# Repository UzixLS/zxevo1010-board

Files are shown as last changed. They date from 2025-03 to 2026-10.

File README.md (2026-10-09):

## ZXEVO.1010
10x10cm 2-layer PCB variant of [ZX Evolution](http://nedopc.com/zxevo/zxevo.php) project

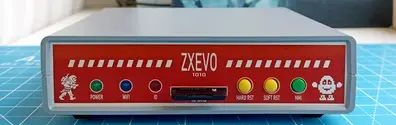
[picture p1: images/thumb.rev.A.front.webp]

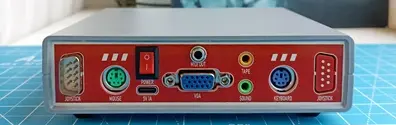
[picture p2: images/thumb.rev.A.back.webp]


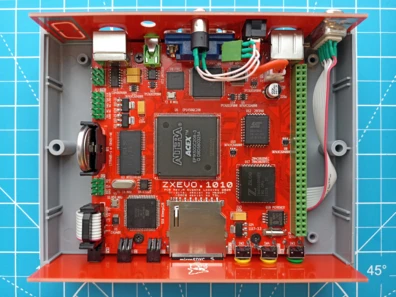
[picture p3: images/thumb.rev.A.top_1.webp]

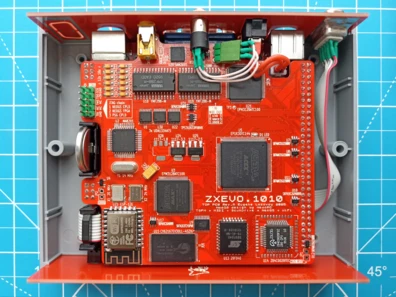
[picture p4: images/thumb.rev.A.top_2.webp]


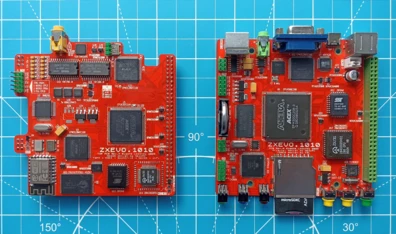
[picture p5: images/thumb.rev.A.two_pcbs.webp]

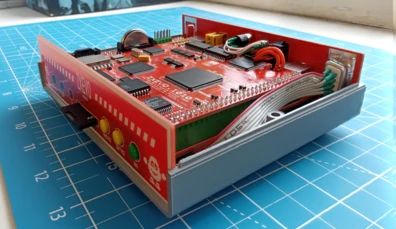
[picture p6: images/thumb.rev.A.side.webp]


Some random photos: [link](https://cloud.err200.net/index.php/s/73TR85tYZkMm8Ax?path=%2Fzxevo1010)

Tech specs:
- Fully compatible with ZX Evolution revC
- SD/microSD card slot
- PS/2 keyboard and mouse ports
- VGA video output
- VDAC2
- TSFM (mono output) powered by 2xYMF288
- [NeoGS](http://nedopc.com/gs/ngs.php)
- SounDrive (4-channel stereo covox)
- MIDI onboard synthesizer and output for external synthesizer
- WiFi ([ZiFi](http://zifi.vtrd.in/))
- RTC
- Tape input via 3.5 jack
- 1xDB-9 port for Sega-compatible joysticks
- USB Type C power supply
- Board optimized for G738 and G706 cases

### Changelog
#### Main PCB
* Rev.A - first release
* Rev.A1: - see [ERRATA](pcb_main/rev.A1/ERRATA.txt)!
    * enlarged ACEX's footprint
    * fixed IO led always on in baseconf - added C92 and D7
    * changed R66 from 390Ω to 2.2kΩ to reduce power led bightness
    * changed R52 and R58 from 27kΩ to 18kΩ for better VDAC2 mixing volume
    * slightly moved U18
    * some minor changes

#### Top PCB
* Rev.A - first release
* Rev.A1:
    * added 51Ω R1 and R3 on DAC and MP3 clock signals to fix signal integrity issues
    * changed U9 from SN74LXC8T245PWR (which is unsuitable) to 74LVC245APW
    * changed R7 from 120Ω to 1kΩ to decrease LED brightness
    * changed R26 and R29 from 8.2kΩ to 18kΩ for better NeoGS mixing volume
    * changed R23 and R31 from 22kΩ to 15kΩ for better MIDI mixing volume
    * changed R65, R66, R67 and R68 from 8.2kΩ to 3.3kΩ for better PSG mixing volume (but this makes FM a unbalancy loud unfortunatelly)
    * added R50, R51, R61, C102, C103, C104 for VS10xx MP3 decoder
    * fixed swapped left-right sound channels
    * increased cutoff for CR2032 holder

### Useful software
* NedoOS (BaseConf): http://nedoos.ru/
* Wild Commander (TSConf): https://forum.tslabs.info/viewtopic.php?f=26&t=143
* ZiFi WiFi client (TSConf): http://zifi.vtrd.in/
* TSConf software library: https://prods.tslabs.info/
* Joystick configuration utility (TSConf): https://github.com/tslabs/zx-evo/tree/master/pentevo/soft/avrconf

### References
* ZX Evolution official site: http://nedopc.com/zxevo/zxevo.php

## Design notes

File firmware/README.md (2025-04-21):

# Main PCB

## AVR firmware (for ISP programmer)
### Fuses
- low  - 0x3F
- high - 0x88
- ext  - 0xFF
- lock - 0xEF

### Bootloader
- zxevo_bl.hex - flash
- zxevo_bl.e2p - eeprom

Link: http://nedopc.com/zxevo/zxevo.php

## AVR firmware (for bootloader via USB/SD card)
### Test & Service
- zxevo_fw_tns_vdac2.bin

Link: https://github.com/tslabs/zx-evo/blob/master/pentevo/test_n_service/trunk/

### BaseConf + TSConf
- zxevo_fw_vdac2.bin

Link: https://github.com/tslabs/zx-evo/blob/master/pentevo/avr/current/default/

## ROM
### BaseConf
- zxevo_fe.rom

Link: http://nedopc.com/zxevo/zxevo.php

### TSConf
Install on top of BaseConf
- ts-bios.rom

Link: https://github.com/tslabs/zx-evo/tree/master/pentevo/rom/bin

## VDAC CPLD firmware
- ide-video.pof

Link: https://github.com/tslabs/zx-evo/blob/master/pentevo/vdac/vdac2/cpld/output_files/

# Top PCB
## NeoGS ROM
**Flash before soldering!**
- full_ngs.rom

Link: http://nedopc.com/gs/ngs.php

## NeoGS CPLD firmware
- GS_cpld_3064.pof - for EPM3064ATC100
- GS_cpld_3128.pof - for EPM3128ATC100

Link: http://nedopc.com/gs/ngs.php

## PSG CPLD firmware
- psg-sound.pof

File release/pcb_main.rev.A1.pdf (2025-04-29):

1 | 2 | 3 | 4 | 5 | 6 | 7 | 8 | 9 | 10 | 11 | 12

A

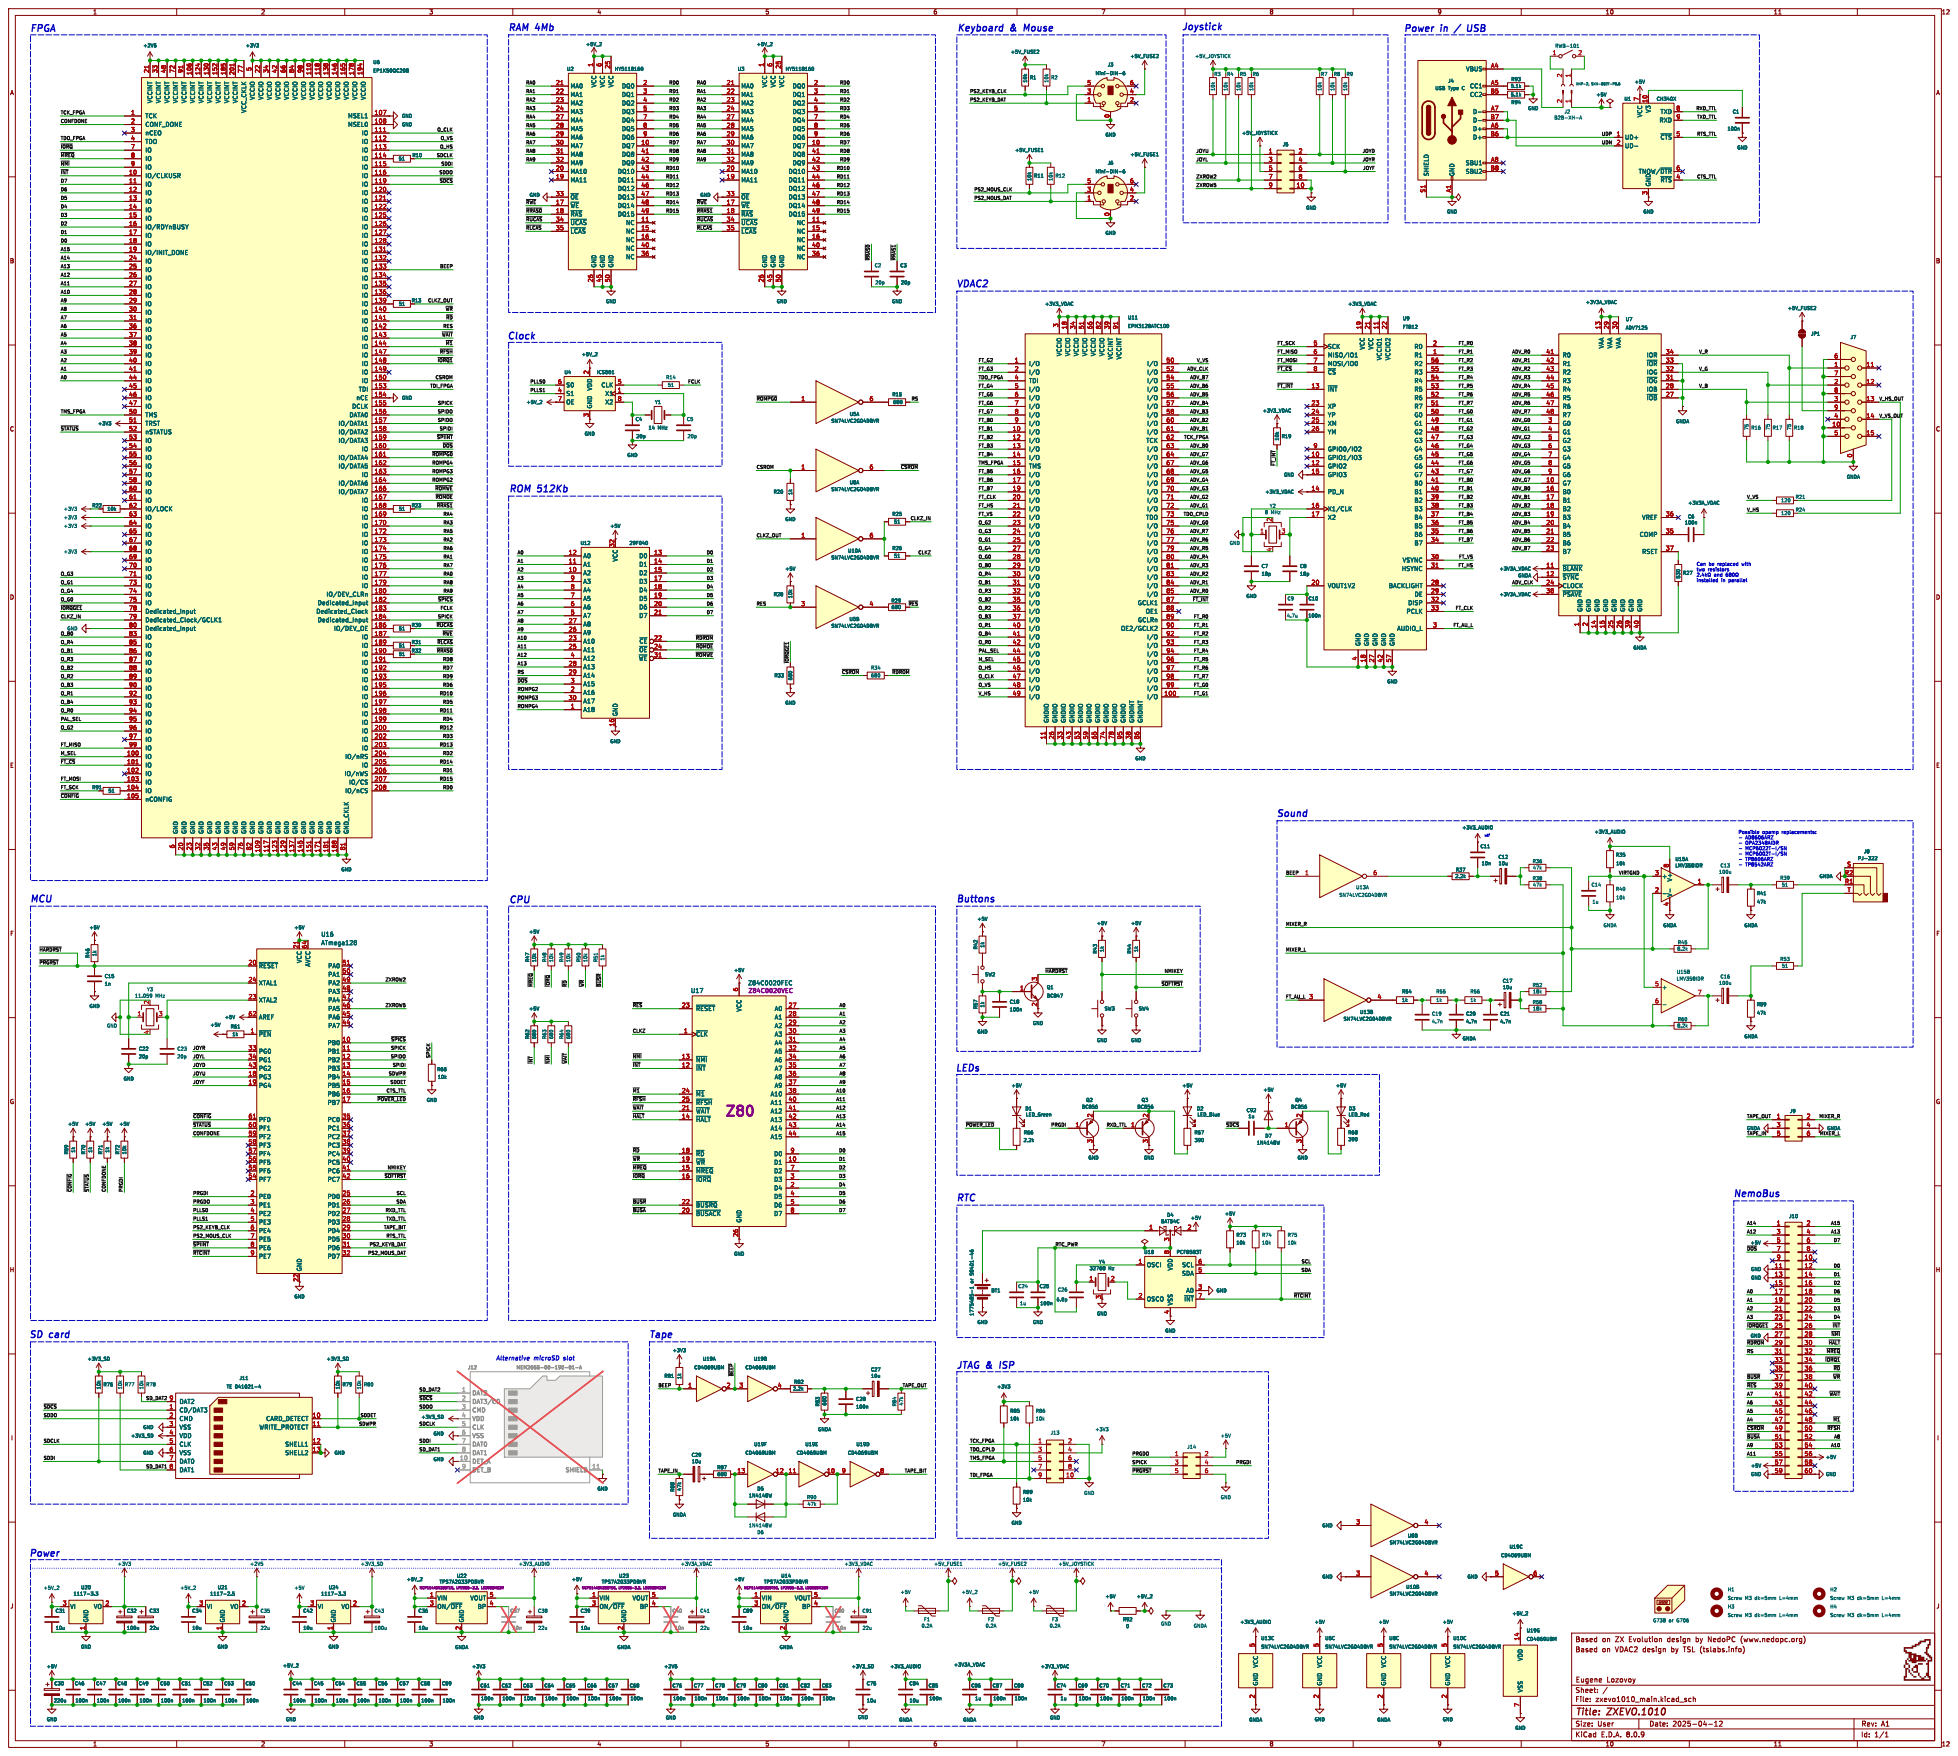
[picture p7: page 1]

1 DQ7 10 NC 11 NC 15 NC 16 ~{WE} 17 ~{RAS} 18 DQ0 2 MA0 21 MA1 22 MA2 23 MA3 24 VCC 25 GND 26 MA4 27 MA5 28 MA6 29 DQ1 3 MA7 30 MA8 31 MA9 32 ~{OE} 33 ~{UCAS} 34 ~{LCAS} 35 NC 36 DQ2 4 NC 40 DQ8 41 DQ9 42 DQ10 43 DQ11 44 GND 45 DQ12 46 DQ13 47 DQ14 48 DQ15 49 DQ3 5 GND 50 VCC

IO 200 VCCINT 201

IO 193 VCCIO ¹⁹⁴ IO 195

3 ~{RTS}4 ~{CTS}5 TNOW/~{DTR}6 VCC
RTS_TTL CTS_TTL

3 S1 4 CLK 5 S0 6 OE 7 X2 8 GND GND

two resistors þÿ2.4k©and þÿ680©

2 ON/~{OFF} 3 BP 4 VOUT 5 U22 TPS7A2033PDBVR

2 ON/~{OFF} 3 BP 4 VOUT 5 U23 TPS7A2033PDBVR

2 ON/~{OFF} 3 BP 4 VOUT 5 U14 TPS7A2033PDBVR

2 ON/~{OFF} 3 BP 4 VOUT 5 C39

2 ON/~{OFF} 3 BP 4 VOUT 5

1 | 2 | 3 | 4 | 5 | 6

A

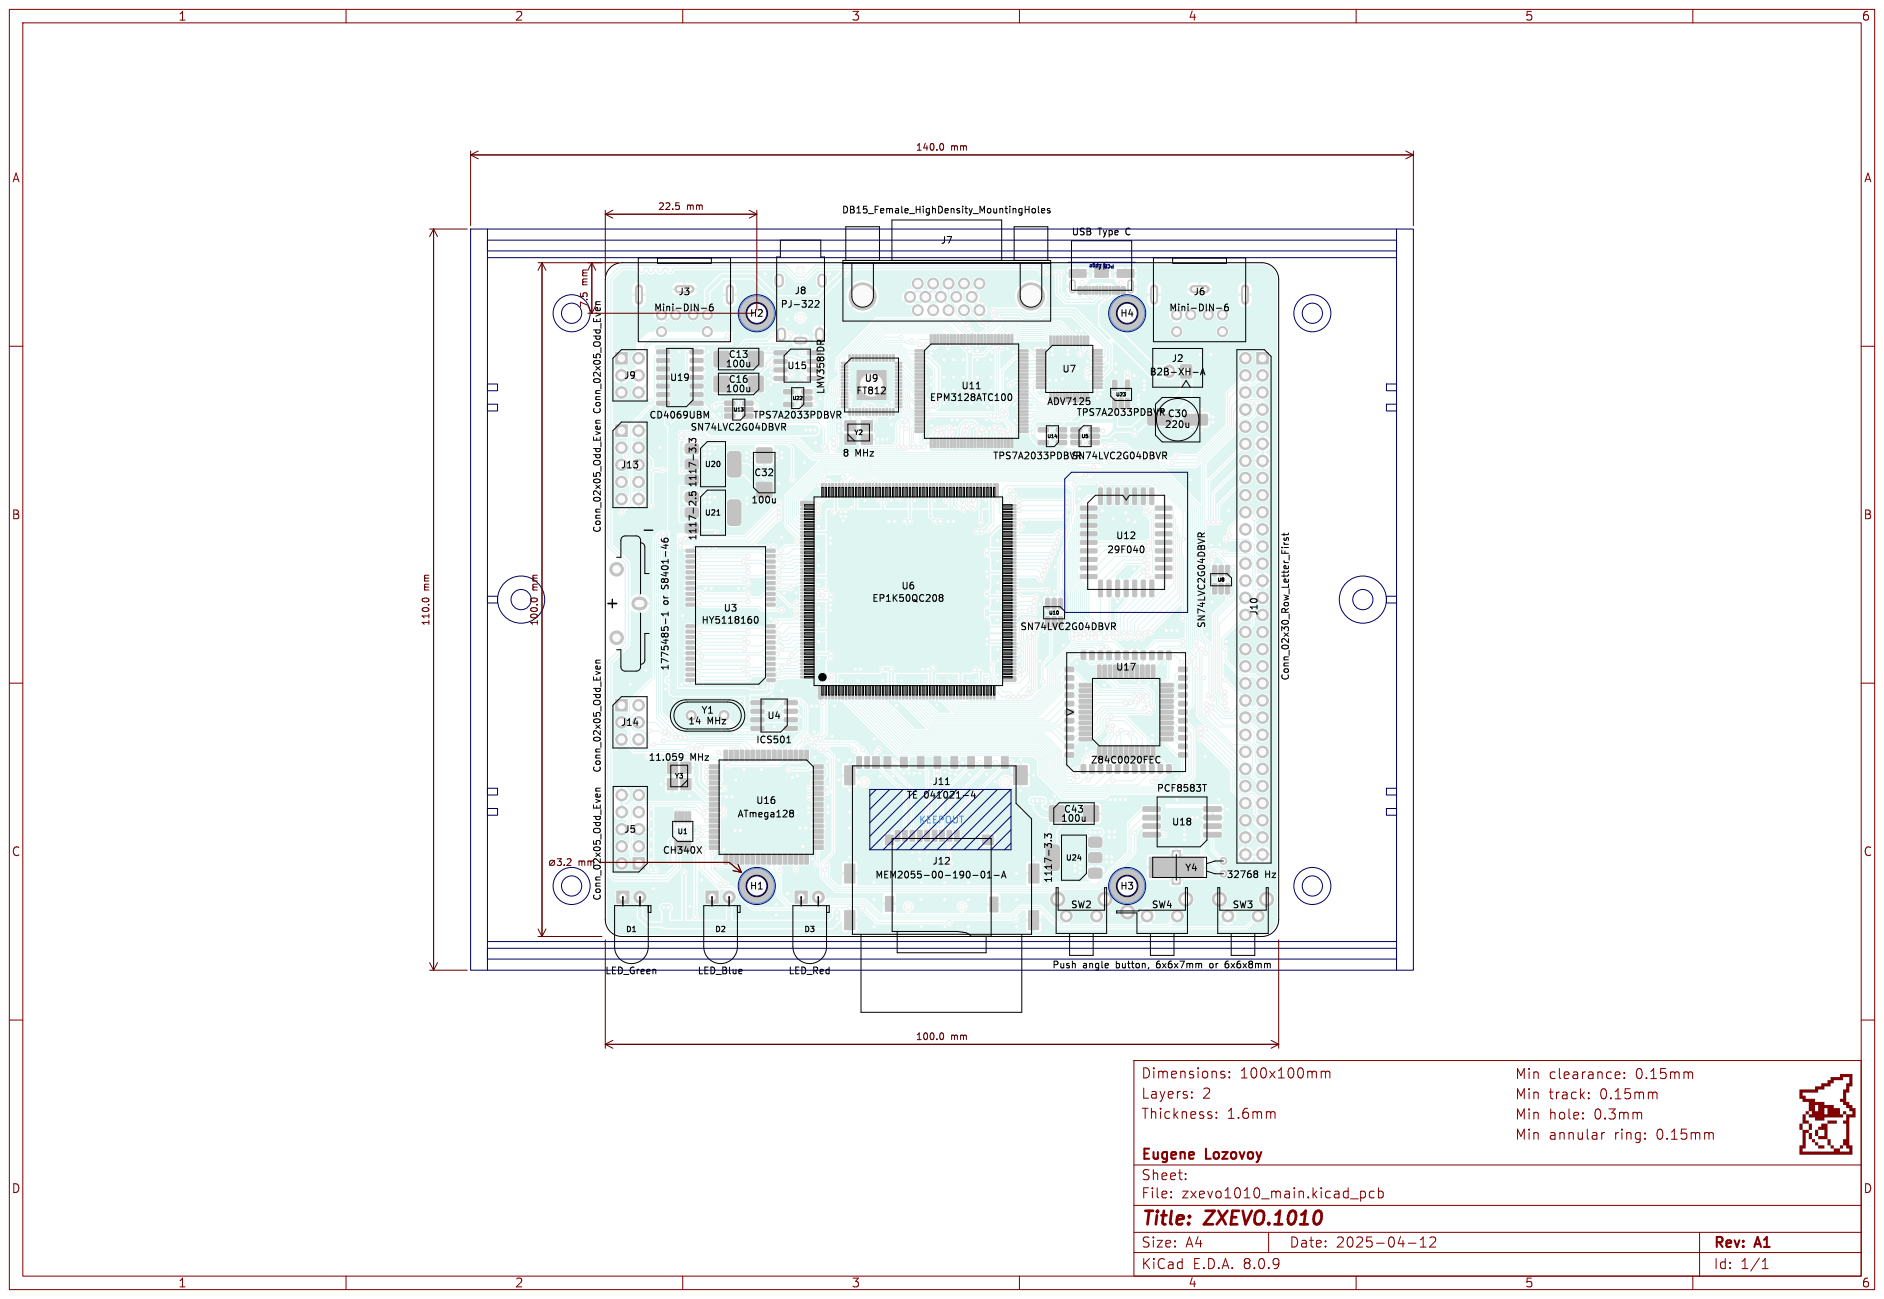
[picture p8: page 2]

J11 ¹⁷⁷⁵⁴⁸⁵⁻¹ or S⁸⁴⁰¹⁻⁴⁶

1 | 2 | 3 | 4 | 5 | 6

A

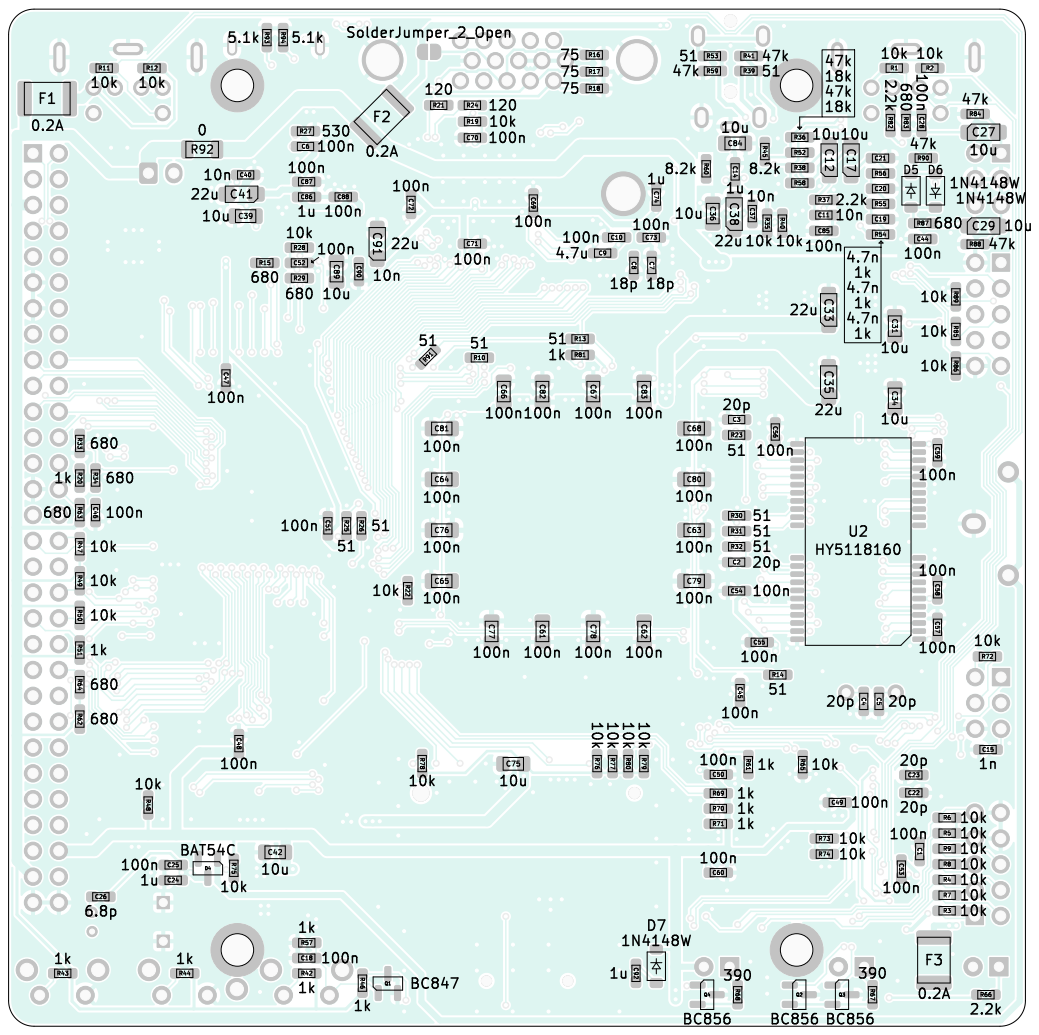
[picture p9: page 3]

# Bill Of Materials

References | | | Value | Footprint | Qty
BT1 | 1775485-1 or S8401-46 | my:CR2032V | 1
C1 C6 C10 C18 C25 C28 C44 C45 C46 C47 C48 C49 C50 C51 C52 C53 C54 C55 C56 C57 C58 C59 C60 C69 C70 C71 C72 C73 C85 C87 C88 | 100n | Capacitor_SMD:C_0603_1608Metric_Pad1.0 8x0.95mm_HandSolder | 31
C2 C3 C4 C5 C22 C23 | 20p | Capacitor_SMD:C_0603_1608Metric_Pad1.0 8x0.95mm_HandSolder | 6
C7 C8 | 18p | Capacitor_SMD:C_0603_1608Metric_Pad1.0 8x0.95mm_HandSolder | 2
C9 | 4.7u | Capacitor_SMD:C_0603_1608Metric_Pad1.0 8x0.95mm_HandSolder | 1
C11 C37 C40 C90 | 10n | Capacitor_SMD:C_0603_1608Metric_Pad1.0 8x0.95mm_HandSolder | 4
C12 C17 C27 C29 | 10u | Capacitor_Tantalum_SMD:CP_EIA-3216-18_ Kemet-A_Pad1.58x1.35mm_HandSolder | 4
C13 C16 C32 C43 | 100u | Capacitor_Tantalum_SMD:CP_EIA-6032-28_ Kemet-C_Pad2.25x2.35mm_HandSolder | 4
C14 C24 C74 C86 C92 | 1u | Capacitor_SMD:C_0603_1608Metric_Pad1.0 8x0.95mm_HandSolder | 5
C15 | 1n | Capacitor_SMD:C_0603_1608Metric_Pad1.0 8x0.95mm_HandSolder | 1
C19 C20 C21 | 4.7n | Capacitor_SMD:C_0603_1608Metric_Pad1.0 8x0.95mm_HandSolder | 3
C26 | 6.8p | Capacitor_SMD:C_0603_1608Metric_Pad1.0 8x0.95mm_HandSolder | 1
C30 | 220u | Capacitor_SMD:CP_Elec_6.3x7.7 | 1
C31 C34 C36 C39 C42 C75 C84 C89 | 10u | Capacitor_SMD:C_0805_2012Metric_Pad1.1 8x1.45mm_HandSolder | 8
C33 C35 C38 C41 C91 | 22u | Capacitor_Tantalum_SMD:CP_EIA-3216-18_ Kemet-A_Pad1.58x1.35mm_HandSolder | 5
C61 C62 C63 C64 C65 C66 C67 C68 C76 C77 C78 C79 C80 C81 C82 C83 | 100n | Capacitor_SMD:C_0805_2012Metric_Pad1.1 8x1.45mm_HandSolder | 16
D1 | LED_Green | LED_THT:LED_D5.0mm_Horizontal_O1.27m m_Z3.0mm | 1
D2 | LED_Blue | LED_THT:LED_D5.0mm_Horizontal_O1.27m m_Z3.0mm | 1
D3 | LED_Red | LED_THT:LED_D5.0mm_Horizontal_O1.27m m_Z3.0mm | 1
D4 | BAT54C | Package_TO_SOT_SMD:SOT-23 | 1
D5 D6 D7 | 1N4148W | Diode_SMD:D_SOD-123 | 3
F1 F2 F3 | 0.2A | Fuse:Fuse_1812_4532Metric_Pad1.30x3.40 mm_HandSolder | 3
H1 H2 H3 H4 | Screw M3 dk=5mm L=4mm | my:MountingHole_3.2mm_M3_dk5.2mm_Ma sk | 4
J1 | XHP-2, SXH-002T-P0.6 | | 1

# zxevo1010_main rev.A1 BOM page 1/3

J2 | B2B-XH-A | Connector_JST:JST_XH_B2B-XH-A_1x02_P 2.50mm_Vertical | 1
J3 J6 | Mini-DIN-6 | my:minidin-6 | 2
J4 | USB Type C | my:USB_C_Receptacle_HRO_TYPE-C-31-M -12_dangling | 1
J5 J13 | Conn_02x05_Odd_Even | Connector_PinHeader_2.54mm:PinHeader_2 x05_P2.54mm_Vertical | 2
J7 | DB15_Female_HighDensity_Mounti ngHoles | Connector_Dsub:DSUB-15-HD_Female_Hori zontal_P2.29x1.98mm_EdgePinOffset3.03m m_Housed_MountingHolesOffset4.94mm | 1
J8 | PJ-322 | my:PJ-322 | 1
J9 J14 | Conn_02x05_Odd_Even | Connector_PinHeader_2.54mm:PinHeader_2 x03_P2.54mm_Vertical | 2
J10 | Conn_02x30_Row_Letter_First | Connector_PinSocket_2.54mm:PinSocket_2x 30_P2.54mm_Vertical | 1
J11 | TE 041021-4 | my:SD_TE_2041021-mod | 1
N1 | G738 or G706 | my:g738-g706 | 1
Q1 | BC847 | Package_TO_SOT_SMD:SOT-23 | 1
Q2 Q3 Q4 | BC856 | Package_TO_SOT_SMD:SOT-23 | 3
R1 R2 R3 R4 R5 R6 R7 R8 R9 R11 R12 R19 R22 R28 R35 R40 R47 R48 R49 R50 R65 R72 R73 R74 R75 R76 R77 R78 R79 R80 R85 R86 R89 | 10k | Resistor_SMD:R_0603_1608Metric_Pad0.98 x0.95mm_HandSolder | 33
R10 R13 R14 R23 R25 R26 R30 R31 R32 R39 R53 R91 | 51 | Resistor_SMD:R_0603_1608Metric_Pad0.98 x0.95mm_HandSolder | 12
R15 R29 R33 R34 R62 R63 R64 R83 R87 | 680 | Resistor_SMD:R_0603_1608Metric_Pad0.98 x0.95mm_HandSolder | 9
R16 R17 R18 | 75 | Resistor_SMD:R_0603_1608Metric_Pad0.98 x0.95mm_HandSolder | 3
R20 R42 R43 R44 R46 R51 R54 R55 R56 R57 R61 R69 R70 R71 R81 | 1k | Resistor_SMD:R_0603_1608Metric_Pad0.98 x0.95mm_HandSolder | 15
R21 R24 | 120 | Resistor_SMD:R_0603_1608Metric_Pad0.98 x0.95mm_HandSolder | 2
R27 | 530 | Resistor_SMD:R_0603_1608Metric_Pad0.98 x0.95mm_HandSolder | 1
R36 R38 R41 R59 R84 R88 R90 | 47k | Resistor_SMD:R_0603_1608Metric_Pad0.98 x0.95mm_HandSolder | 7
R37 R66 R82 | 2.2k | Resistor_SMD:R_0603_1608Metric_Pad0.98 x0.95mm_HandSolder | 3
R45 R60 | 8.2k | Resistor_SMD:R_0603_1608Metric_Pad0.98 x0.95mm_HandSolder | 2
R52 R58 | 18k | Resistor_SMD:R_0603_1608Metric_Pad0.98 x0.95mm_HandSolder | 2
R67 R68 | 390 | Resistor_SMD:R_0603_1608Metric_Pad0.98 x0.95mm_HandSolder | 2
R92 | 0 | Resistor_SMD:R_1206_3216Metric | 1
R93 R94 | 5.1k | Resistor_SMD:R_0603_1608Metric_Pad0.98 x0.95mm_HandSolder | 2
SW1 | RWB-101 | | 1

# zxevo1010_main rev.A1 BOM page 2/3

SW2 SW3 SW4 | Push angle button, 6x6x7mm or 6x6x8mm | Button_Switch_THT:SW_Tactile_SPST_Angl ed_PTS645Vx58-2LFS | 3
U1 | CH340X | Package_SO:MSOP-10_3x3mm_P0.5mm | 1
U2 U3 | HY5118160 | my:TSOP-II-44-50_P0.8mm | 2
U4 | ICS501 | Package_SO:SOIC-8_3.9x4.9mm_P1.27mm | 1
U5 U8 U10 U13 | SN74LVC2G04DBVR | Package_TO_SOT_SMD:SOT-23-6_Handsol dering | 4
U6 | EP1K50QC208 | my:PQFP-208_28x28mm_P0.5mm_LongPad s | 1
U7 | ADV7125 | Package_QFP:TQFP-48_7x7mm_P0.5mm | 1
U9 | FT812 | my:QFN-56-1EP_8x8mm_P0.5mm_EP4.3x4. 3mm | 1
U11 | EPM3128ATC100 | Package_QFP:TQFP-100_14x14mm_P0.5m m | 1
U12 | 29F040 | my:PLCC-32_11.4x14.0mm_P1.27mm-longp ads | 1
U14 U22 U23 | TPS7A2033PDBVR (Alternatives: NCP114ASN330T1G, LP2985-3.3, LD3985M33R) | Package_TO_SOT_SMD:SOT-23-5_HandSo ldering | 3
U15 | LMV358IDR | Package_SO:SOIC-8_3.9x4.9mm_P1.27mm | 1
U16 | ATmega128 | Package_QFP:TQFP-64_14x14mm_P0.8mm | 1
U17 | Z84C0020FEC (Alternatives: Z84C0020VEC) | my:Z80_FEC_VEC | 1
U18 | PCF8583T | my:SOT176-1 | 1
U19 | CD4069UBM | Package_SO:SO-14_3.9x8.65mm_P1.27mm | 1
U20 U24 | 1117-3.3 | Package_TO_SOT_SMD:SOT-223-3_TabPin 2 | 2
U21 | 1117-2.5 | Package_TO_SOT_SMD:SOT-223-3_TabPin 2 | 1
Y1 | 14 MHz | Crystal:Crystal_HC49-4H_Vertical | 1
Y2 | 8 MHz | my:Crystal_SMD_3225-4Pin_3.2x2.5mm_Ha ndSoldering | 1
Y3 | 11.059 MHz | my:Crystal_SMD_3225-4Pin_3.2x2.5mm_Ha ndSoldering | 1
Y4 | 32768 Hz | Crystal:Crystal_C38-LF_D3.0mm_L8.0mm_H orizontal_1EP_style2 | 1

# zxevo1010_main rev.A1 BOM page 3/3

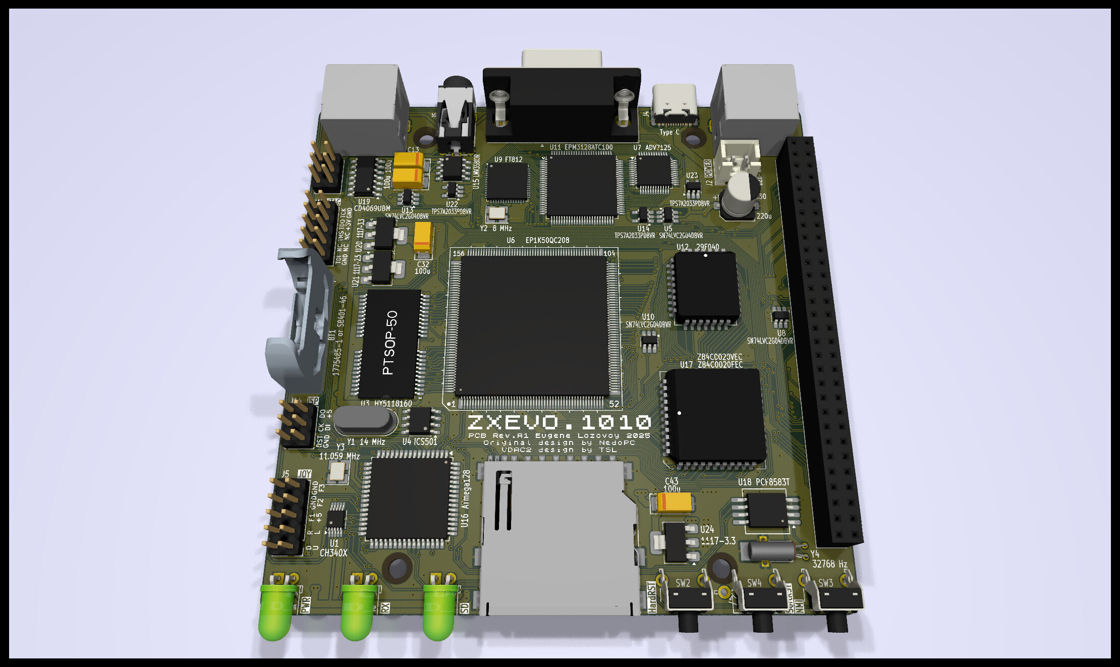
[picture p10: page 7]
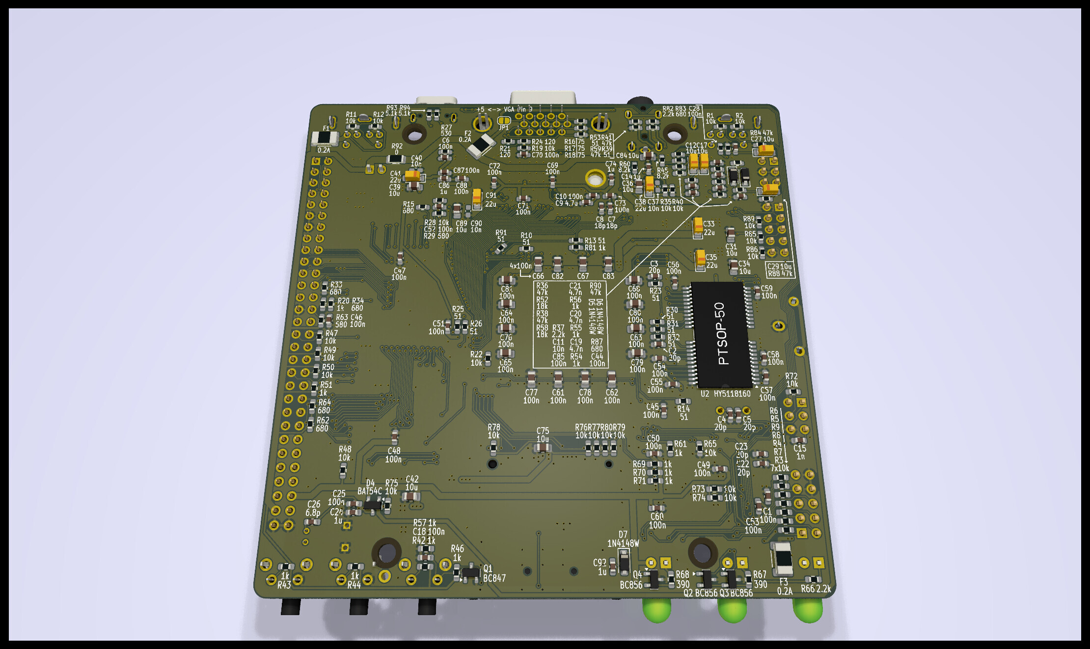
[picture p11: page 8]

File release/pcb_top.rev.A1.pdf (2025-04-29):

1 | 2 | 3 | 4 | 5 | 6 | 7 | 8 | 9 | 10

A

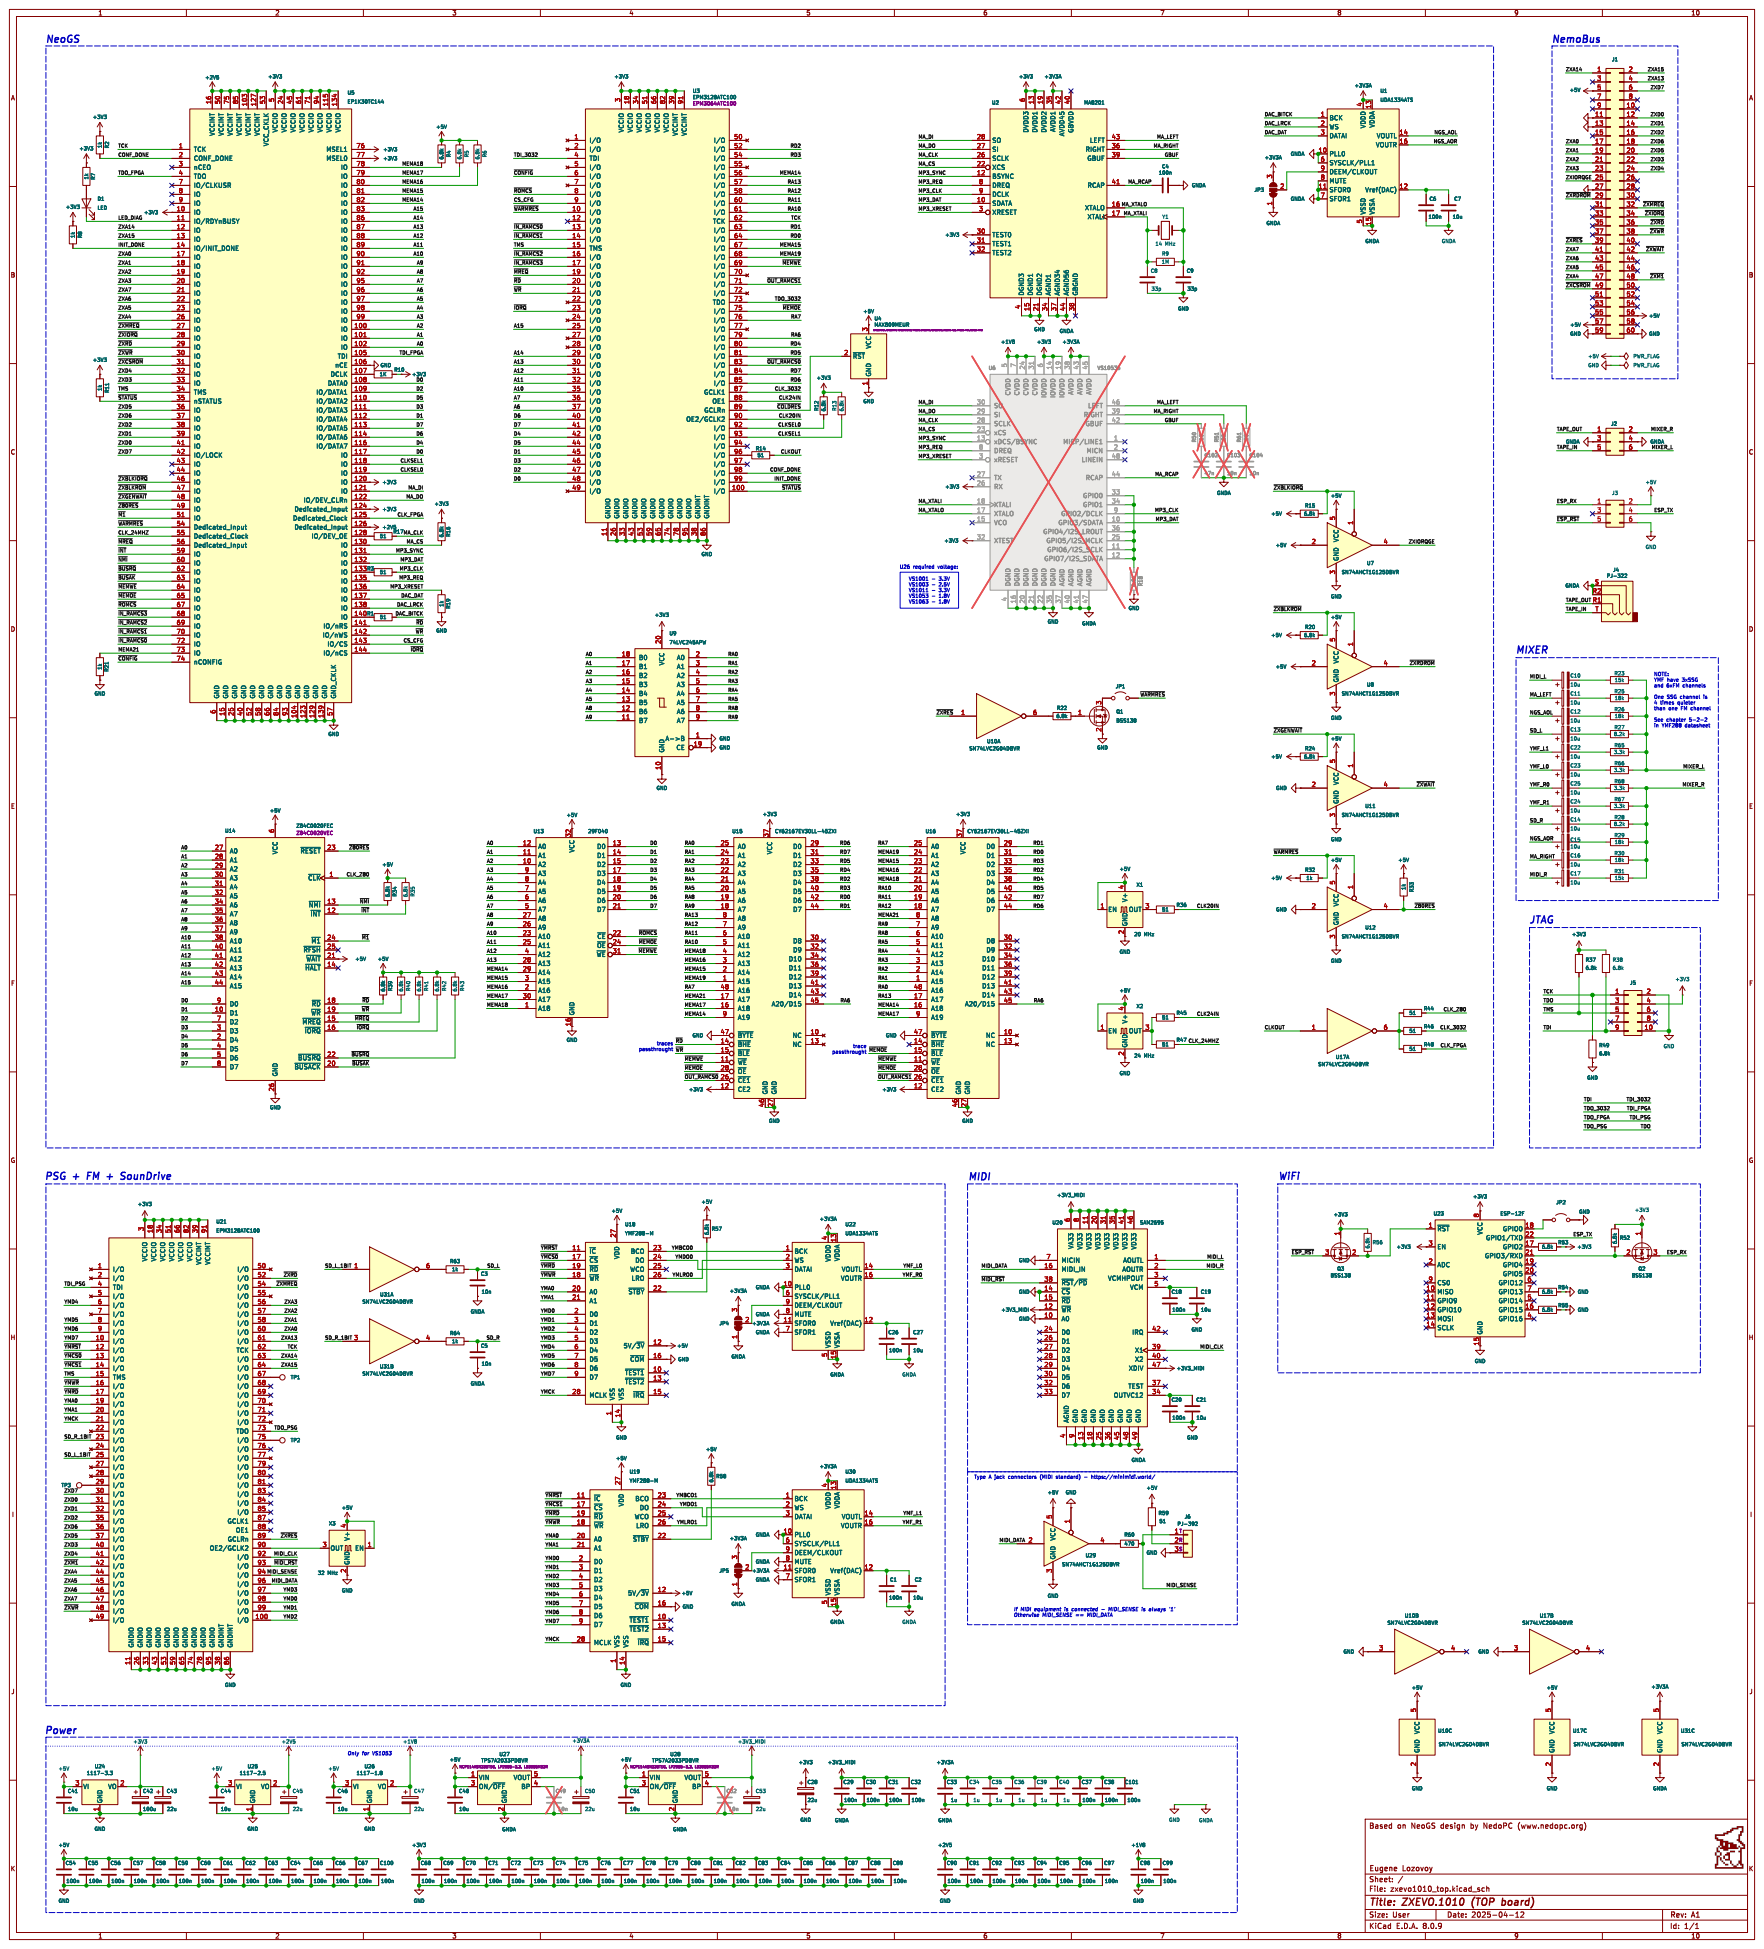
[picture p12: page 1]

RD5 CLKSEL0 ~{MEMWE} ~{INT} ~{BUSAK} ~{BUSRQ} ~{NMI}

7 DREQ 8 GPIO2/DCLK 9 U6 VS1053b GND GND

4 AGND 40 AGND 41 GBUF 42 AVDD 43 RCAP 44 AVDD 45 LEFT 46 AGND 47

6 D2 7 D7 8 D0 9 U15 CY62167EV30LL-45ZXI A15 1 NC 10 ~{WE} 11 CE2 12 NC 13 ~{BHE} 14 ~{BLE} 15 A18 16 A17 17 A7 18 A6 19 A14 2 A5 20 A4 21 A3 22 A2 23 A1 24 A0 25 ~{CE1} 26 GND 27
10n ⁶.8k R³⁵

TDO_FPGA CLK_FPGA
6.8k GND GND ~{RST} 1 MISO

5 SYSCLK/PLL1 6 SFOR1 7 MUTE 8 DEEM/CLKOUT 9 U22 UDA1334ATS C27

5 SYSCLK/PLL1 6 SFOR1 7 MUTE 8 DEEM/CLKOUT 9 C27

5 SYSCLK/PLL1 6 SFOR1 7 MUTE 8 DEEM/CLKOUT 9 U30 UDA1334ATS

5 SYSCLK/PLL1 6 SFOR1 7 MUTE 8 DEEM/CLKOUT 9

2 ON/~{OFF} 3 BP 4 VOUT 5 U27 TPS7A2033PDBVR

2 ON/~{OFF} 3 BP 4 VOUT 5 U28 TPS7A2033PDBVR

2 ON/~{OFF} 3 BP 4 VOUT 5 GNDA C48

2 ON/~{OFF} 3 BP 4 VOUT 5 GNDA C51

1 | 2 | 3 | 4 | 5 | 6

A

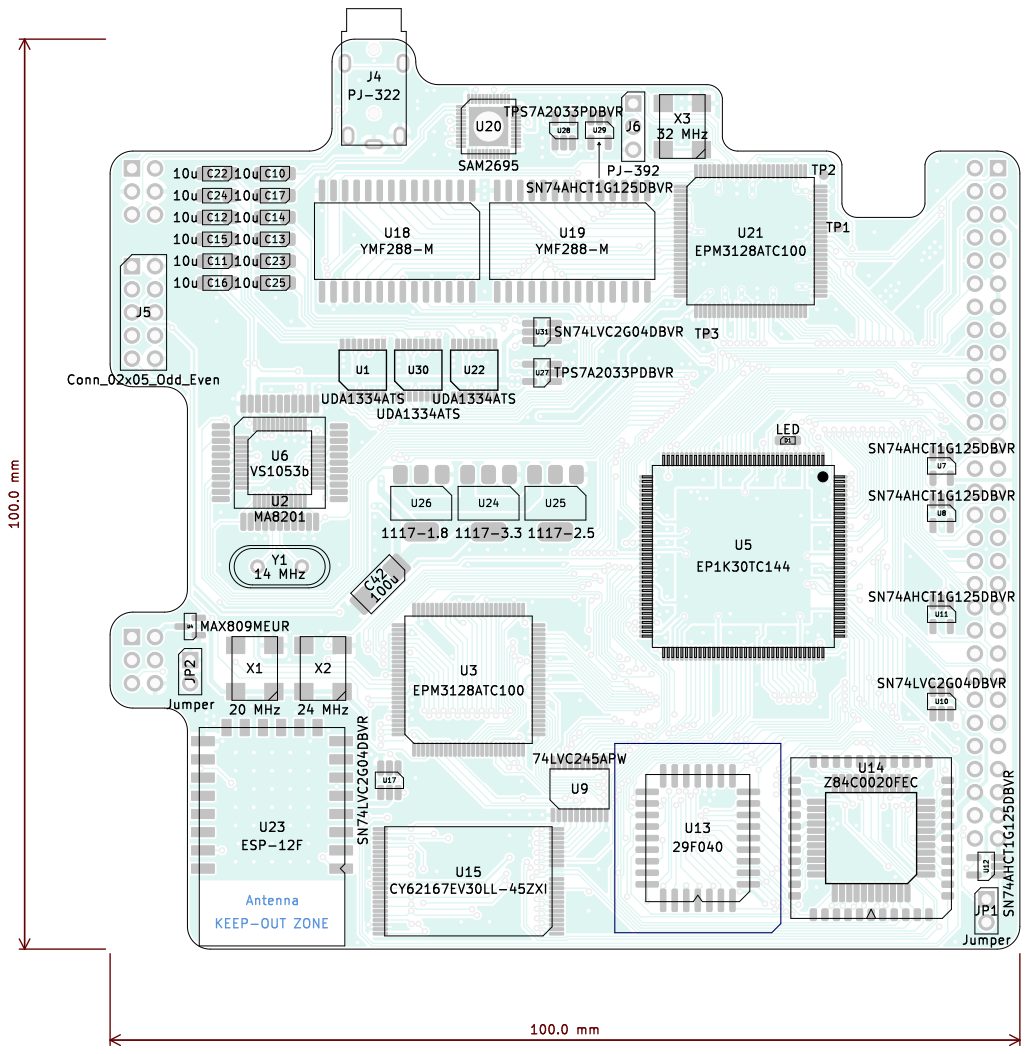
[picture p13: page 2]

24 MHz X2 KEEP-OUT ZONE

1 | 2 | 3 | 4 | 5 | 6

A

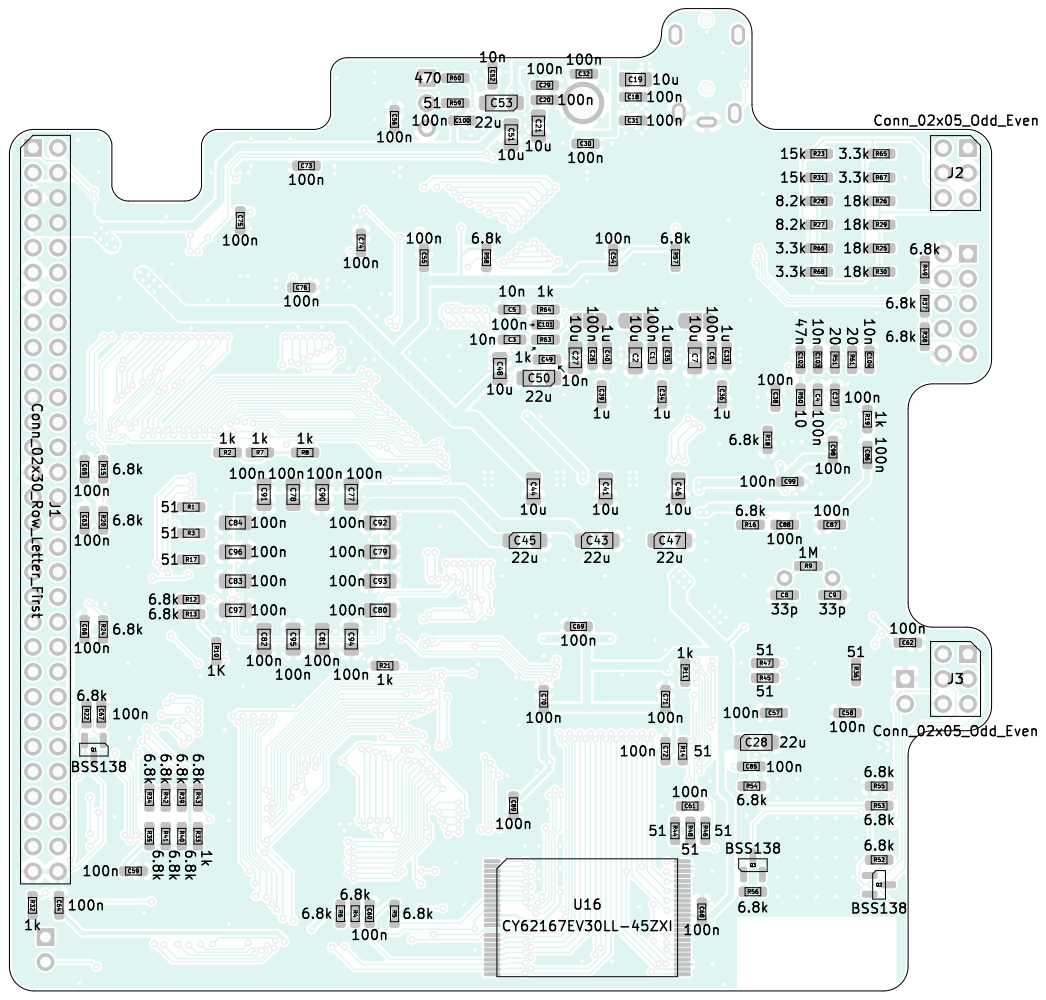
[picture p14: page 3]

# Bill Of Materials

References | | | Value | Footprint | Qty
C1 C4 C6 C18 C20 C26 C29 C30 C31 C32 C37 C38 C54 C55 C56 C57 C58 C59 C60 C61 C62 C63 C64 C65 C66 C67 C68 C69 C70 C71 C72 C73 C74 C75 C76 C85 C86 C87 C88 C89 C98 C99 C100 C101 | 100n | Capacitor_SMD:C_0603_1608Metric_Pad1.0 8x0.95mm_HandSolder | 44
C2 C7 C19 C21 C27 C41 C44 C46 C48 C51 | 10u | Capacitor_SMD:C_0805_2012Metric_Pad1.1 8x1.45mm_HandSolder | 10
C3 C5 C49 C52 C103 C104 | 10n | Capacitor_SMD:C_0603_1608Metric_Pad1.0 8x0.95mm_HandSolder | 6
C8 C9 | 33p | Capacitor_SMD:C_0603_1608Metric_Pad1.0 8x0.95mm_HandSolder | 2
C10 C11 C12 C13 C14 C15 C16 C17 C22 C23 C24 C25 | 10u | Capacitor_Tantalum_SMD:CP_EIA-3216-18_ Kemet-A_Pad1.58x1.35mm_HandSolder | 12
C28 C43 C45 C47 C50 C53 | 22u | Capacitor_Tantalum_SMD:CP_EIA-3216-18_ Kemet-A_Pad1.58x1.35mm_HandSolder | 6
C33 C34 C35 C36 C39 C40 | 1u | Capacitor_SMD:C_0603_1608Metric_Pad1.0 8x0.95mm_HandSolder | 6
C42 | 100u | Capacitor_Tantalum_SMD:CP_EIA-6032-28_ Kemet-C_Pad2.25x2.35mm_HandSolder | 1
C77 C78 C79 C80 C81 C82 C83 C84 C90 C91 C92 C93 C94 C95 C96 C97 | 100n | Capacitor_SMD:C_0805_2012Metric_Pad1.1 8x1.45mm_HandSolder | 16
C102 | 47n | Capacitor_SMD:C_0603_1608Metric_Pad1.0 8x0.95mm_HandSolder | 1
D1 | LED | LED_SMD:LED_0603_1608Metric_Pad1.05x 0.95mm_HandSolder | 1
J1 | Conn_02x30_Row_Letter_First | Connector_PinHeader_2.54mm:PinHeader_2 x30_P2.54mm_Vertical | 1
J2 J3 | Conn_02x05_Odd_Even | Connector_PinSocket_2.54mm:PinSocket_2x 03_P2.54mm_Vertical | 2
J4 | PJ-322 | my:PJ-322 | 1
J5 | Conn_02x05_Odd_Even | Connector_PinHeader_2.54mm:PinHeader_2 x05_P2.54mm_Vertical | 1
J6 | PJ-392 | Connector_PinHeader_2.54mm:PinHeader_1 x03_P2.54mm_Vertical | 1
Q1 Q2 Q3 | BSS138 | Package_TO_SOT_SMD:SOT-23 | 3
R1 R3 R14 R17 R36 R44 R45 R46 R47 R48 R59 | 51 | Resistor_SMD:R_0603_1608Metric_Pad0.98 x0.95mm_HandSolder | 11
R2 R7 R8 R11 R19 R21 R32 R33 R63 R64 | 1k | Resistor_SMD:R_0603_1608Metric_Pad0.98 x0.95mm_HandSolder | 10
R4 R5 R6 R12 R13 R15 R16 R18 R20 R22 R24 R34 R35 R37 R38 R39 R40 R41 R42 R43 R49 R52 R53 R54 R55 R56 R57 R58 | 6.8k | Resistor_SMD:R_0603_1608Metric_Pad0.98 x0.95mm_HandSolder | 28
R9 | 1M | Resistor_SMD:R_0603_1608Metric_Pad0.98 x0.95mm_HandSolder | 1
R10 | 1K | Resistor_SMD:R_0603_1608Metric_Pad0.98 x0.95mm_HandSolder

# zxevo1010_top rev.A1 BOM page 1/3

R23 R31 | 15k | Resistor_SMD:R_0603_1608Metric_Pad0.98 x0.95mm_HandSolder
R25 R26 R29 R30 | 18k | Resistor_SMD:R_0603_1608Metric_Pad0.98 x0.95mm_HandSolder
R27 R28 | 8.2k | Resistor_SMD:R_0603_1608Metric_Pad0.98 x0.95mm_HandSolder | 2
R50 | 10 | Resistor_SMD:R_0603_1608Metric_Pad0.98 x0.95mm_HandSolder | 1
R51 R61 | 20 | Resistor_SMD:R_0603_1608Metric_Pad0.98 x0.95mm_HandSolder | 2
R60 | 470 | Resistor_SMD:R_0603_1608Metric_Pad0.98 x0.95mm_HandSolder | 1
R65 R66 R67 R68 | 3.3k | Resistor_SMD:R_0603_1608Metric_Pad0.98 x0.95mm_HandSolder | 4
U1 U22 U30 | UDA1334ATS | Package_SO:SSOP-16_4.4x5.2mm_P0.65m m | 3
U2 | MA8201 | Package_QFP:MQFP-44_10x10mm_P0.8m m | 1
U3 U21 | EPM3128ATC100 (Alternatives: EPM3064ATC100) | Package_QFP:TQFP-100_14x14mm_P0.5m m | 2
U4 | MAX809MEUR (Alternatives: STM809MWX6F, ADM809MART, TCM809MENB713, TPV809M, CAT809MTBI, CBM809MST3, LM809M3-4.38, APX809S-44SA, SGM809-MXN3) | Package_TO_SOT_SMD:SOT-23 | 1
U5 | EP1K30TC144 | PCM_Package_QFP_AKL:TQFP-144_20x20 mm_P0.5mm | 1
U6 | VS1053b (Alternatives: VS1001, VS1003, VS1011, VS1063) | Package_QFP:LQFP-48_7x7mm_P0.5mm | 1
U7 U8 U11 U12 U29 | SN74AHCT1G125DBVR | Package_TO_SOT_SMD:SOT-23-5_HandSo ldering | 5
U9 | 74LVC245APW | Package_SO:TSSOP-20_4.4x6.5mm_P0.65 mm | 1
U10 U17 U31 | SN74LVC2G04DBVR | Package_TO_SOT_SMD:SOT-23-6_Handsol dering | 3
U13 | 29F040 | my:PLCC-32_11.4x14.0mm_P1.27mm-longp ads | 1
U14 | Z84C0020FEC (Alternatives: Z84C0020VEC) | my:Z80_FEC_VEC | 1
U15 U16 | CY62167EV30LL-45ZXI | Package_SO:TSOP-I-48_18.4x12mm_P0.5m m | 2
U18 U19 | YMF288-M | Package_SO:SOP-28_8.4x18.16mm_P1.27 mm | 2
U20 | SAM2695 | my:QFN-48-1EP_6x6mm_P0.4mm_EP4.2x4. 2mm | 1
U23 | ESP-12F | RF_Module:ESP-12E | 1
U24 | 1117-3.3 | Package_TO_SOT_SMD:SOT-223-3_TabPin 2 | 1
U25 | 1117-2.5 | Package_TO_SOT_SMD:SOT-223-3_TabPin 2 | 1
U26 | 1117-1.8 | Package_TO_SOT_SMD:SOT-223-3_TabPin

# zxevo1010_top rev.A1 BOM page 2/3

U27 U28 | TPS7A2033PDBVR (Alternatives: NCP114ASN330T1G, LP2985-3.3, LD3985M33R) | Package_TO_SOT_SMD:SOT-23-5_HandSo ldering
X1 | 20 MHz | my:Oscillator_SMD_7050_7.0x5.0mm | 1
X2 | 24 MHz | my:Oscillator_SMD_7050_7.0x5.0mm | 1
X3 | 32 MHz | my:Oscillator_SMD_7050_7.0x5.0mm | 1
Y1 | 14 MHz | Crystal:Crystal_HC49-4H_Vertical | 1

# zxevo1010_top rev.A1 BOM page 3/3

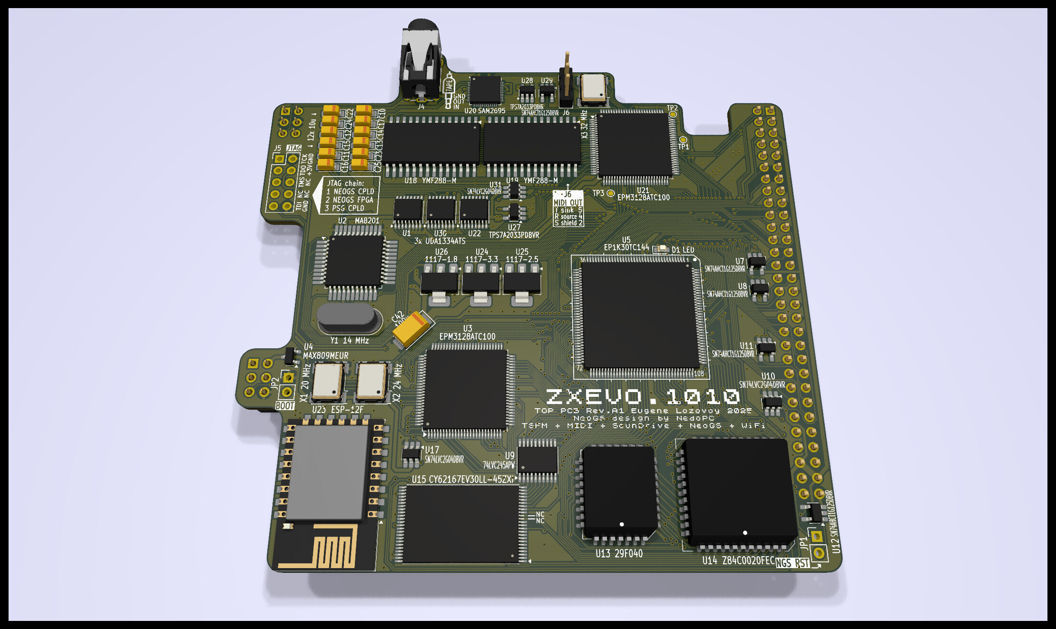
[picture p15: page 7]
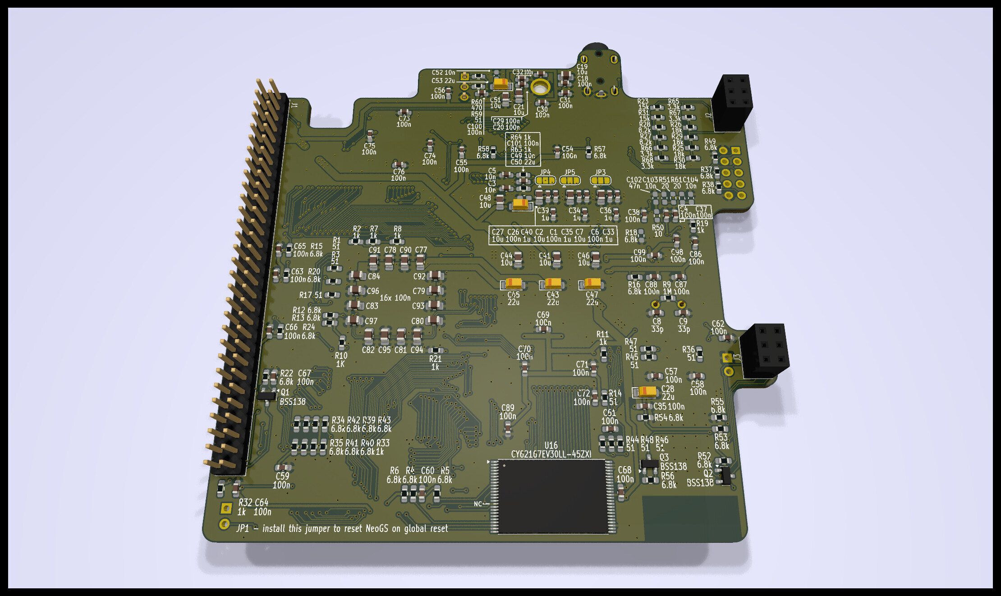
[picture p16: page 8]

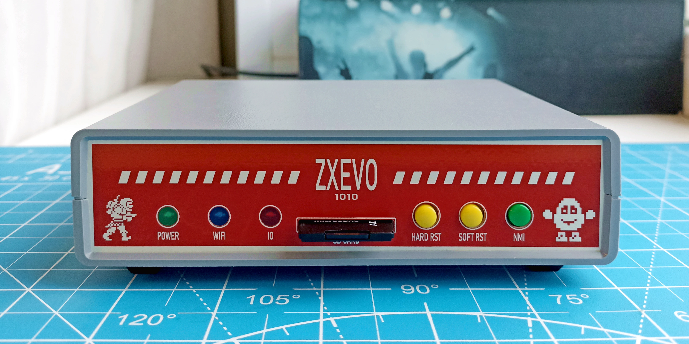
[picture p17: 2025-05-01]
images/rev.A.front.webp

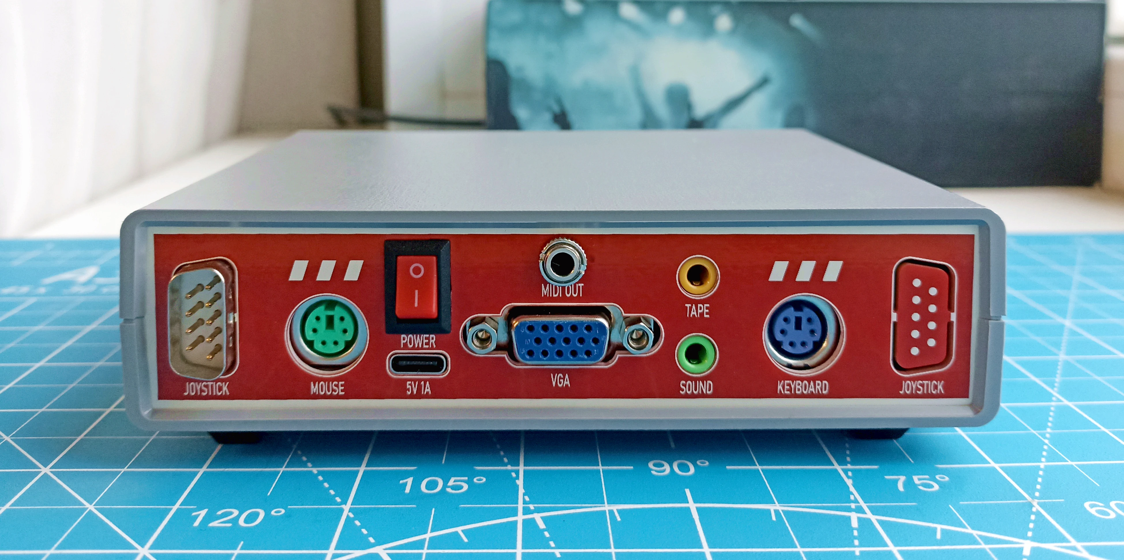
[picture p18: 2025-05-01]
images/rev.A.back.webp

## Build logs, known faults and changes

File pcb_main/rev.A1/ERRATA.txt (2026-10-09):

- Add 4.7 kΩ resistor between pins 2 and 3 of U13 (74LVC2G04) to fix audio noise.

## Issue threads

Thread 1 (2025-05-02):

YMF288

NS-Clone, 2025-05-02:
тааак
вангую что мы получили еще один вариант TSFM-а...

яж надеюсь ты тупо не выкинул 6 каналов от 2608 итд?
хотя можно было перехватить запись и проимитировать 2х 2203 и на одном ymf288...

чего там получаетсо с выбором второй половины чипа?

чего с этим пином для выбора 2608\288
и чего оно делаит хоть?

я так понимаю adpcm drums на 288 набортные без внешнего рома?

и еще один феил это балансировка sgg и fm частей
которая не будет соответствовать tsfm-ной
и теперь в плееры надо будет завозить дополнительный вариант 288-й балансировки громкостей

нам даже картинку нарисовали в датащитте
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

...
или может есть возможность отлавливать ssg каналы идующие на dac?
ты подключил dac-и на прямую?
или пропустил их через фпга?

UzixLS, 2025-05-02:
Все ответы есть в схеме и исходниках.
Баланс ssg/fm в этих чипах действительно кривой, любой вариант решения будет компромиссом. Компромисс который выбрал я - выравнивать громкость по ssg и забить на fm.

NS-Clone, 2025-05-02:
> Все ответы есть в схеме и исходниках.

а потом железятники жалуютсо что им софты никто не пишот

UzixLS, 2025-05-02:
Рулить как обычным TSFM.
YMF288 с т.з. пользователя отличается от 2203 только кривым балансом, моно выходом SSG и дополнительными никому не нужными фичами.

NS-Clone, 2025-05-02:
> отличается от 2203

ага
и вторым набором регистров по тем же адресам

NS-Clone, 2025-05-02:
а утя есть этот пылесос на ходу
могу перекинуть запись в теперь существующие регистры в s98 плеере
и убрать подгон громкости под тсфм
можно будет послушать есть ли там adpcm drums
и глянуть будет ли похожа балансировка на pc98

NS-Clone, 2025-05-02:
> любой вариант решения будет компромиссом

хммм
там же наверно все эти каналы выплевываютсо поочередно
а сам ум-ка стерео
потенциально можно поймать в каких "каналах" одна и та же громкость
и кинуть их в другой цап
или же умножить громкость свдигом
но это конечно там будет городуха

NS-Clone, 2025-05-02:
не менее интересный момент
что тут ssg с цифровым выходом
и у него там явно свой невиданный нам набор ssg ступенек громкостей :)

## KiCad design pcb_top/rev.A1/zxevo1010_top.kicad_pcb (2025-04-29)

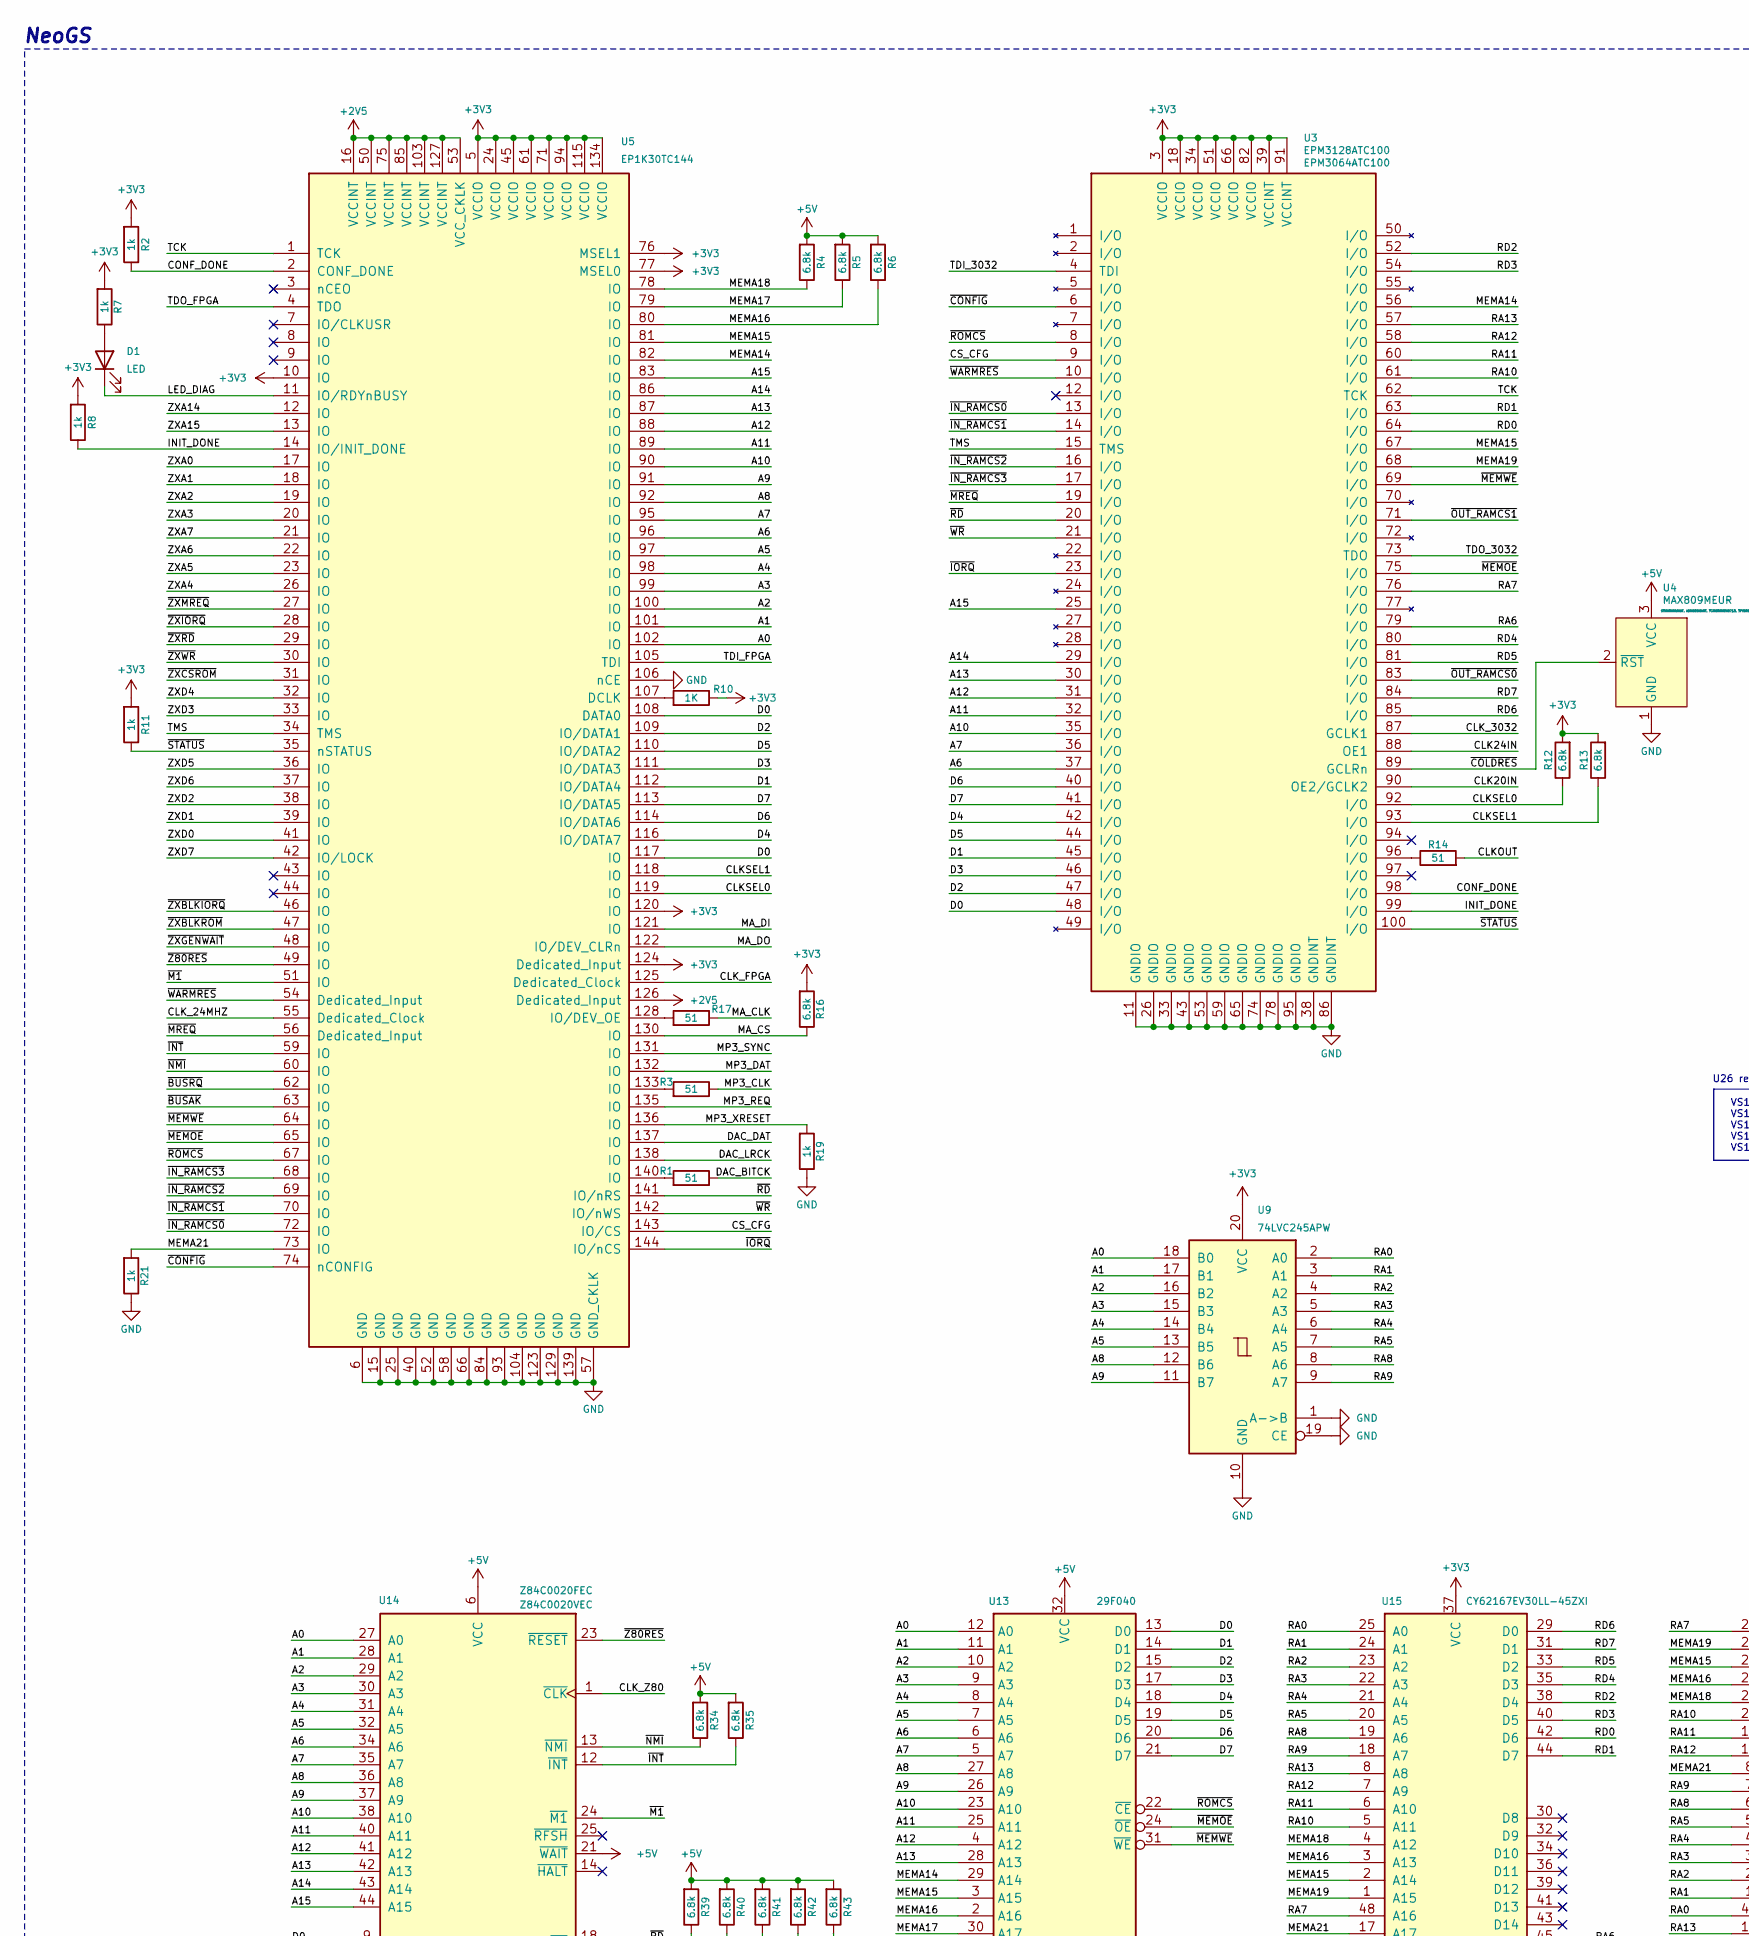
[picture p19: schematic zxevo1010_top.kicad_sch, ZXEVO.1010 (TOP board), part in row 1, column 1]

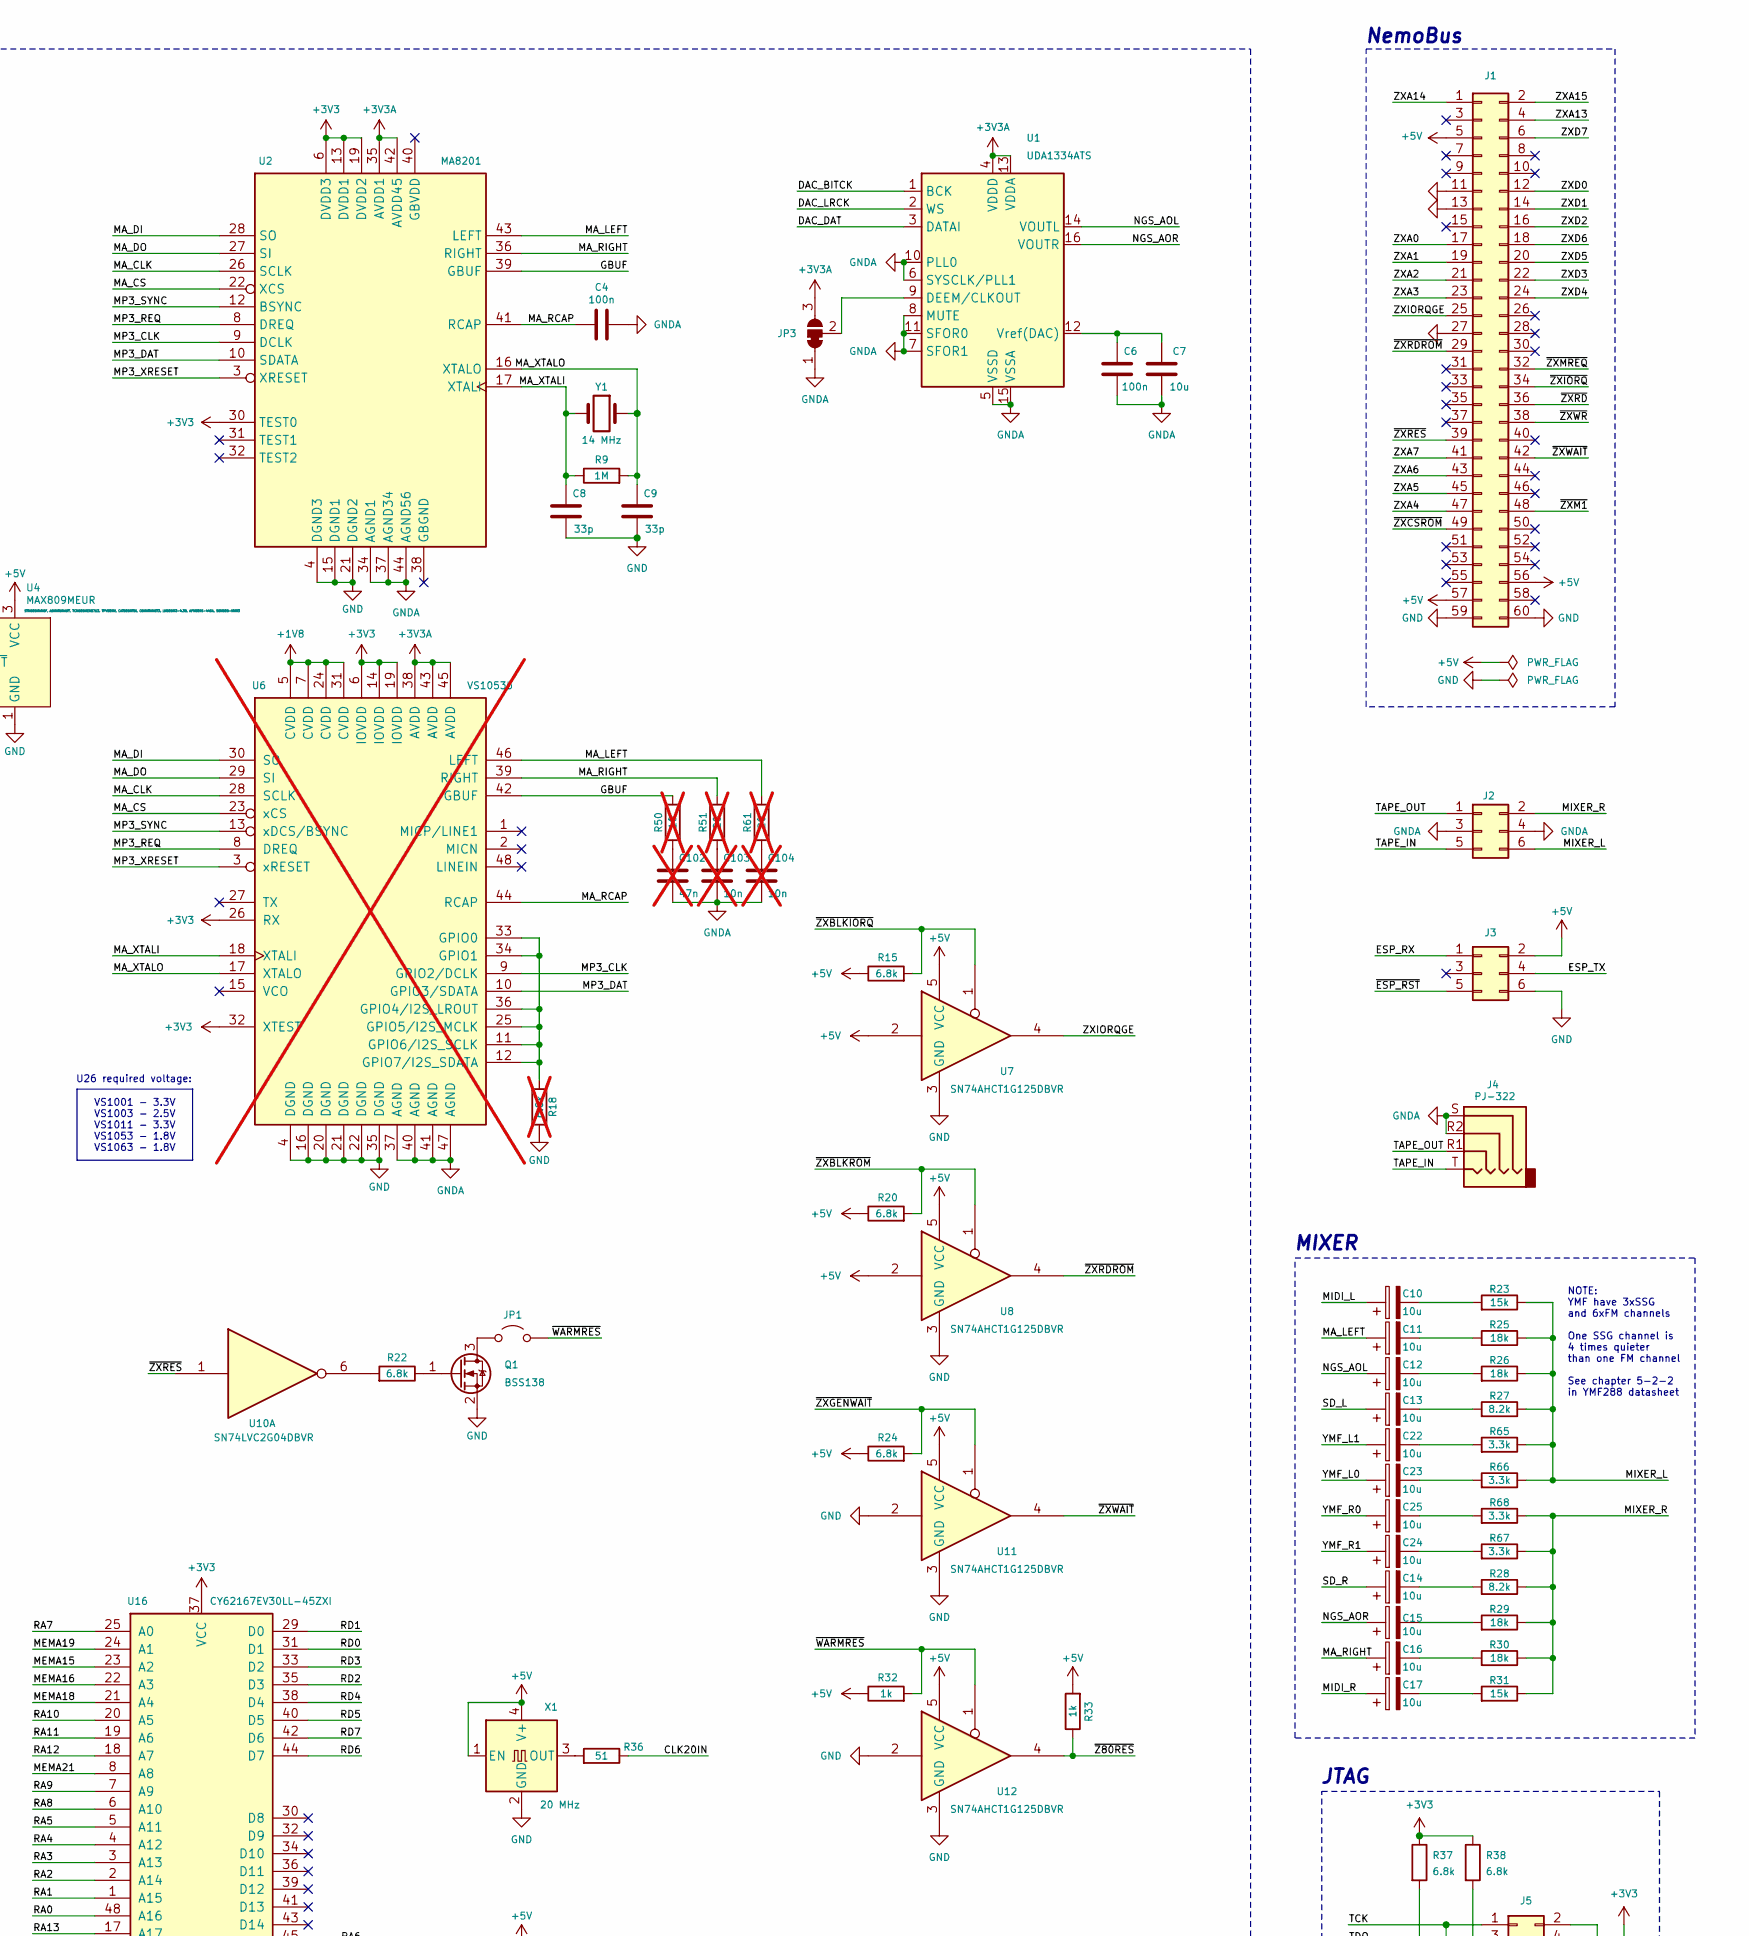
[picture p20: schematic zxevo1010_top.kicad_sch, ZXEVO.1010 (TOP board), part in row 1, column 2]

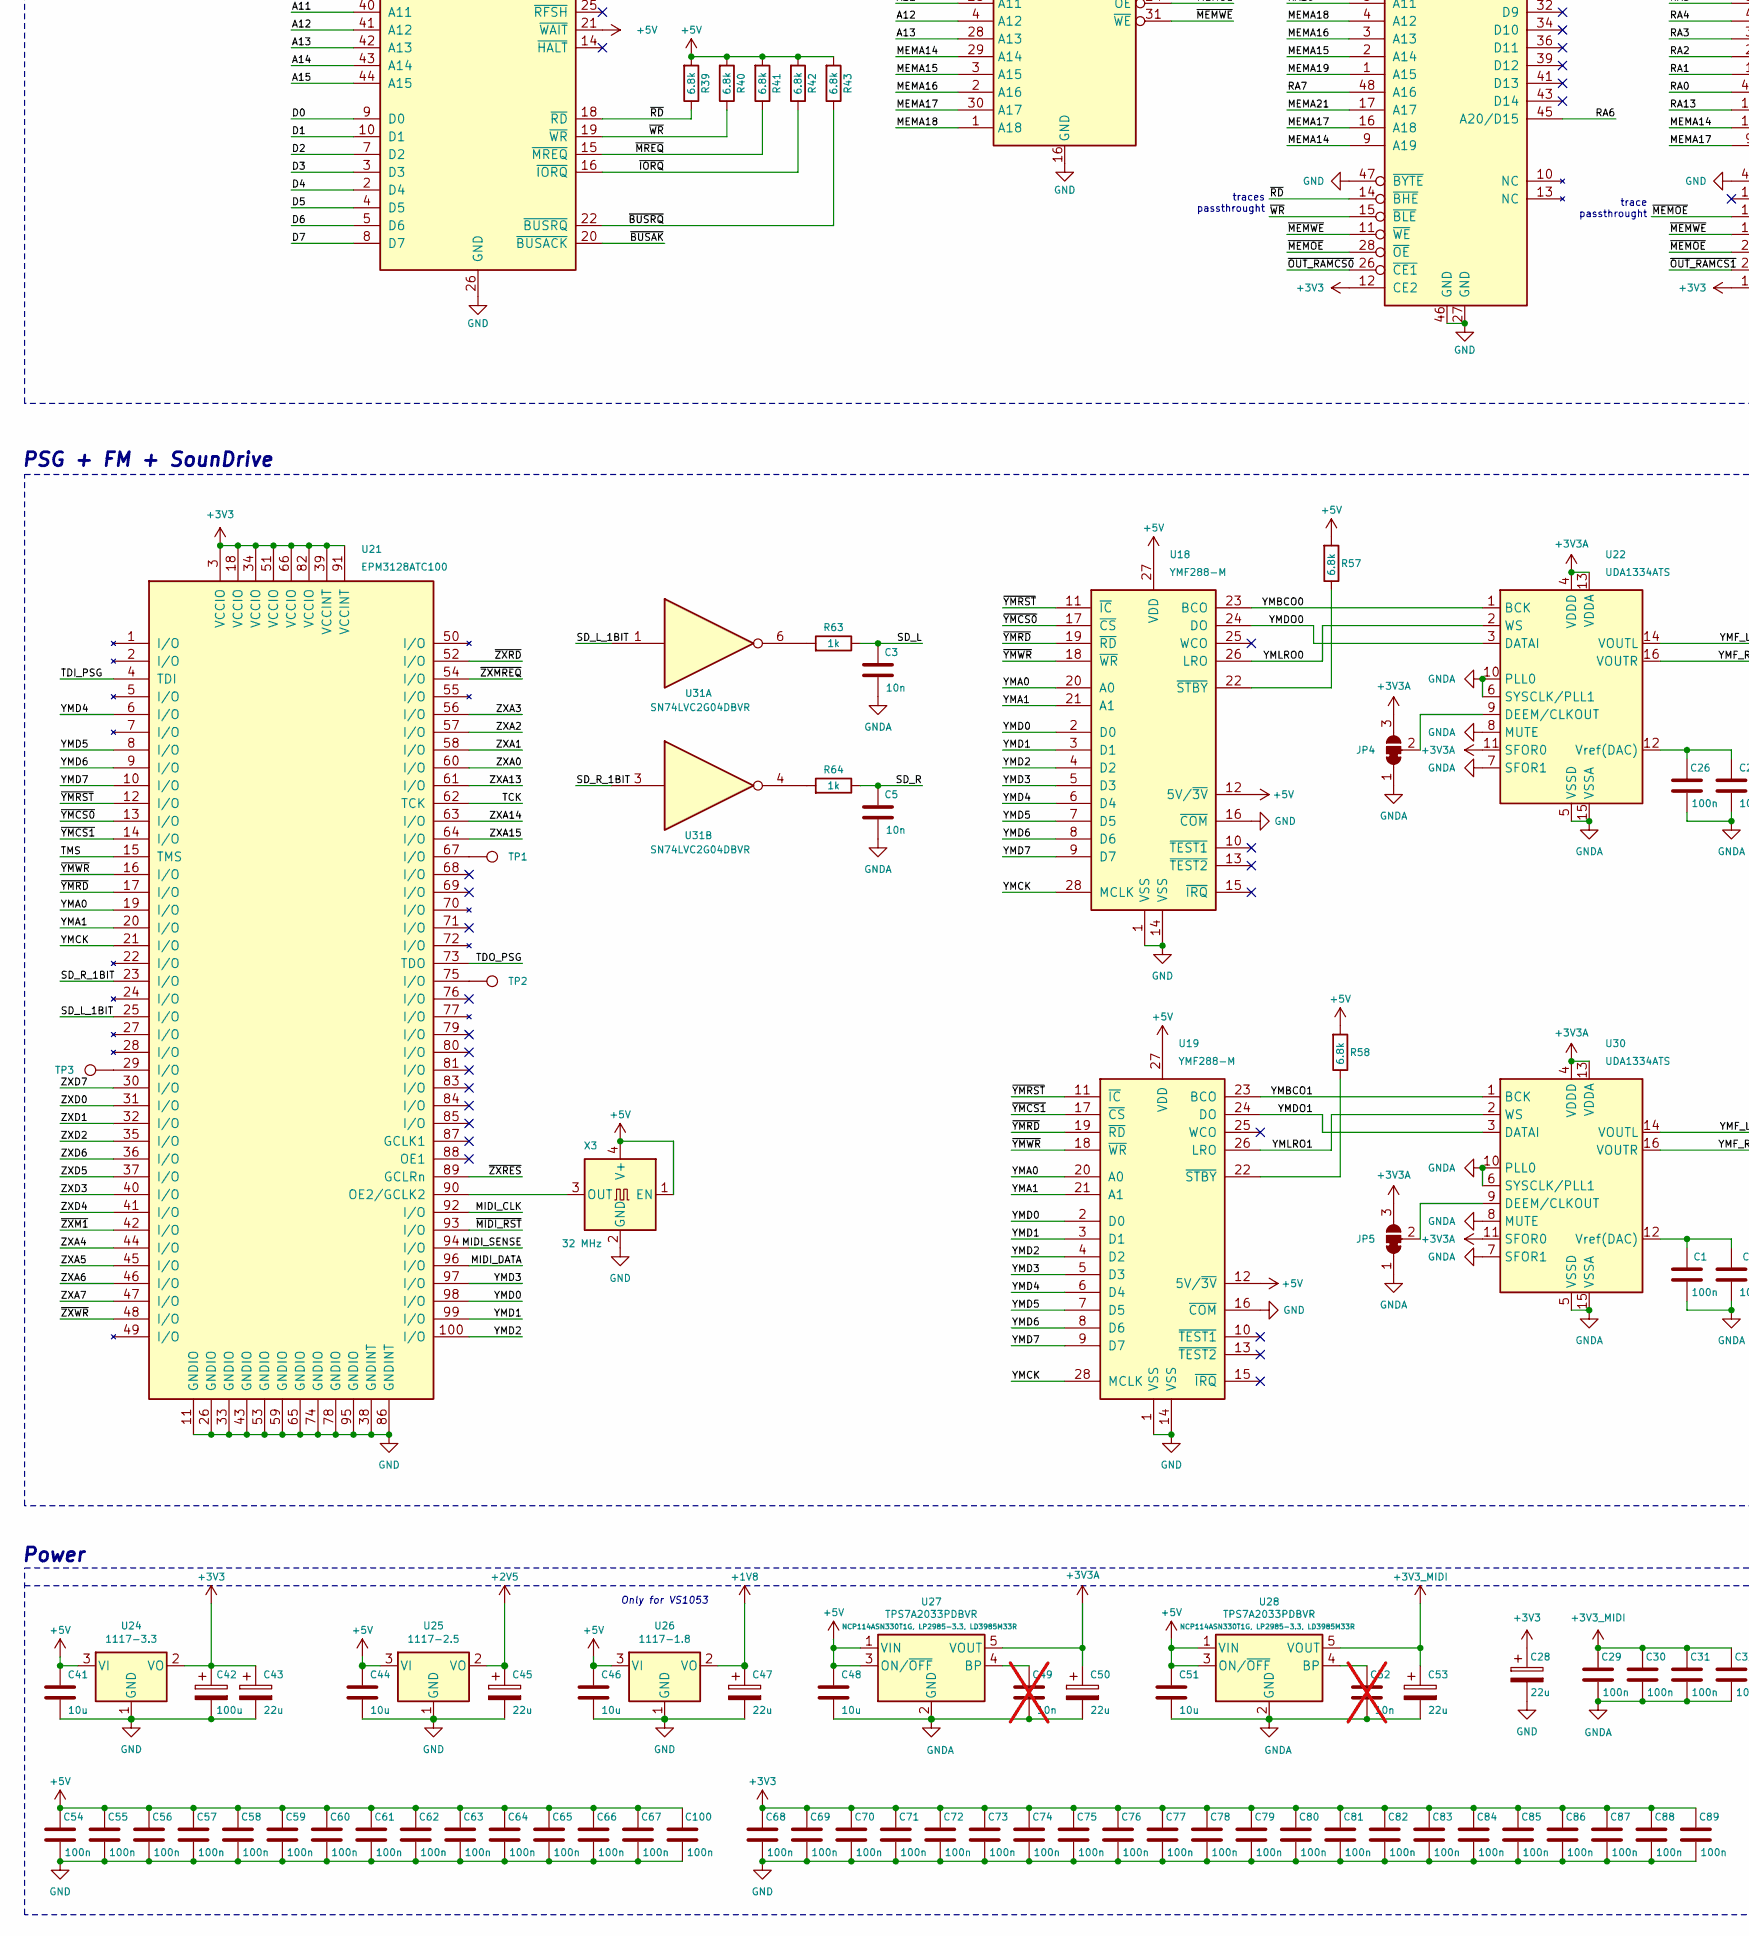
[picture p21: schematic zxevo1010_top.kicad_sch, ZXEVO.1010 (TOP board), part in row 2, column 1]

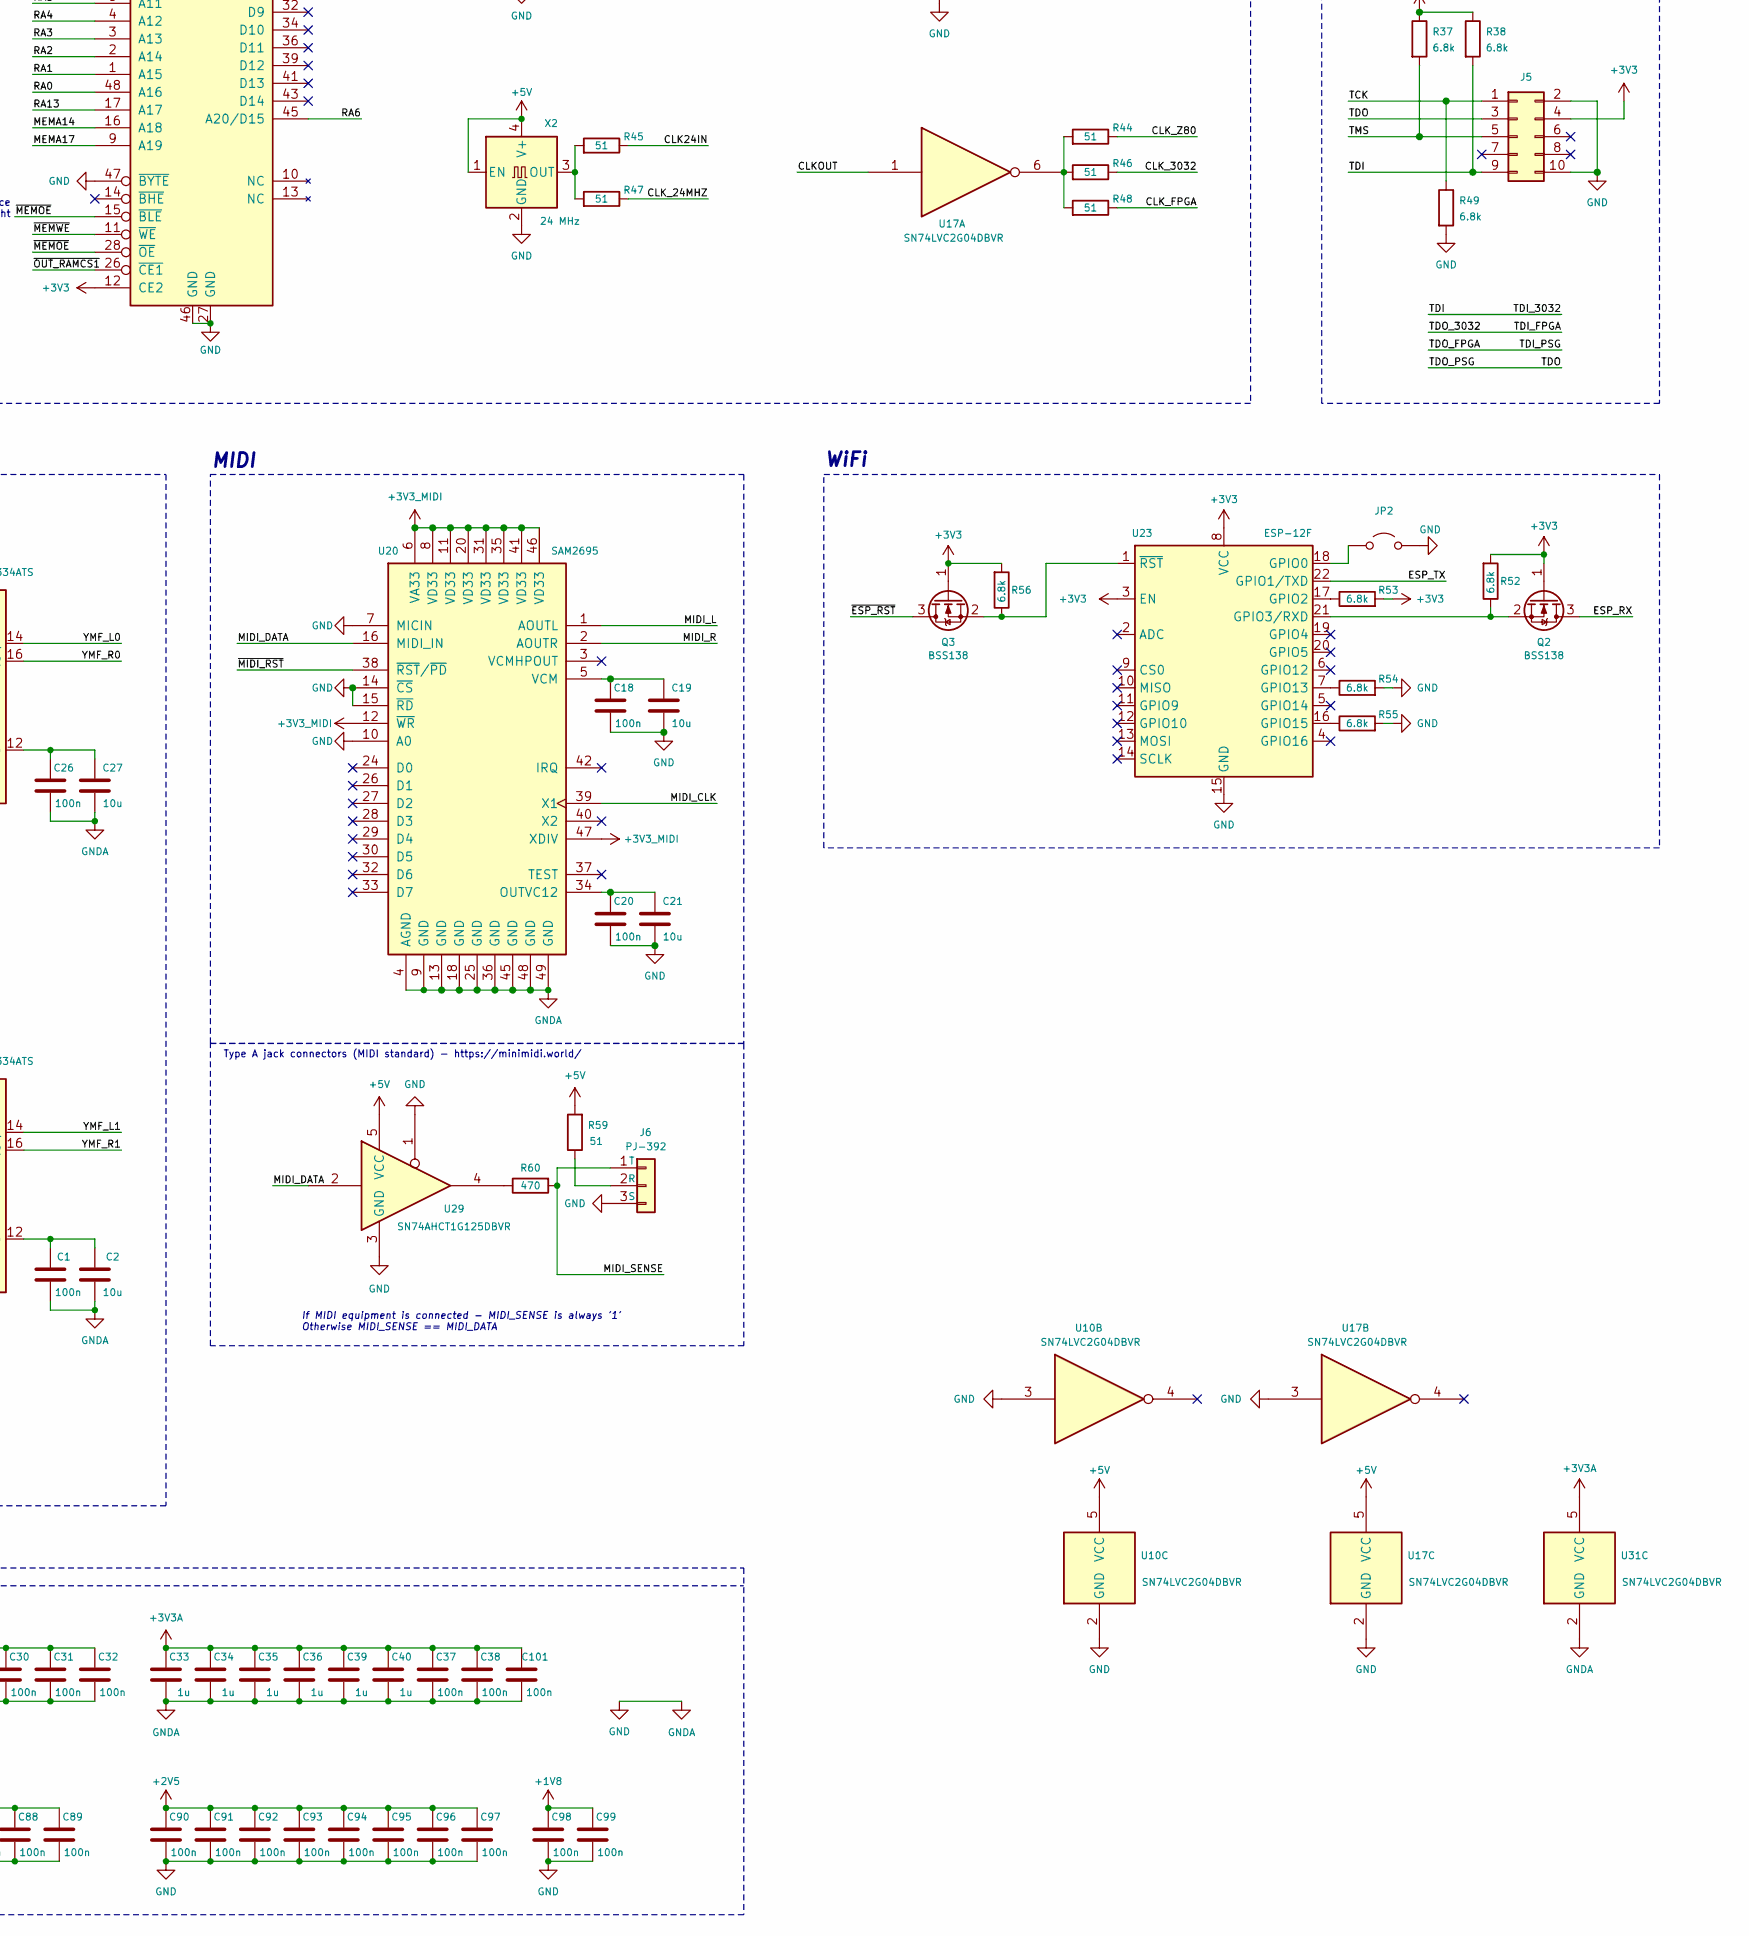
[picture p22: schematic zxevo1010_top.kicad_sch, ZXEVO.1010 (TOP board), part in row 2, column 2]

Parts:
C1, C4, C6, C18, C20, C26, C29, C30, C31, C32, C37, C38, C54, C55, C56, C57, C58, C59, C60, C61, C62, C63, C64, C65, C66, C67, C68, C69, C70, C71, C72, C73, C74, C75, C76, C85, C86, C87, C88, C89, C98, C99, C100, C101: 100n; C_0603_1608Metric_Pad1.08x0.95mm_HandSolder
C2, C7, C19, C21, C27, C41, C44, C46, C48, C51: 10u; C_0805_2012Metric_Pad1.18x1.45mm_HandSolder
C3, C5: 10n; C_0603_1608Metric_Pad1.08x0.95mm_HandSolder
C8, C9: 33p; C_0603_1608Metric_Pad1.08x0.95mm_HandSolder
C10, C11, C12, C13, C14, C15, C16, C17, C22, C23, C24, C25: 10u; CP_EIA-3216-18_Kemet-A_Pad1.58x1.35mm_HandSolder
C28, C43, C45, C47, C50, C53: 22u; CP_EIA-3216-18_Kemet-A_Pad1.58x1.35mm_HandSolder
C33, C34, C35, C36, C39, C40: 1u; C_0603_1608Metric_Pad1.08x0.95mm_HandSolder
C42: 100u; CP_EIA-6032-28_Kemet-C_Pad2.25x2.35mm_HandSolder
C49, C52, C103, C104: 10n; C_0603_1608Metric_Pad1.08x0.95mm_HandSolder; not fitted
C77, C78, C79, C80, C81, C82, C83, C84, C90, C91, C92, C93, C94, C95, C96, C97: 100n; C_0805_2012Metric_Pad1.18x1.45mm_HandSolder
C102: 47n; C_0603_1608Metric_Pad1.08x0.95mm_HandSolder; not fitted
D1: LED; LED_0603_1608Metric_Pad1.05x0.95mm_HandSolder
J1: Conn_02x30_Row_Letter_First; PinHeader_2x30_P2.54mm_Vertical
J2, J3: Conn_02x05_Odd_Even; PinSocket_2x03_P2.54mm_Vertical
J4: PJ-322
J5: Conn_02x05_Odd_Even; PinHeader_2x05_P2.54mm_Vertical
J6: PJ-392; PinHeader_1x03_P2.54mm_Vertical
JP1, JP2: Jumper; PinHeader_1x02_P2.54mm_Vertical
JP3, JP4, JP5: SolderJumper_3_Bridged12; SolderJumper-3_P1.3mm_Bridged12_RoundedPad1.0x1.5mm
Q1, Q2, Q3: BSS138; SOT-23
R1, R3, R14, R17, R36, R44, R45, R46, R47, R48, R59: 51; R_0603_1608Metric_Pad0.98x0.95mm_HandSolder
R2, R7, R8, R11, R19, R21, R32, R33, R63, R64: 1k; R_0603_1608Metric_Pad0.98x0.95mm_HandSolder
R4, R5, R6, R12, R13, R15, R16, R20, R22, R24, R34, R35, R37, R38, R39, R40, R41, R42, R43, R49, R52, R53, R54, R55, R56, R57, R58: 6.8k; R_0603_1608Metric_Pad0.98x0.95mm_HandSolder
R9: 1M; R_0603_1608Metric_Pad0.98x0.95mm_HandSolder
R10: 1K; R_0603_1608Metric_Pad0.98x0.95mm_HandSolder
R18: 6.8k; R_0603_1608Metric_Pad0.98x0.95mm_HandSolder; not fitted
R23, R31: 15k; R_0603_1608Metric_Pad0.98x0.95mm_HandSolder
R25, R26, R29, R30: 18k; R_0603_1608Metric_Pad0.98x0.95mm_HandSolder
R27, R28: 8.2k; R_0603_1608Metric_Pad0.98x0.95mm_HandSolder
R50: 10; R_0603_1608Metric_Pad0.98x0.95mm_HandSolder; not fitted
R51, R61: 20; R_0603_1608Metric_Pad0.98x0.95mm_HandSolder; not fitted
R60: 470; R_0603_1608Metric_Pad0.98x0.95mm_HandSolder
R65, R66, R67, R68: 3.3k; R_0603_1608Metric_Pad0.98x0.95mm_HandSolder
TP1, TP2, TP3: TestPoint; TestPoint_Pad_D1.0mm
U1, U22, U30: UDA1334ATS; SSOP-16_4.4x5.2mm_P0.65mm
U2: MA8201; MQFP-44_10x10mm_P0.8mm
U3, U21: EPM3128ATC100; TQFP-100_14x14mm_P0.5mm
U4: MAX809MEUR; SOT-23
U5: EP1K30TC144; TQFP-144_20x20mm_P0.5mm
U6: VS1053b; LQFP-48_7x7mm_P0.5mm; not fitted
U7, U8, U11, U12, U29: SN74AHCT1G125DBVR; SOT-23-5_HandSoldering
U9: 74LVC245APW; TSSOP-20_4.4x6.5mm_P0.65mm
U10, U17, U31: SN74LVC2G04DBVR; SOT-23-6_Handsoldering
U13: 29F040; PLCC-32_11.4x14.0mm_P1.27mm-longpads
U14: Z84C0020FEC; Z80_FEC_VEC
U15, U16: CY62167EV30LL-45ZXI; TSOP-I-48_18.4x12mm_P0.5mm
U18, U19: YMF288-M; SOP-28_8.4x18.16mm_P1.27mm
U20: SAM2695; QFN-48-1EP_6x6mm_P0.4mm_EP4.2x4.2mm
U23: ESP-12F; ESP-12E
U24: 1117-3.3; SOT-223-3_TabPin2
U25: 1117-2.5; SOT-223-3_TabPin2
U26: 1117-1.8; SOT-223-3_TabPin2
U27, U28: TPS7A2033PDBVR; SOT-23-5_HandSoldering
X1: 20 MHz; Oscillator_SMD_7050_7.0x5.0mm
X2: 24 MHz; Oscillator_SMD_7050_7.0x5.0mm
X3: 32 MHz; Oscillator_SMD_7050_7.0x5.0mm
Y1: 14 MHz; Crystal_HC49-4H_Vertical

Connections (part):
+1V8: C47.1, C98.2, C99.2, U6.5 (CVDD), U6.7 (CVDD), U6.24 (CVDD), U6.31 (CVDD), U26.2 (VO)
+2V5: C45.1, C90.2, C91.2, C92.2, C93.2, C94.2, C95.2, C96.2, C97.2, U5.16 (VCCINT), U5.50 (VCCINT), U5.53 (VCC_CKLK), U5.75 (VCCINT), U5.85 (VCCINT), U5.103 (VCCINT), U5.126 (Dedicated_Input), U5.127 (VCCINT), U25.2 (VO)
+3V3: C28.1, C42.1, C43.1, C68.2, C69.2, C70.2, C71.2, C72.2, C73.2, C74.2, C75.2, C76.2, C77.2, C78.2, C79.2, C80.2, C81.2, C82.2, C83.2, C84.2, C85.2, C86.2, C87.2, C88.2, C89.2, J5.4, Q2.1 (G), Q3.1 (G), R2.2, R7.2, R8.2, R10.1, R11.2, R12.2, R13.2, R16.2, R37.1, R38.1, R52.2, R53.2, R56.2, U2.6 (DVDD3), U2.13 (DVDD1), U2.19 (DVDD2), U2.30 (TEST0), U3.3 (VCCIO), U3.18 (VCCIO), U3.34 (VCCIO), U3.39 (VCCINT), U3.51 (VCCIO), U3.66 (VCCIO), U3.82 (VCCIO), U3.91 (VCCINT), U5.5 (VCCIO), U5.10 (IO), U5.24 (VCCIO), U5.45 (VCCIO), U5.61 (VCCIO), U5.71 (VCCIO), U5.76 (MSEL1), U5.77 (MSEL0), U5.94 (VCCIO), U5.115 (VCCIO), U5.120 (IO), U5.124 (Dedicated_Input), U5.134 (VCCIO), U6.6 (IOVDD), U6.14 (IOVDD), U6.19 (IOVDD), U6.26 (RX), U6.32 (XTEST), U9.20 (VCC), U15.12 (CE2), U15.37 (VCC), U16.12 (CE2), U16.37 (VCC), U21.3 (VCCIO), U21.18 (VCCIO), U21.34 (VCCIO), U21.39 (VCCINT)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
+3V3A: C33.2, C34.2, C35.2, C36.2, C37.2, C38.2, C39.2, C40.2, C50.1, C101.2, JP3.3 (B), JP4.3 (B), JP5.3 (B), U1.4 (VDDD), U1.13 (VDDA), U2.35 (AVDD1), U2.42 (AVDD45), U6.38 (AVDD), U6.43 (AVDD), U6.45 (AVDD), U22.4 (VDDD), U22.11 (SFOR0), U22.13 (VDDA), U27.5 (VOUT), U30.4 (VDDD), U30.11 (SFOR0), U30.13 (VDDA), U31.5 (VCC)
+3V3_MIDI: C29.2, C30.2, C31.2, C32.2, C53.1, U20.6 (VA33), U20.8 (VD33), U20.11 (VD33), U20.12 (~WR), U20.20 (VD33), U20.31 (VD33), U20.35 (VD33), U20.41 (VD33), U20.46 (VD33), U20.47 (XDIV), U28.5 (VOUT)
+5V: C41.2, C44.2, C46.2, C48.2, C51.2, C54.2, C55.2, C56.2, C57.2, C58.2, C59.2, C60.2, C61.2, C62.2, C63.2, C64.2, C65.2, C66.2, C67.2, C100.2, J1.5, J1.56, J1.57, J3.2, R4.2, R5.2, R6.2, R15.1, R20.1, R24.1, R32.1, R33.2, R34.2, R35.2, R39.2, R40.2, R41.2, R42.2, R43.2, R57.2, R58.2, R59.2, U4.3 (VCC), U7.2, U7.5 (VCC), U8.2, U8.5 (VCC), U10.5 (VCC), U11.5 (VCC), U12.5 (VCC), U13.32 (VCC), U14.6 (VCC), U14.21 (~WAIT), U17.5 (VCC), U18.12 (5V/~3V), U18.27 (VDD), U19.12 (5V/~3V), U19.27 (VDD), U24.3 (VI), U25.3 (VI), U26.3 (VI), U27.1 (VIN), U27.3 (ON/~OFF), U28.1 (VIN), U28.3 (ON/~OFF), U29.5 (VCC), X1.1 (EN), X1.4 (V+), X2.1 (EN), X2.4 (V+), X3.1 (EN), X3.4 (V+)
/A0: U5.102 (IO), U9.18 (B0), U13.12 (A0), U14.27 (A0)
/A1: U5.101 (IO), U9.17 (B1), U13.11 (A1), U14.28 (A1)
/A2: U5.100 (IO), U9.16 (B2), U13.10 (A2), U14.29 (A2)
/A3: U5.99 (IO), U9.15 (B3), U13.9 (A3), U14.30 (A3)
/A4: U5.98 (IO), U9.14 (B4), U13.8 (A4), U14.31 (A4)
/A5: U5.97 (IO), U9.13 (B5), U13.7 (A5), U14.32 (A5)
/A6: U3.37 (I/O), U5.96 (IO), U13.6 (A6), U14.34 (A6)
/A7: U3.36 (I/O), U5.95 (IO), U13.5 (A7), U14.35 (A7)
/A8: U5.92 (IO), U9.12 (B6), U13.27 (A8), U14.36 (A8)
/A9: U5.91 (IO), U9.11 (B7), U13.26 (A9), U14.37 (A9)
/A10: U3.35 (I/O), U5.90 (IO), U13.23 (A10), U14.38 (A10)
/A11: U3.32 (I/O), U5.89 (IO), U13.25 (A11), U14.40 (A11)
/A12: U3.31 (I/O), U5.88 (IO), U13.4 (A12), U14.41 (A12)
/A13: U3.30 (I/O), U5.87 (IO), U13.28 (A13), U14.42 (A13)
/A14: U3.29 (I/O), U5.86 (IO), U14.43 (A14)
/A15: U3.25 (I/O), U5.83 (IO), U14.44 (A15)
/CLK20IN: R36.1, U3.90 (OE2/GCLK2)
/CLK24IN: R45.1, U3.88 (OE1)
/CLKOUT: R14.2, U17.1
/CLKSEL0: R12.1, U3.92 (I/O), U5.119 (IO)
/CLKSEL1: R13.1, U3.93 (I/O), U5.118 (IO)
/CLK_24MHZ: R47.1, U5.55 (Dedicated_Clock)
/CLK_3032: R46.1, U3.87 (GCLK1)
/CLK_FPGA: R48.1, U5.125 (Dedicated_Clock)
/CLK_Z80: R44.1, U14.1 (~CLK)
/CONF_DONE: R2.1, U3.98 (I/O), U5.2 (CONF_DONE)
/CS_CFG: U3.9 (I/O), U5.143 (IO/CS)
/D0: U3.48 (I/O), U5.108 (DATA0), U5.117 (IO), U13.13 (D0), U14.9 (D0)
/D1: U3.45 (I/O), U5.112 (IO/DATA4), U13.14 (D1), U14.10 (D1)
/D2: U3.47 (I/O), U5.109 (IO/DATA1), U13.15 (D2), U14.7 (D2)
/D3: U3.46 (I/O), U5.111 (IO/DATA3), U13.17 (D3), U14.3 (D3)
/D4: U3.42 (I/O), U5.116 (IO/DATA7), U13.18 (D4), U14.2 (D4)
/D5: U3.44 (I/O), U5.110 (IO/DATA2), U13.19 (D5), U14.4 (D5)
/D6: U3.40 (I/O), U5.114 (IO/DATA6), U13.20 (D6), U14.5 (D6)
/D7: U3.41 (I/O), U5.113 (IO/DATA5), U13.21 (D7), U14.8 (D7)
/DAC_BITCK: R1.1, U1.1 (BCK)
/DAC_DAT: U1.3 (DATAI), U5.137 (IO)
/DAC_LRCK: U1.2 (WS), U5.138 (IO)
/ESP_RX: J3.1, Q2.3 (D)
/ESP_TX: J3.4, U23.22 (GPIO1/TXD)
/GBUF: R50.2, U2.39 (GBUF), U6.42 (GBUF)
/INIT_DONE: R8.1, U3.99 (I/O), U5.14 (IO/INIT_DONE)
/LED_DIAG: D1.1 (K), U5.11 (IO/RDYnBUSY)
/MA_CLK: R17.1, U2.26 (SCLK), U6.28 (SCLK)
/MA_CS: R16.1, U2.22 (XCS), U5.130 (IO), U6.23 (xCS)
/MA_DI: U2.28 (SO), U5.121 (IO), U6.30 (SO)
/MA_DO: U2.27 (SI), U5.122 (IO/DEV_CLRn), U6.29 (SI)
/MA_LEFT: C11.1, R61.2, U2.43 (LEFT), U6.46 (LEFT)
/MA_RCAP: C4.1, U2.41 (RCAP), U6.44 (RCAP)
/MA_RIGHT: C16.1, R51.2, U2.36 (RIGHT), U6.39 (RIGHT)
/MA_XTALI: C8.2, R9.1, U2.17 (XTALI), U6.18 (XTALI), Y1.2
/MA_XTALO: C9.2, R9.2, U2.16 (XTALO), U6.17 (XTALO), Y1.1
/MEMA14: U3.56 (I/O), U5.82 (IO), U13.29 (A14), U15.9 (A19), U16.16 (A18)
/MEMA15: U3.67 (I/O), U5.81 (IO), U13.3 (A15), U15.2 (A14), U16.23 (A2)
/MEMA16: R6.1, U5.80 (IO), U13.2 (A16), U15.3 (A13), U16.22 (A3)
/MEMA17: R5.1, U5.79 (IO), U13.30 (A17), U15.16 (A18), U16.9 (A19)
/MEMA18: R4.1, U5.78 (IO), U13.1 (A18), U15.4 (A12), U16.21 (A4)
/MEMA19: U3.68 (I/O), U15.1 (A15), U16.24 (A1)
/MEMA21: R21.2, U5.73 (IO), U15.17 (A17), U16.8 (A8)
/MIDI_CLK: U20.39 (X1), U21.92 (I/O)
/MIDI_DATA: U20.16 (MIDI_IN), U21.96 (I/O), U29.2
/MIDI_L: C10.1, U20.1 (AOUTL)
/MIDI_R: C17.1, U20.2 (AOUTR)
/MIDI_SENSE: J6.1, R60.2, U21.94 (I/O)
/MIXER_L: J2.6, R23.1, R25.1, R26.1, R27.1, R65.1, R66.1
/MIXER_R: J2.2, R28.1, R29.1, R30.1, R31.1, R67.1, R68.1
/MP3_CLK: R3.1, U2.9 (DCLK), U6.9 (GPIO2/DCLK)
/MP3_DAT: U2.10 (SDATA), U5.132 (IO), U6.10 (GPIO3/SDATA)
/MP3_REQ: U2.8 (DREQ), U5.135 (IO), U6.8 (DREQ)
/MP3_SYNC: U2.12 (BSYNC), U5.131 (IO), U6.13 (xDCS/BSYNC)
/MP3_XRESET: R19.2, U2.3 (XRESET), U5.136 (IO), U6.3 (xRESET)
/NGS_AOL: C12.1, U1.14 (VOUTL)
/NGS_AOR: C15.1, U1.16 (VOUTR)
/RA0: U9.2 (A0), U15.25 (A0), U16.48 (A16)
/RA1: U9.3 (A1), U15.24 (A1), U16.1 (A15)
/RA2: U9.4 (A2), U15.23 (A2), U16.2 (A14)
/RA3: U9.5 (A3), U15.22 (A3), U16.3 (A13)
/RA4: U9.6 (A4), U15.21 (A4), U16.4 (A12)
/RA5: U9.7 (A5), U15.20 (A5), U16.5 (A11)
/RA6: U3.79 (I/O), U15.45 (A20/D15), U16.45 (A20/D15)
/RA7: U3.76 (I/O), U15.48 (A16), U16.25 (A0)
/RA8: U9.8 (A6), U15.19 (A6), U16.6 (A10)
/RA9: U9.9 (A7), U15.18 (A7), U16.7 (A9)
/RA10: U3.61 (I/O), U15.5 (A11), U16.20 (A5)
/RA11: U3.60 (I/O), U15.6 (A10), U16.19 (A6)
/RA12: U3.58 (I/O), U15.7 (A9), U16.18 (A7)
/RA13: U3.57 (I/O), U15.8 (A8), U16.17 (A17)
/RD0: U3.64 (I/O), U15.42 (D6), U16.31 (D1)
/RD1: U3.63 (I/O), U15.44 (D7), U16.29 (D0)
/RD2: U3.52 (I/O), U15.38 (D4), U16.35 (D3)
/RD3: U3.54 (I/O), U15.40 (D5), U16.33 (D2)
/RD4: U3.80 (I/O), U15.35 (D3), U16.38 (D4)
/RD5: U3.81 (I/O), U15.33 (D2), U16.40 (D5)
/RD6: U3.85 (I/O), U15.29 (D0), U16.44 (D7)
/RD7: U3.84 (I/O), U15.31 (D1), U16.42 (D6)
/SD_L: C3.2, C13.1, R63.1
/SD_L_1BIT: U21.25 (I/O), U31.1
/SD_R: C5.2, C14.1, R64.1
/SD_R_1BIT: U21.23 (I/O), U31.3
/TAPE_IN: J2.5, J4.T
/TAPE_OUT: J2.1, J4.R1
/TCK: J5.1, R49.1, U3.62 (TCK), U5.1 (TCK), U21.62 (TCK)
/TDI: J5.9, R38.2, U3.4 (TDI)
/TDI_FPGA: U3.73 (TDO), U5.105 (TDI)
/TDI_PSG: U5.4 (TDO), U21.4 (TDI)
/TDO: J5.3, U21.73 (TDO)
/TMS: J5.5, R37.2, U3.15 (TMS), U5.34 (TMS), U21.15 (TMS)
/YMA0: U18.20 (A0), U19.20 (A0), U21.19 (I/O)
/YMA1: U18.21 (A1), U19.21 (A1), U21.20 (I/O)
/YMBCO0: U18.23 (BCO), U22.1 (BCK)
/YMBCO1: U19.23 (BCO), U30.1 (BCK)
/YMCK: U18.28 (MCLK), U19.28 (MCLK), U21.21 (I/O)
/YMD0: U18.2 (D0), U19.2 (D0), U21.98 (I/O)
/YMD1: U18.3 (D1), U19.3 (D1), U21.99 (I/O)
/YMD2: U18.4 (D2), U19.4 (D2), U21.100 (I/O)
/YMD3: U18.5 (D3), U19.5 (D3), U21.97 (I/O)
/YMD4: U18.6 (D4), U19.6 (D4), U21.6 (I/O)
/YMD5: U18.7 (D5), U19.7 (D5), U21.8 (I/O)
/YMD6: U18.8 (D6), U19.8 (D6), U21.9 (I/O)
/YMD7: U18.9 (D7), U19.9 (D7), U21.10 (I/O)
/YMDO0: U18.24 (DO), U22.3 (DATAI)
/YMDO1: U19.24 (DO), U30.3 (DATAI)
/YMF_L0: C23.1, U22.14 (VOUTL)
/YMF_L1: C22.1, U30.14 (VOUTL)
/YMF_R0: C25.1, U22.16 (VOUTR)
/YMF_R1: C24.1, U30.16 (VOUTR)
/YMLRO0: U18.26 (LRO), U22.2 (WS)
/YMLRO1: U19.26 (LRO), U30.2 (WS)
/ZXA0: J1.17, U5.17 (IO), U21.60 (I/O)
/ZXA1: J1.19, U5.18 (IO), U21.58 (I/O)
/ZXA2: J1.21, U5.19 (IO), U21.57 (I/O)
/ZXA3: J1.23, U5.20 (IO), U21.56 (I/O)
/ZXA4: J1.47, U5.26 (IO), U21.44 (I/O)
/ZXA5: J1.45, U5.23 (IO), U21.45 (I/O)
/ZXA6: J1.43, U5.22 (IO), U21.46 (I/O)
/ZXA7: J1.41, U5.21 (IO), U21.47 (I/O)
/ZXA13: J1.4, U21.61 (I/O)
/ZXA14: J1.1, U5.12 (IO), U21.63 (I/O)
/ZXA15: J1.2, U5.13 (IO), U21.64 (I/O)
/ZXD0: J1.12, U5.41 (IO), U21.31 (I/O)
/ZXD1: J1.14, U5.39 (IO), U21.32 (I/O)
/ZXD2: J1.16, U5.38 (IO), U21.35 (I/O)
/ZXD3: J1.22, U5.33 (IO), U21.40 (I/O)
/ZXD4: J1.24, U5.32 (IO), U21.41 (I/O)
/ZXD5: J1.20, U5.36 (IO), U21.37 (I/O)
/ZXD6: J1.18, U5.37 (IO), U21.36 (I/O)
/ZXD7: J1.6, U5.42 (IO/LOCK), U21.30 (I/O)
/ZXIORQGE: J1.25, U7.4
/~BUSAK: U5.63 (IO), U14.20 (~BUSACK)
/~BUSRQ: R43.1, U5.62 (IO), U14.22 (~BUSRQ)
/~COLDRES: U3.89 (GCLRn), U4.2 (~RST)
/~CONFIG: U3.6 (I/O), U5.74 (nCONFIG)
/~ESP_RST: J3.5, Q3.3 (D)
/~INT: R35.1, U5.59 (IO), U14.12 (~INT)
/~IN_RAMCS0: U3.13 (I/O), U5.72 (IO)
/~IN_RAMCS1: U3.14 (I/O), U5.70 (IO)
/~IN_RAMCS2: U3.16 (I/O), U5.69 (IO)
/~IN_RAMCS3: U3.17 (I/O), U5.68 (IO)
/~IORQ: R42.1, U3.23 (I/O), U5.144 (IO/nCS), U14.16 (~IORQ)
/~M1: U5.51 (IO), U14.24 (~M1)
/~MEMOE: U3.75 (I/O), U5.65 (IO), U13.24 (~OE), U15.28 (~OE), U16.15 (~BLE), U16.28 (~OE)
/~MEMWE: U3.69 (I/O), U5.64 (IO), U13.31 (~WE), U15.11 (~WE), U16.11 (~WE)
/~MIDI_RST: U20.38 (~RST/~PD), U21.93 (I/O)
/~MREQ: R41.1, U3.19 (I/O), U5.56 (Dedicated_Input), U14.15 (~MREQ)
/~NMI: R34.1, U5.60 (IO), U14.13 (~NMI)
/~OUT_RAMCS0: U3.83 (I/O), U15.26 (~CE1)
/~OUT_RAMCS1: U3.71 (I/O), U16.26 (~CE1)
/~RD: R39.1, U3.20 (I/O), U5.141 (IO/nRS), U14.18 (~RD), U15.14 (~BHE)
/~ROMCS: U3.8 (I/O), U5.67 (IO), U13.22 (~CE)
/~STATUS: R11.1, U3.100 (I/O), U5.35 (nSTATUS)
/~WARMRES: JP1.2 (B), R32.2, U3.10 (I/O), U5.54 (Dedicated_Input), U12.1
/~WR: R40.1, U3.21 (I/O), U5.142 (IO/nWS), U14.19 (~WR), U15.15 (~BLE)
/~YMCS0: U18.17 (~CS), U21.13 (I/O)
/~YMCS1: U19.17 (~CS), U21.14 (I/O)
/~YMRD: U18.19 (~RD), U19.19 (~RD), U21.17 (I/O)
/~YMRST: U18.11 (~IC), U19.11 (~IC), U21.12 (I/O)
/~YMWR: U18.18 (~WR), U19.18 (~WR), U21.16 (I/O)
/~Z80RES: R33.1, U5.49 (IO), U12.4, U14.23 (~RESET)
/~ZXBLKIORQ: R15.2, U5.46 (IO), U7.1
/~ZXBLKROM: R20.2, U5.47 (IO), U8.1
/~ZXCSROM: J1.49, U5.31 (IO)
/~ZXGENWAIT: R24.2, U5.48 (IO), U11.1
/~ZXIORQ: J1.34, U5.28 (IO)
/~ZXM1: J1.48, U21.42 (I/O)
/~ZXMREQ: J1.32, U5.27 (IO), U21.54 (I/O)
/~ZXRDROM: J1.29, U8.4
/~ZXRD: J1.36, U5.29 (IO), U21.52 (I/O)
/~ZXRES: J1.39, U10.1, U21.89 (GCLRn)
/~ZXWAIT: J1.42, U11.4
/~ZXWR: J1.38, U5.30 (IO), U21.48 (I/O)
GND: C1.1, C2.1, C3.1, C4.2, C5.1, C6.1, C7.1, C8.1, C9.1, C18.1, C19.1, C20.1, C21.1, C26.1, C27.1, C28.2, C29.1, C30.1, C31.1, C32.1, C33.1, C34.1, C35.1, C36.1, C37.1, C38.1, C39.1, C40.1, C41.1, C42.2, C43.2, C44.1, C45.2, C46.1, C47.2, C48.1, C49.1, C50.2, C51.1, C52.1, C53.2, C54.1, C55.1, C56.1, C57.1, C58.1, C59.1, C60.1, C61.1, C62.1, C63.1, C64.1, C65.1, C66.1, C67.1, C68.1, C69.1, C70.1, C71.1, C72.1, C73.1, C74.1, C75.1, C76.1, C77.1, C78.1, C79.1, C80.1, C81.1, C82.1, C83.1, C84.1, C85.1, C86.1, C87.1, C88.1, C89.1, C90.1, C91.1, C92.1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
unnamed: C10.2, R23.2
unnamed: C11.2, R25.2
unnamed: C12.2, R26.2
unnamed: C13.2, R27.2
unnamed: C14.2, R28.2
unnamed: C15.2, R29.2
unnamed: C16.2, R30.2
unnamed: C17.2, R31.2
unnamed: C22.2, R65.2
unnamed: C23.2, R66.2
unnamed: C24.2, R67.2
unnamed: C25.2, R68.2
unnamed: C102.2, R50.1
unnamed: C103.2, R51.1
unnamed: C104.2, R61.1
unnamed: D1.2 (A), R7.1
unnamed: J6.2, R59.1
unnamed: JP1.1 (A), Q1.3 (D)
unnamed: JP2.2 (B), U23.18 (GPIO0)
unnamed: JP3.2 (C), U1.9 (DEEM/CLKOUT)
unnamed: JP4.2 (C), U22.9 (DEEM/CLKOUT)
unnamed: JP5.2 (C), U30.9 (DEEM/CLKOUT)
unnamed: Q1.1 (G), R22.1
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

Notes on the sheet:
VS1001 - 3.3V VS1003 - 2.5V VS1011 - 3.3V VS1053 - 1.8V VS1063 - 1.8V
WiFi
Type A jack connectors (MIDI standard) - https://minimidi.world/
MIDI
traces passthrought
NOTE: YMF have 3xSSG and 6xFM channels One SSG channel is 4 times quieter than one FM channel See chapter 5-2-2 in YMF288 datasheet
NeoGS
U26 required voltage:
JTAG
PSG + FM + SounDrive
If MIDI equipment is connected - MIDI_SENSE is always '1' Otherwise MIDI_SENSE == MIDI_DATA
Power
Only for VS1053
trace passthrought
NemoBus
MIXER

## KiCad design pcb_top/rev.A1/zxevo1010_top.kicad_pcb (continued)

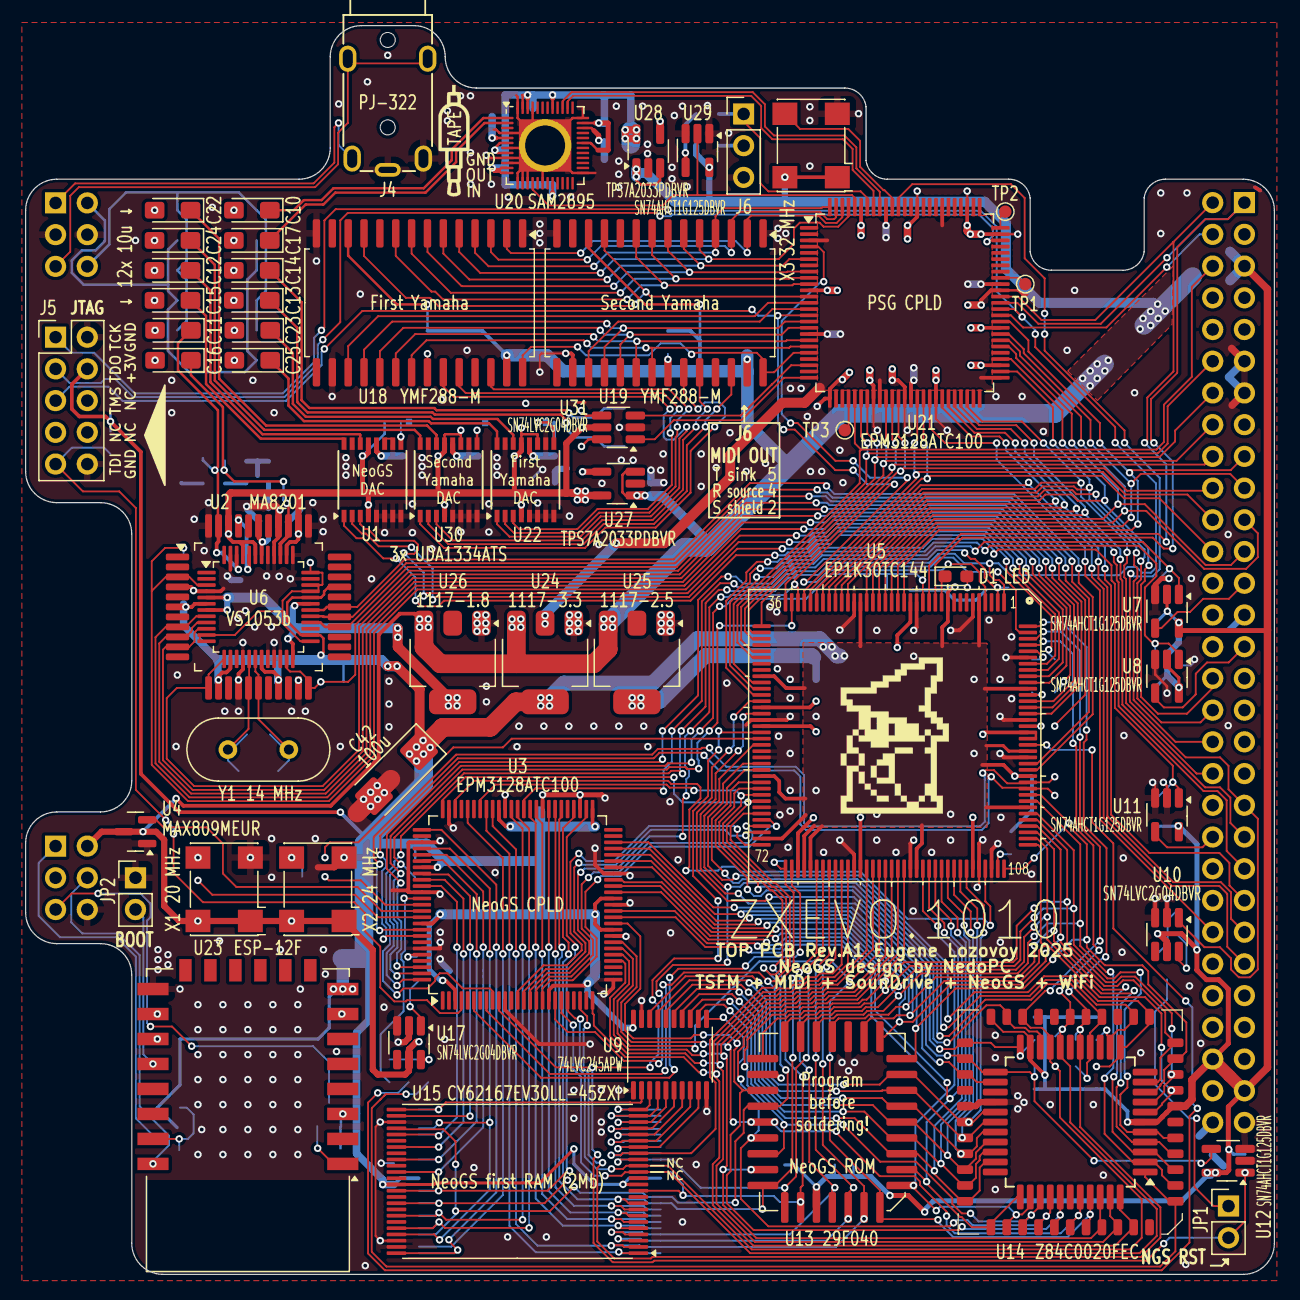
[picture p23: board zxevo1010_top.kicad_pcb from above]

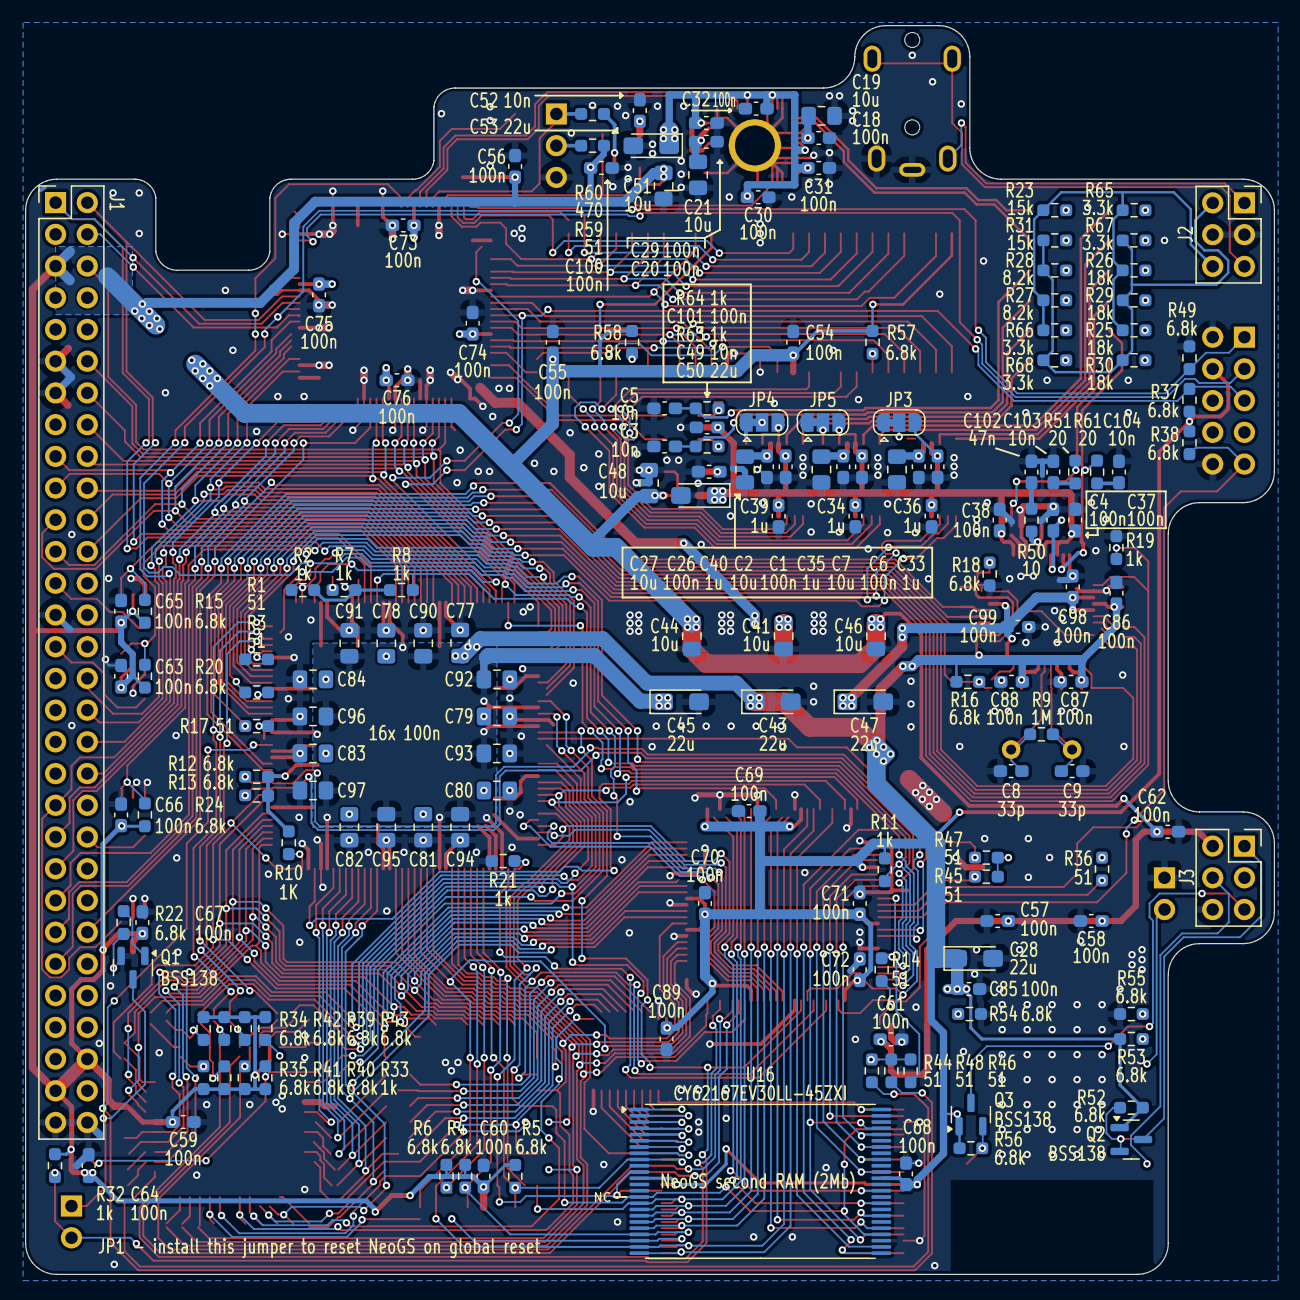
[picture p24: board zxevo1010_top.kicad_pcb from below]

Board: 2 copper layers, 100.0 x 100.0 mm, 224 parts (168 on the bottom side), 251 nets.

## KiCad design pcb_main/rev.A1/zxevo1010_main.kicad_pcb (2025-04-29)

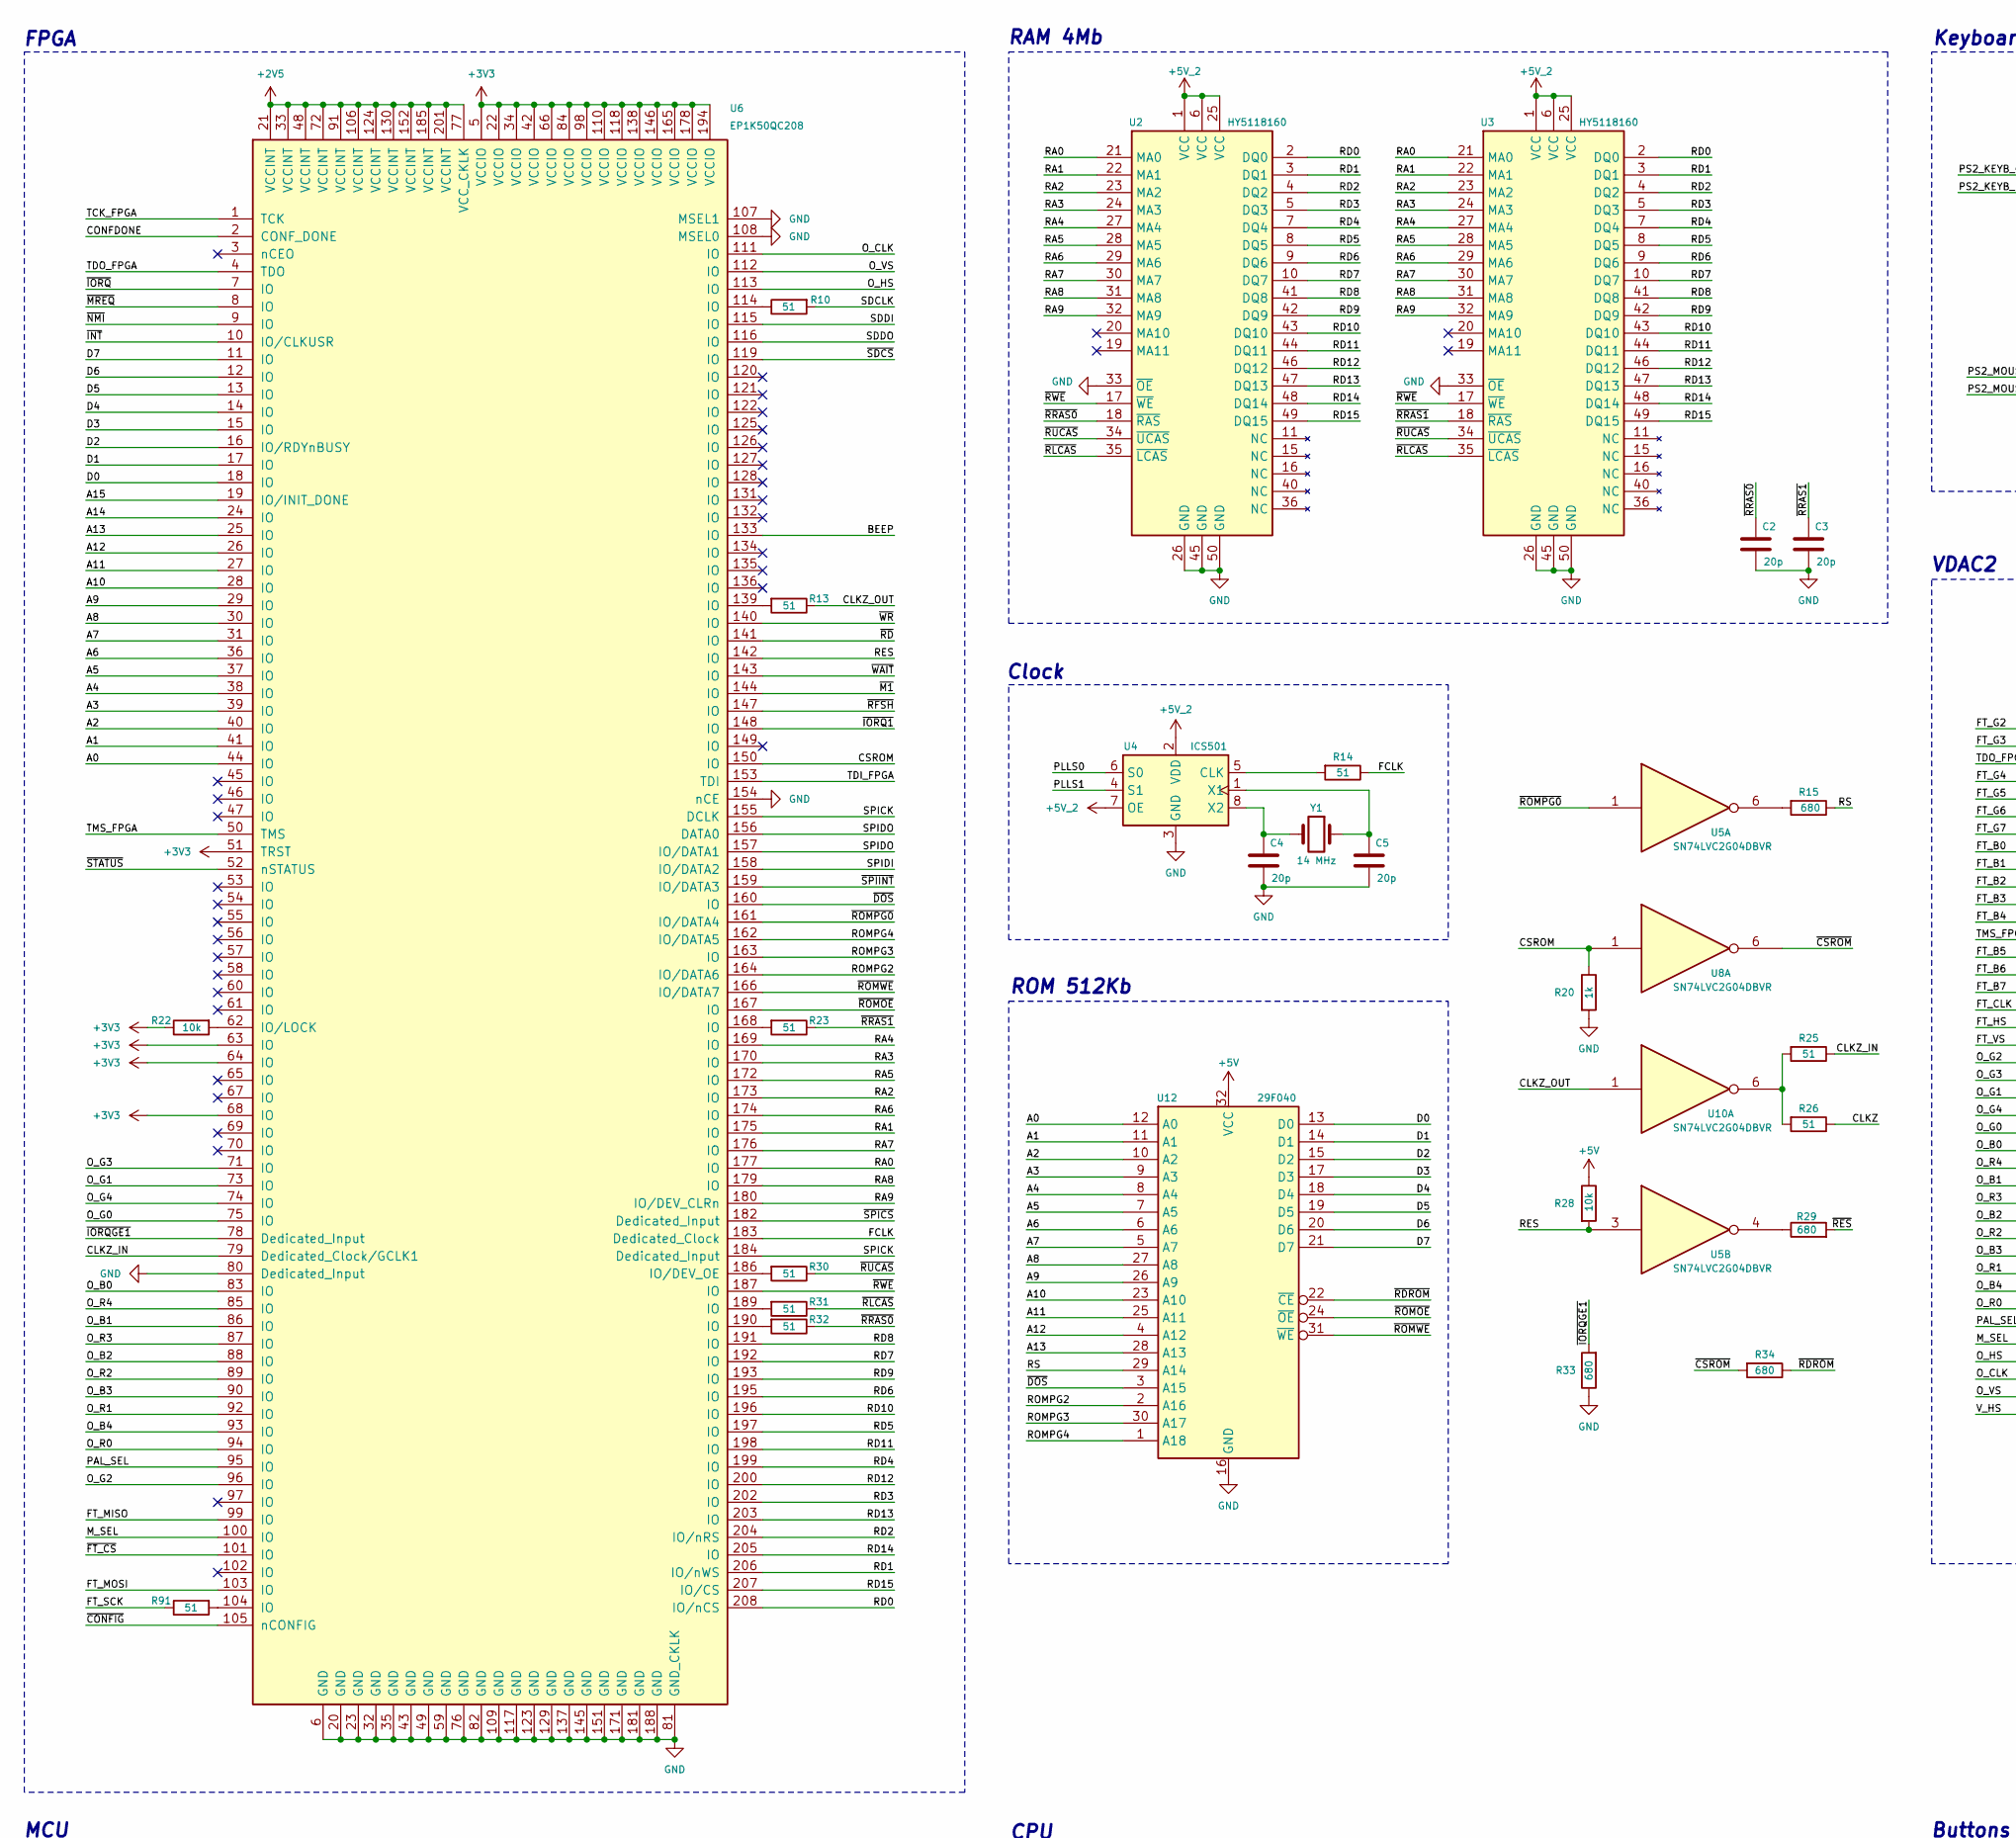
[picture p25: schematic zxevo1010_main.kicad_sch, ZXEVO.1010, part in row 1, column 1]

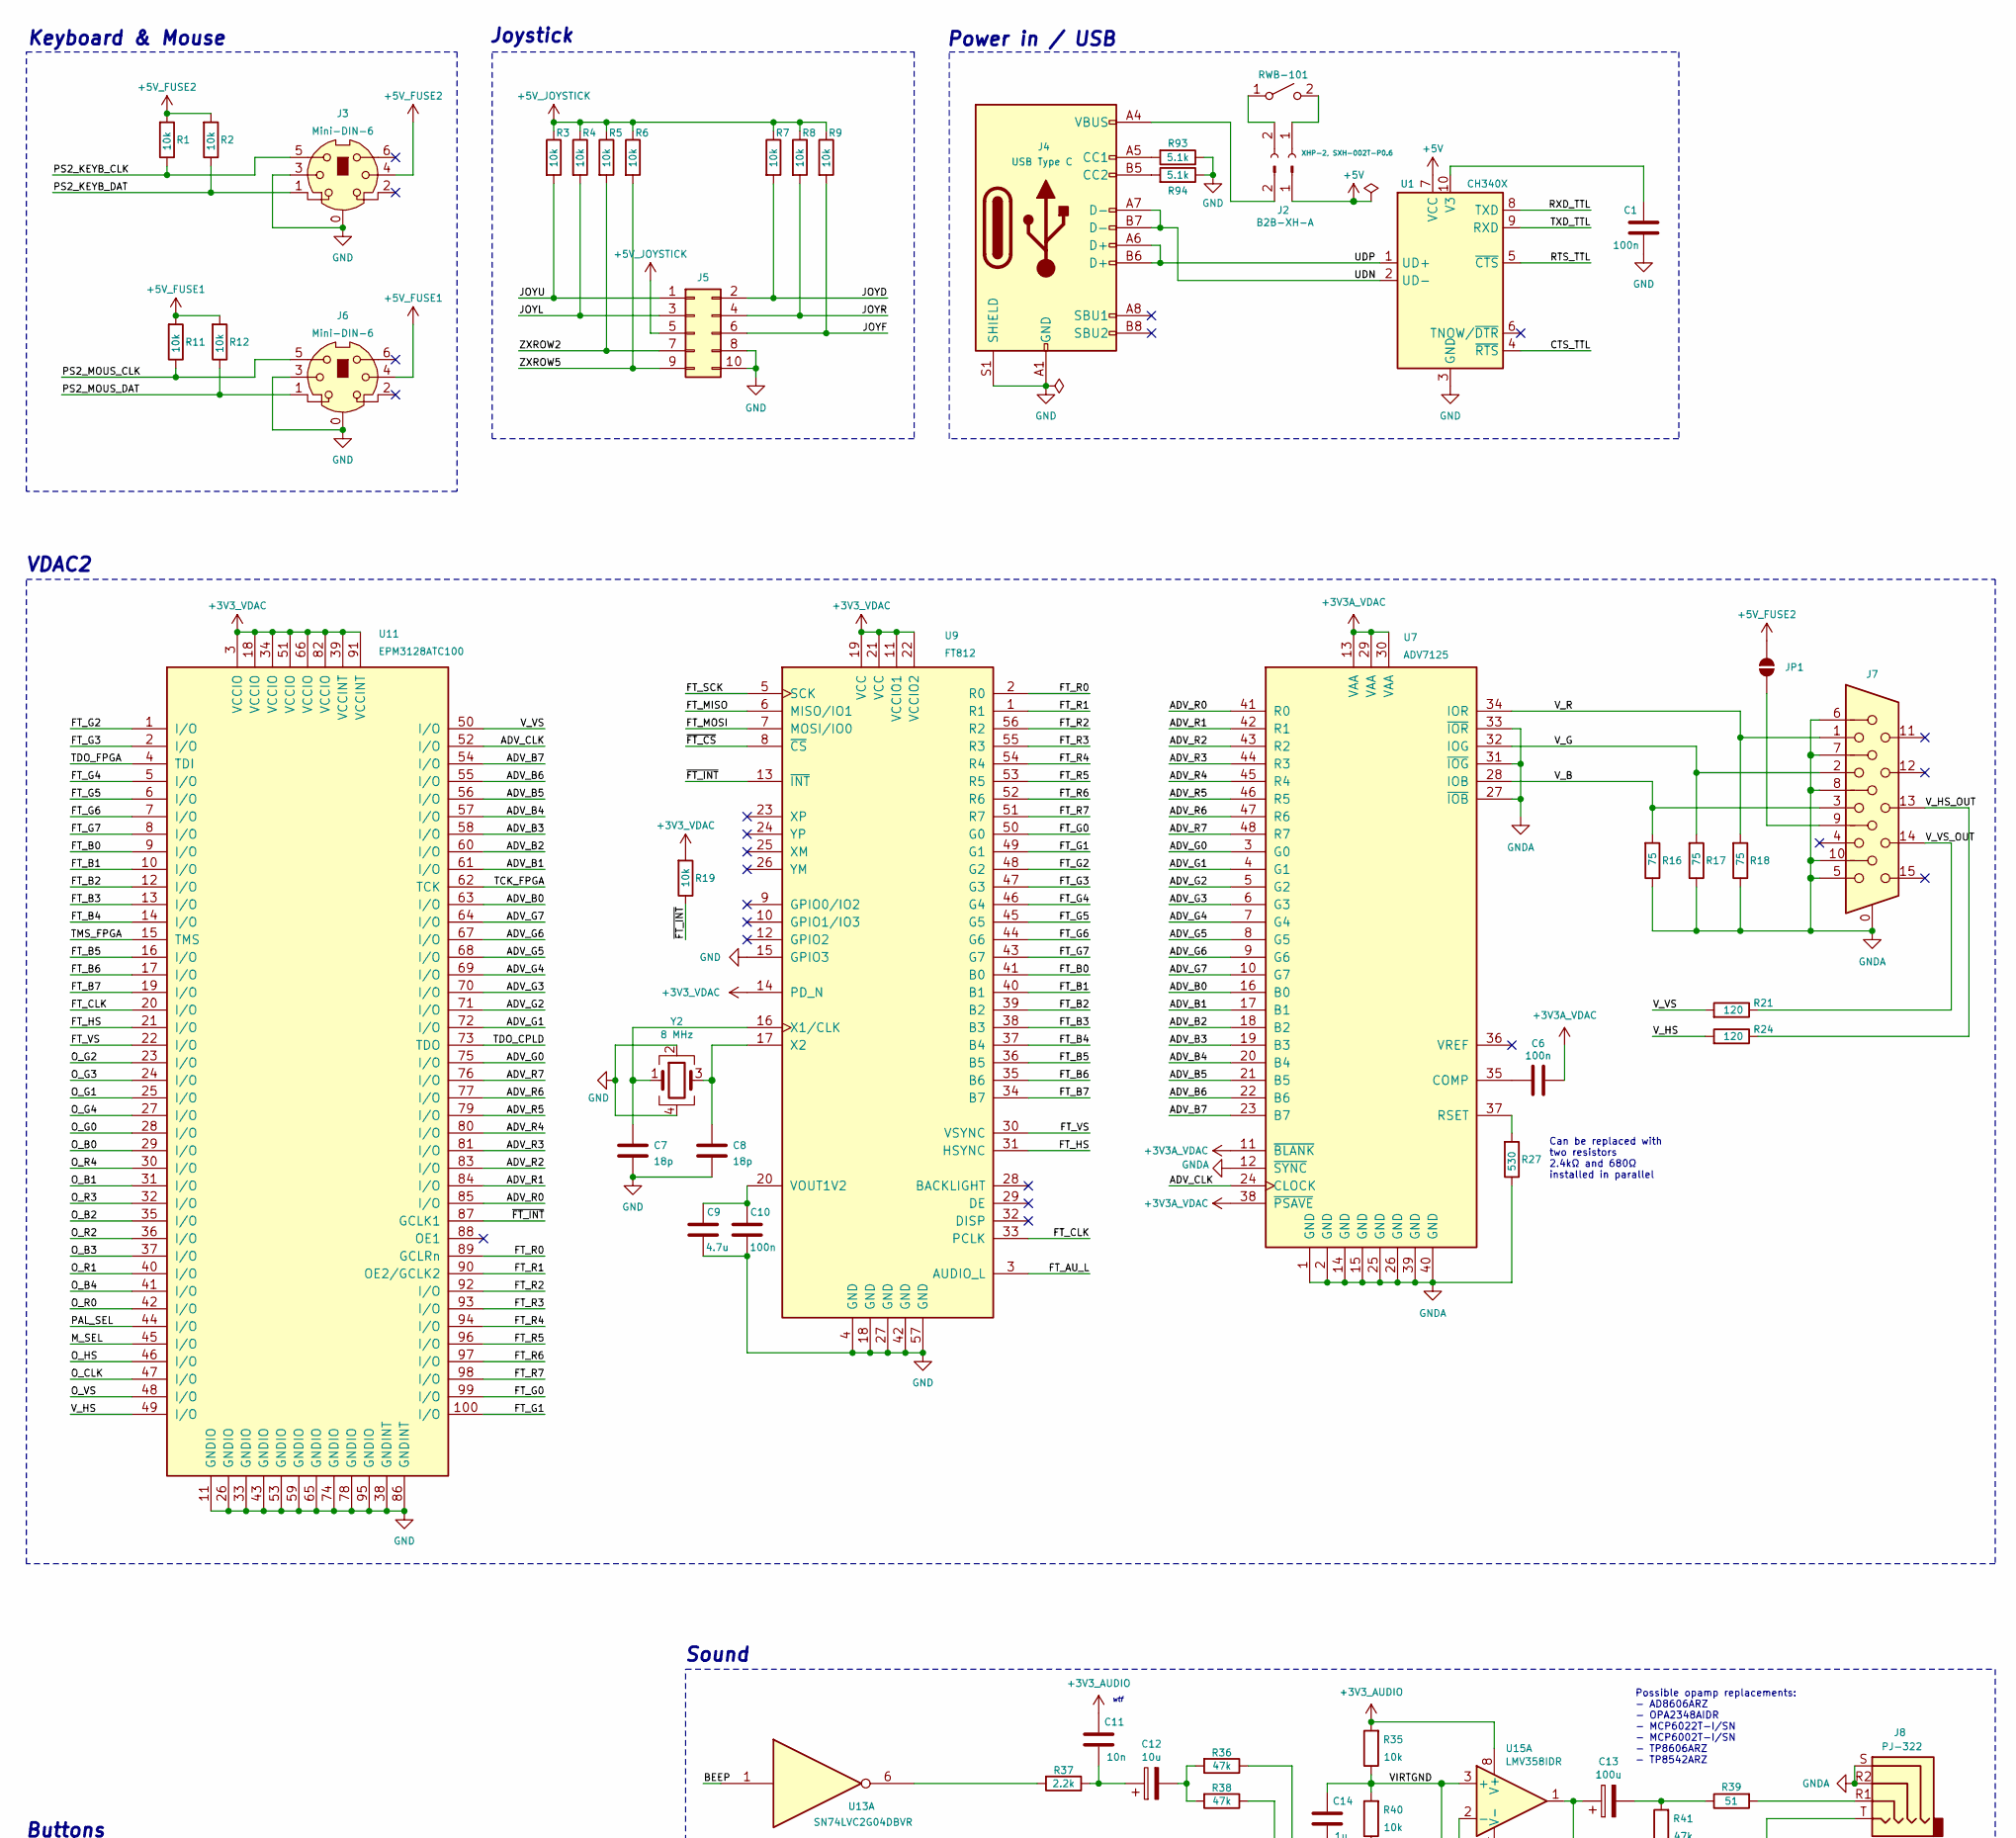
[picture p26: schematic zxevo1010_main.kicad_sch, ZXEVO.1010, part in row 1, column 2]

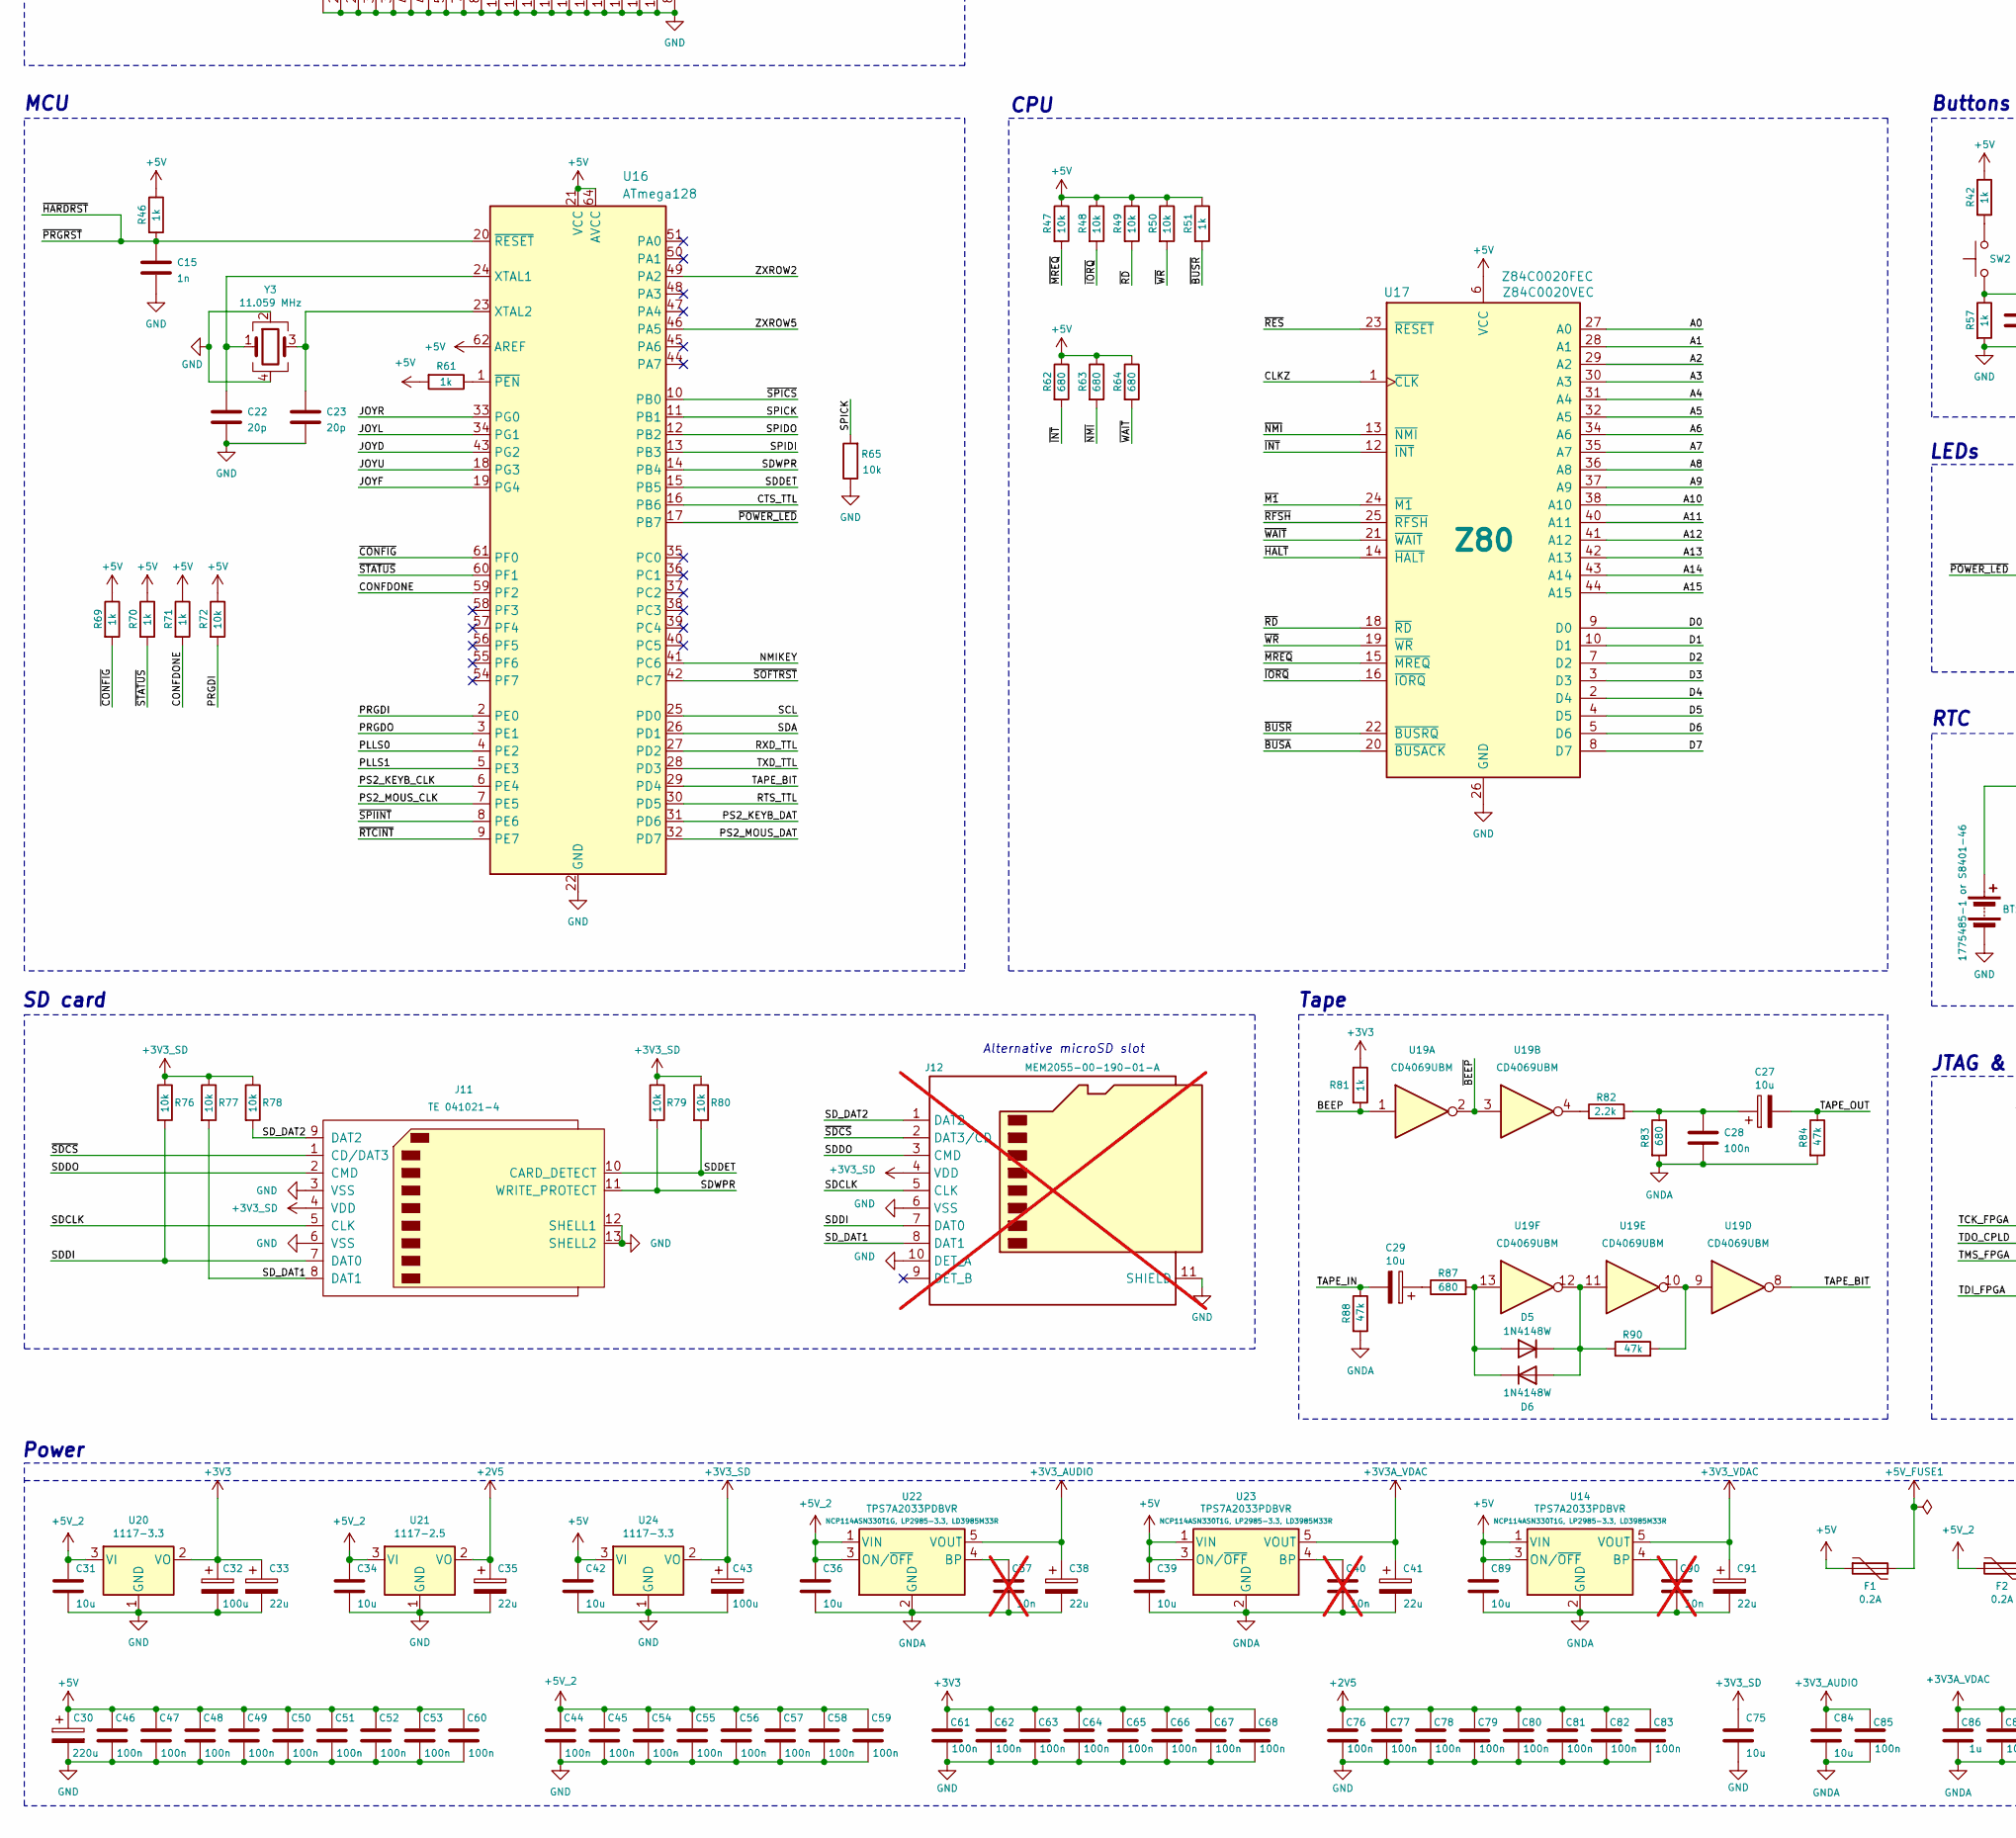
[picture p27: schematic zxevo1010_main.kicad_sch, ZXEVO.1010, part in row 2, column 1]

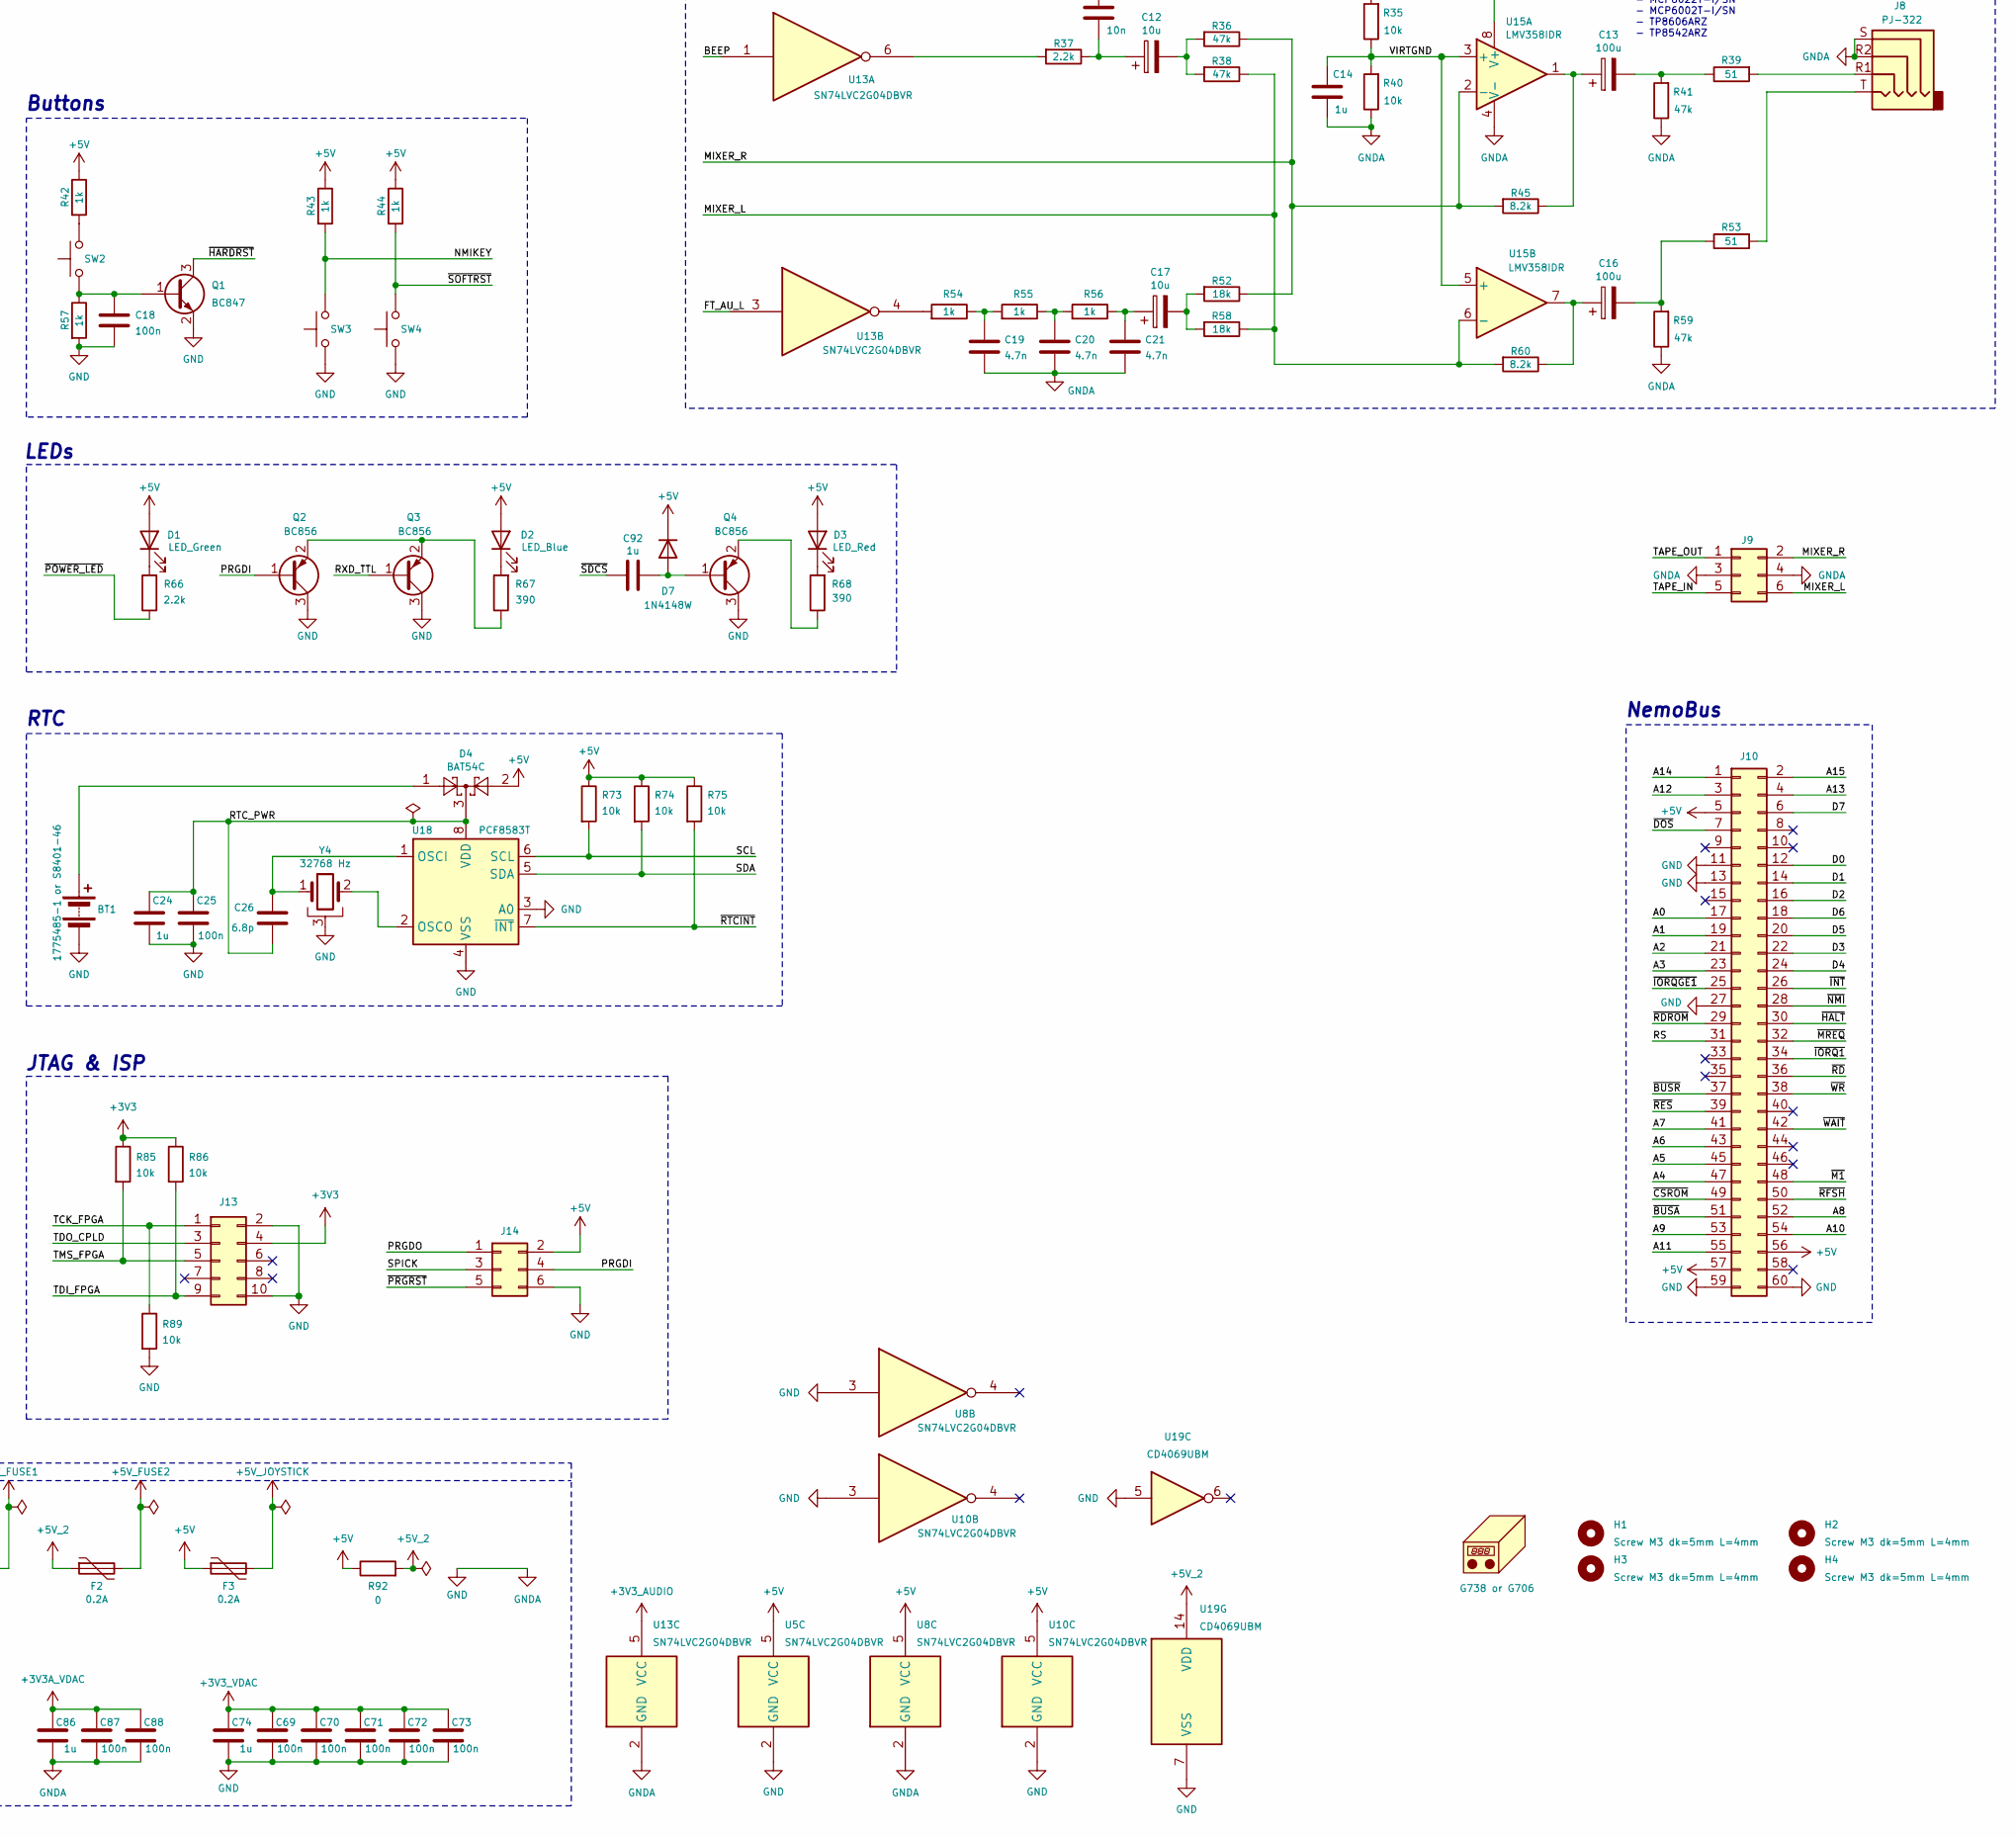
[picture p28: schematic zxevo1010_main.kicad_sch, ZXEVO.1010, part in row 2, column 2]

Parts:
BT1: 1775485-1 or S8401-46; CR2032V
C1, C6, C10, C18, C25, C28, C44, C45, C46, C47, C48, C49, C50, C51, C52, C53, C54, C55, C56, C57, C58, C59, C60, C69, C70, C71, C72, C73, C85, C87, C88: 100n; C_0603_1608Metric_Pad1.08x0.95mm_HandSolder
C2, C3, C4, C5, C22, C23: 20p; C_0603_1608Metric_Pad1.08x0.95mm_HandSolder
C7, C8: 18p; C_0603_1608Metric_Pad1.08x0.95mm_HandSolder
C9: 4.7u; C_0603_1608Metric_Pad1.08x0.95mm_HandSolder
C11: 10n; C_0603_1608Metric_Pad1.08x0.95mm_HandSolder
C12, C17, C27, C29: 10u; CP_EIA-3216-18_Kemet-A_Pad1.58x1.35mm_HandSolder
C13, C16, C32, C43: 100u; CP_EIA-6032-28_Kemet-C_Pad2.25x2.35mm_HandSolder
C14, C24, C74, C86, C92: 1u; C_0603_1608Metric_Pad1.08x0.95mm_HandSolder
C15: 1n; C_0603_1608Metric_Pad1.08x0.95mm_HandSolder
C19, C20, C21: 4.7n; C_0603_1608Metric_Pad1.08x0.95mm_HandSolder
C26: 6.8p; C_0603_1608Metric_Pad1.08x0.95mm_HandSolder
C30: 220u; CP_Elec_6.3x7.7
C31, C34, C36, C39, C42, C75, C84, C89: 10u; C_0805_2012Metric_Pad1.18x1.45mm_HandSolder
C33, C35, C38, C41, C91: 22u; CP_EIA-3216-18_Kemet-A_Pad1.58x1.35mm_HandSolder
C37, C40, C90: 10n; C_0603_1608Metric_Pad1.08x0.95mm_HandSolder; not fitted
C61, C62, C63, C64, C65, C66, C67, C68, C76, C77, C78, C79, C80, C81, C82, C83: 100n; C_0805_2012Metric_Pad1.18x1.45mm_HandSolder
D1: LED_Green; LED_D5.0mm_Horizontal_O1.27mm_Z3.0mm
D2: LED_Blue; LED_D5.0mm_Horizontal_O1.27mm_Z3.0mm
D3: LED_Red; LED_D5.0mm_Horizontal_O1.27mm_Z3.0mm
D4: BAT54C; SOT-23
D5, D6, D7: 1N4148W; D_SOD-123
F1, F2, F3: 0.2A; Fuse_1812_4532Metric_Pad1.30x3.40mm_HandSolder
H1, H2, H3, H4: Screw M3 dk=5mm L=4mm; MountingHole_3.2mm_M3_dk5.2mm_Mask
J1: XHP-2, SXH-002T-P0.6
J2: B2B-XH-A; JST_XH_B2B-XH-A_1x02_P2.50mm_Vertical
J3, J6: Mini-DIN-6; minidin-6
J4: USB Type C; USB_C_Receptacle_HRO_TYPE-C-31-M-12_dangling
J5, J13: Conn_02x05_Odd_Even; PinHeader_2x05_P2.54mm_Vertical
J7: DB15_Female_HighDensity_MountingHoles; DSUB-15-HD_Female_Horizontal_P2.29x1.98mm_EdgePinOffset3.03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
J8: PJ-322
J9, J14: Conn_02x05_Odd_Even; PinHeader_2x03_P2.54mm_Vertical
J10: Conn_02x30_Row_Letter_First; PinSocket_2x30_P2.54mm_Vertical
J11: TE 041021-4; SD_TE_2041021-mod
J12: MEM2055-00-190-01-A; GCT-MEM2055-00-190-01-A; not fitted
JP1: SolderJumper_2_Open; SolderJumper-2_P1.3mm_Open_RoundedPad1.0x1.5mm
N1: G738 or G706; g738-g706
Q1: BC847; SOT-23
Q2, Q3, Q4: BC856; SOT-23
R1, R2, R3, R4, R5, R6, R7, R8, R9, R11, R12, R19, R22, R28, R35, R40, R47, R48, R49, R50, R65, R72, R73, R74, R75, R76, R77, R78, R79, R80, R85, R86, R89: 10k; R_0603_1608Metric_Pad0.98x0.95mm_HandSolder
R10, R13, R14, R23, R25, R26, R30, R31, R32, R39, R53, R91: 51; R_0603_1608Metric_Pad0.98x0.95mm_HandSolder
R15, R29, R33, R34, R62, R63, R64, R83, R87: 680; R_0603_1608Metric_Pad0.98x0.95mm_HandSolder
R16, R17, R18: 75; R_0603_1608Metric_Pad0.98x0.95mm_HandSolder
R20, R42, R43, R44, R46, R51, R54, R55, R56, R57, R61, R69, R70, R71, R81: 1k; R_0603_1608Metric_Pad0.98x0.95mm_HandSolder
R21, R24: 120; R_0603_1608Metric_Pad0.98x0.95mm_HandSolder
R27: 530; R_0603_1608Metric_Pad0.98x0.95mm_HandSolder
R36, R38, R41, R59, R84, R88, R90: 47k; R_0603_1608Metric_Pad0.98x0.95mm_HandSolder
R37, R66, R82: 2.2k; R_0603_1608Metric_Pad0.98x0.95mm_HandSolder
R45, R60: 8.2k; R_0603_1608Metric_Pad0.98x0.95mm_HandSolder
R52, R58: 18k; R_0603_1608Metric_Pad0.98x0.95mm_HandSolder
R67, R68: 390; R_0603_1608Metric_Pad0.98x0.95mm_HandSolder
R92: 0; R_1206_3216Metric
R93, R94: 5.1k; R_0603_1608Metric_Pad0.98x0.95mm_HandSolder
SW1: RWB-101
SW2, SW3, SW4: Push angle button, 6x6x7mm or 6x6x8mm; SW_Tactile_SPST_Angled_PTS645Vx58-2LFS
U1: CH340X; MSOP-10_3x3mm_P0.5mm
U2, U3: HY5118160; TSOP-II-44-50_P0.8mm
U4: ICS501; SOIC-8_3.9x4.9mm_P1.27mm
U5, U8, U10, U13: SN74LVC2G04DBVR; SOT-23-6_Handsoldering
U6: EP1K50QC208; PQFP-208_28x28mm_P0.5mm_LongPads
U7: ADV7125; TQFP-48_7x7mm_P0.5mm
U9: FT812; QFN-56-1EP_8x8mm_P0.5mm_EP4.3x4.3mm
U11: EPM3128ATC100; TQFP-100_14x14mm_P0.5mm
U12: 29F040; PLCC-32_11.4x14.0mm_P1.27mm-longpads
U14, U22, U23: TPS7A2033PDBVR; SOT-23-5_HandSoldering
U15: LMV358IDR; SOIC-8_3.9x4.9mm_P1.27mm
U16: ATmega128; TQFP-64_14x14mm_P0.8mm
U17: Z84C0020FEC; Z80_FEC_VEC
U18: PCF8583T; SOT176-1
U19: CD4069UBM; SO-14_3.9x8.65mm_P1.27mm
U20, U24: 1117-3.3; SOT-223-3_TabPin2
U21: 1117-2.5; SOT-223-3_TabPin2
Y1: 14 MHz; Crystal_HC49-4H_Vertical
Y2: 8 MHz; Crystal_SMD_3225-4Pin_3.2x2.5mm_HandSoldering
Y3: 11.059 MHz; Crystal_SMD_3225-4Pin_3.2x2.5mm_HandSoldering
Y4: 32768 Hz; Crystal_C38-LF_D3.0mm_L8.0mm_Horizontal_1EP_style2

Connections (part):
+2V5: C35.1, C76.1, C77.1, C78.1, C79.1, C80.1, C81.1, C82.1, C83.1, U6.21 (VCCINT), U6.33 (VCCINT), U6.48 (VCCINT), U6.72 (VCCINT), U6.77 (VCC_CKLK), U6.91 (VCCINT), U6.106 (VCCINT), U6.124 (VCCINT), U6.130 (VCCINT), U6.152 (VCCINT), U6.185 (VCCINT), U6.201 (VCCINT), U21.2 (VO)
+3V3: C32.1, C33.1, C61.1, C62.1, C63.1, C64.1, C65.1, C66.1, C67.1, C68.1, J13.4, R22.1, R81.1, R85.1, R86.1, U6.5 (VCCIO), U6.22 (VCCIO), U6.34 (VCCIO), U6.42 (VCCIO), U6.51 (TRST), U6.63 (IO), U6.64 (IO), U6.66 (VCCIO), U6.68 (IO), U6.84 (VCCIO), U6.98 (VCCIO), U6.110 (VCCIO), U6.118 (VCCIO), U6.138 (VCCIO), U6.146 (VCCIO), U6.165 (VCCIO), U6.178 (VCCIO), U6.194 (VCCIO), U20.2 (VO)
+3V3A_VDAC: C6.1, C41.1, C86.1, C87.1, C88.1, U7.11 (~BLANK), U7.13 (VAA), U7.29 (VAA), U7.30 (VAA), U7.38 (~PSAVE), U23.5 (VOUT)
+3V3_AUDIO: C11.2, C38.1, C84.2, C85.1, R35.2, U13.5 (VCC), U15.8 (V+), U22.5 (VOUT)
+3V3_SD: C43.1, C75.2, J11.4 (VDD), J12.4 (VDD), R76.1, R77.1, R78.1, R79.1, R80.1, U24.2 (VO)
+3V3_VDAC: C69.1, C70.1, C71.1, C72.1, C73.1, C74.1, C91.1, R19.2, U9.11 (VCCIO1), U9.14 (PD_N), U9.19 (VCC), U9.21 (VCC), U9.22 (VCCIO2), U11.3 (VCCIO), U11.18 (VCCIO), U11.34 (VCCIO), U11.39 (VCCINT), U11.51 (VCCIO), U11.66 (VCCIO), U11.82 (VCCIO), U11.91 (VCCINT), U14.5 (VOUT)
+5V: C30.1, C39.2, C42.2, C46.2, C47.2, C48.2, C49.2, C50.2, C51.2, C52.2, C53.2, C60.2, C89.2, D1.2 (A), D2.2 (A), D3.2 (A), D4.2, D7.1 (K), F1.1, F3.1, J2.1, J10.5, J10.56, J10.57, J14.2, R28.1, R42.1, R43.1, R44.1, R46.1, R47.1, R48.1, R49.1, R50.1, R51.1, R61.2, R62.1, R63.1, R64.1, R69.1, R70.1, R71.1, R72.1, R73.1, R74.1, R75.1, R92.1, U1.7 (VCC), U5.5 (VCC), U8.5 (VCC), U10.5 (VCC), U12.32 (VCC), U14.1 (VIN), U14.3 (ON/~OFF), U16.21 (VCC), U16.52 (VCC), U16.62 (AREF), U16.64 (AVCC), U17.6 (VCC), U23.1 (VIN), U23.3 (ON/~OFF), U24.3 (VI)
+5V_2: C31.2, C34.2, C36.2, C44.2, C45.2, C54.2, C55.2, C56.2, C57.2, C58.2, C59.2, F2.1, R92.2, U2.1 (VCC), U2.6 (VCC), U2.25 (VCC), U3.1 (VCC), U3.6 (VCC), U3.25 (VCC), U4.2 (VDD), U4.7 (OE), U19.14 (VDD), U20.3 (VI), U21.3 (VI), U22.1 (VIN), U22.3 (ON/~OFF)
+5V_FUSE1: F1.2, J6.4, R11.2, R12.2
+5V_FUSE2: F2.2, J3.4, JP1.2 (B), R1.2, R2.2
+5V_JOYSTICK: F3.2, J5.5, R3.1, R4.1, R5.1, R6.1, R7.1, R8.1, R9.1
/A0: J10.17, U6.44 (IO), U12.12 (A0), U17.27 (A0)
/A1: J10.19, U6.41 (IO), U12.11 (A1), U17.28 (A1)
/A2: J10.21, U6.40 (IO), U12.10 (A2), U17.29 (A2)
/A3: J10.23, U6.39 (IO), U12.9 (A3), U17.30 (A3)
/A4: J10.47, U6.38 (IO), U12.8 (A4), U17.31 (A4)
/A5: J10.45, U6.37 (IO), U12.7 (A5), U17.32 (A5)
/A6: J10.43, U6.36 (IO), U12.6 (A6), U17.34 (A6)
/A7: J10.41, U6.31 (IO), U12.5 (A7), U17.35 (A7)
/A8: J10.52, U6.30 (IO), U12.27 (A8), U17.36 (A8)
/A9: J10.53, U6.29 (IO), U12.26 (A9), U17.37 (A9)
/A10: J10.54, U6.28 (IO), U12.23 (A10), U17.38 (A10)
/A11: J10.55, U6.27 (IO), U12.25 (A11), U17.40 (A11)
/A12: J10.3, U6.26 (IO), U12.4 (A12), U17.41 (A12)
/A13: J10.4, U6.25 (IO), U12.28 (A13), U17.42 (A13)
/A14: J10.1, U6.24 (IO), U17.43 (A14)
/A15: J10.2, U6.19 (IO/INIT_DONE), U17.44 (A15)
/ADV_B0: U7.16 (B0), U11.63 (I/O)
/ADV_B1: U7.17 (B1), U11.61 (I/O)
/ADV_B2: U7.18 (B2), U11.60 (I/O)
/ADV_B3: U7.19 (B3), U11.58 (I/O)
/ADV_B4: U7.20 (B4), U11.57 (I/O)
/ADV_B5: U7.21 (B5), U11.56 (I/O)
/ADV_B6: U7.22 (B6), U11.55 (I/O)
/ADV_B7: U7.23 (B7), U11.54 (I/O)
/ADV_CLK: U7.24 (CLOCK), U11.52 (I/O)
/ADV_G0: U7.3 (G0), U11.75 (I/O)
/ADV_G1: U7.4 (G1), U11.72 (I/O)
/ADV_G2: U7.5 (G2), U11.71 (I/O)
/ADV_G3: U7.6 (G3), U11.70 (I/O)
/ADV_G4: U7.7 (G4), U11.69 (I/O)
/ADV_G5: U7.8 (G5), U11.68 (I/O)
/ADV_G6: U7.9 (G6), U11.67 (I/O)
/ADV_G7: U7.10 (G7), U11.64 (I/O)
/ADV_R0: U7.41 (R0), U11.85 (I/O)
/ADV_R1: U7.42 (R1), U11.84 (I/O)
/ADV_R2: U7.43 (R2), U11.83 (I/O)
/ADV_R3: U7.44 (R3), U11.81 (I/O)
/ADV_R4: U7.45 (R4), U11.80 (I/O)
/ADV_R5: U7.46 (R5), U11.79 (I/O)
/ADV_R6: U7.47 (R6), U11.77 (I/O)
/ADV_R7: U7.48 (R7), U11.76 (I/O)
/BEEP: R81.2, U6.133 (IO), U13.1, U19.1
/CLKZ: R26.1, U17.1 (~CLK)
/CLKZ_IN: R25.1, U6.79 (Dedicated_Clock/GCLK1)
/CLKZ_OUT: R13.1, U10.1
/CONFDONE: R71.2, U6.2 (CONF_DONE), U16.59 (PF2)
/CSROM: R20.1, U6.150 (IO), U8.1
/CTS_TTL: U1.4 (~RTS), U16.16 (PB6)
/D0: J10.12, U6.18 (IO), U12.13 (D0), U17.9 (D0)
/D1: J10.14, U6.17 (IO), U12.14 (D1), U17.10 (D1)
/D2: J10.16, U6.16 (IO/RDYnBUSY), U12.15 (D2), U17.7 (D2)
/D3: J10.22, U6.15 (IO), U12.17 (D3), U17.3 (D3)
/D4: J10.24, U6.14 (IO), U12.18 (D4), U17.2 (D4)
/D5: J10.20, U6.13 (IO), U12.19 (D5), U17.4 (D5)
/D6: J10.18, U6.12 (IO), U12.20 (D6), U17.5 (D6)
/D7: J10.6, U6.11 (IO), U12.21 (D7), U17.8 (D7)
/FCLK: R14.1, U6.183 (Dedicated_Clock)
/FT_AU_L: U9.3 (AUDIO_L), U13.3
/FT_B0: U9.41 (B0), U11.9 (I/O)
/FT_B1: U9.40 (B1), U11.10 (I/O)
/FT_B2: U9.39 (B2), U11.12 (I/O)
/FT_B3: U9.38 (B3), U11.13 (I/O)
/FT_B4: U9.37 (B4), U11.14 (I/O)
/FT_B5: U9.36 (B5), U11.16 (I/O)
/FT_B6: U9.35 (B6), U11.17 (I/O)
/FT_B7: U9.34 (B7), U11.19 (I/O)
/FT_CLK: U9.33 (PCLK), U11.20 (I/O)
/FT_G0: U9.50 (G0), U11.99 (I/O)
/FT_G1: U9.49 (G1), U11.100 (I/O)
/FT_G2: U9.48 (G2), U11.1 (I/O)
/FT_G3: U9.47 (G3), U11.2 (I/O)
/FT_G4: U9.46 (G4), U11.5 (I/O)
/FT_G5: U9.45 (G5), U11.6 (I/O)
/FT_G6: U9.44 (G6), U11.7 (I/O)
/FT_G7: U9.43 (G7), U11.8 (I/O)
/FT_HS: U9.31 (HSYNC), U11.21 (I/O)
/FT_MISO: U6.99 (IO), U9.6 (MISO/IO1)
/FT_MOSI: U6.103 (IO), U9.7 (MOSI/IO0)
/FT_R0: U9.2 (R0), U11.89 (GCLRn)
/FT_R1: U9.1 (R1), U11.90 (OE2/GCLK2)
/FT_R2: U9.56 (R2), U11.92 (I/O)
/FT_R3: U9.55 (R3), U11.93 (I/O)
/FT_R4: U9.54 (R4), U11.94 (I/O)
/FT_R5: U9.53 (R5), U11.96 (I/O)
/FT_R6: U9.52 (R6), U11.97 (I/O)
/FT_R7: U9.51 (R7), U11.98 (I/O)
/FT_SCK: R91.1, U9.5 (SCK)
/FT_VS: U9.30 (VSYNC), U11.22 (I/O)
/JOYD: J5.2, R7.2, U16.43 (PG2)
/JOYF: J5.6, R9.2, U16.19 (PG4)
/JOYL: J5.3, R4.2, U16.34 (PG1)
/JOYR: J5.4, R8.2, U16.33 (PG0)
/JOYU: J5.1, R3.2, U16.18 (PG3)
/MIXER_L: J9.6, R38.1, R58.1, R60.2, U15.6 (-)
/MIXER_R: J9.2, R36.1, R45.2, R52.1, U15.2 (-)
/M_SEL: U6.100 (IO), U11.45 (I/O)
/NMIKEY: R43.2, SW3.1, U16.41 (PC6)
/O_B0: U6.83 (IO), U11.29 (I/O)
/O_B1: U6.86 (IO), U11.31 (I/O)
/O_B2: U6.88 (IO), U11.35 (I/O)
/O_B3: U6.90 (IO), U11.37 (I/O)
/O_B4: U6.93 (IO), U11.41 (I/O)
/O_CLK: U6.111 (IO), U11.47 (I/O)
/O_G0: U6.75 (IO), U11.28 (I/O)
/O_G1: U6.73 (IO), U11.25 (I/O)
/O_G2: U6.96 (IO), U11.23 (I/O)
/O_G3: U6.71 (IO), U11.24 (I/O)
/O_G4: U6.74 (IO), U11.27 (I/O)
/O_HS: U6.113 (IO), U11.46 (I/O)
/O_R0: U6.94 (IO), U11.42 (I/O)
/O_R1: U6.92 (IO), U11.40 (I/O)
/O_R2: U6.89 (IO), U11.36 (I/O)
/O_R3: U6.87 (IO), U11.32 (I/O)
/O_R4: U6.85 (IO), U11.30 (I/O)
/O_VS: U6.112 (IO), U11.48 (I/O)
/PAL_SEL: U6.95 (IO), U11.44 (I/O)
/PLLS0: U4.6 (S0), U16.4 (PE2)
/PLLS1: U4.4 (S1), U16.5 (PE3)
/PRGDI: J14.4, Q2.1 (B), R72.2, U16.2 (PE0)
/PRGDO: J14.1, U16.3 (PE1)
/PS2_KEYB_CLK: J3.5, R1.1, U16.6 (PE4)
/PS2_KEYB_DAT: J3.1, R2.1, U16.31 (PD6)
/PS2_MOUS_CLK: J6.5, R11.1, U16.7 (PE5)
/PS2_MOUS_DAT: J6.1, R12.1, U16.32 (PD7)
/RA0: U2.21 (MA0), U3.21 (MA0), U6.177 (IO)
/RA1: U2.22 (MA1), U3.22 (MA1), U6.175 (IO)
/RA2: U2.23 (MA2), U3.23 (MA2), U6.173 (IO)
/RA3: U2.24 (MA3), U3.24 (MA3), U6.170 (IO)
/RA4: U2.27 (MA4), U3.27 (MA4), U6.169 (IO)
/RA5: U2.28 (MA5), U3.28 (MA5), U6.172 (IO)
/RA6: U2.29 (MA6), U3.29 (MA6), U6.174 (IO)
/RA7: U2.30 (MA7), U3.30 (MA7), U6.176 (IO)
/RA8: U2.31 (MA8), U3.31 (MA8), U6.179 (IO)
/RA9: U2.32 (MA9), U3.32 (MA9), U6.180 (IO/DEV_CLRn)
/RD0: U2.2 (DQ0), U3.2 (DQ0), U6.208 (IO/nCS)
/RD1: U2.3 (DQ1), U3.3 (DQ1), U6.206 (IO/nWS)
/RD2: U2.4 (DQ2), U3.4 (DQ2), U6.204 (IO/nRS)
/RD3: U2.5 (DQ3), U3.5 (DQ3), U6.202 (IO)
/RD4: U2.7 (DQ4), U3.7 (DQ4), U6.199 (IO)
/RD5: U2.8 (DQ5), U3.8 (DQ5), U6.197 (IO)
/RD6: U2.9 (DQ6), U3.9 (DQ6), U6.195 (IO)
/RD7: U2.10 (DQ7), U3.10 (DQ7), U6.192 (IO)
/RD8: U2.41 (DQ8), U3.41 (DQ8), U6.191 (IO)
/RD9: U2.42 (DQ9), U3.42 (DQ9), U6.193 (IO)
/RD10: U2.43 (DQ10), U3.43 (DQ10), U6.196 (IO)
/RD11: U2.44 (DQ11), U3.44 (DQ11), U6.198 (IO)
/RD12: U2.46 (DQ12), U3.46 (DQ12), U6.200 (IO)
/RD13: U2.47 (DQ13), U3.47 (DQ13), U6.203 (IO)
/RD14: U2.48 (DQ14), U3.48 (DQ14), U6.205 (IO)
/RD15: U2.49 (DQ15), U3.49 (DQ15), U6.207 (IO/CS)
/RES: R28.2, U5.3, U6.142 (IO)
/ROMPG2: U6.164 (IO/DATA6), U12.2 (A16)
/ROMPG3: U6.163 (IO), U12.30 (A17)
/ROMPG4: U6.162 (IO/DATA5), U12.1 (A18)
/RS: J10.31, R15.1, U12.29 (A14)
/RTC_PWR: C24.2, C25.2, C26.2, D4.3, U18.8 (VDD)
/RTS_TTL: U1.5 (~CTS), U16.30 (PD5)
/RXD_TTL: Q3.1 (B), U1.8 (TXD), U16.27 (PD2)
/SCL: R73.2, U16.25 (PD0), U18.6 (SCL)
/SDA: R74.2, U16.26 (PD1), U18.5 (SDA)
/SDCLK: J11.5 (CLK), J12.5 (CLK), R10.2
/SDDET: J11.10 (CARD_DETECT), R80.2, U16.15 (PB5)
/SDDI: J11.7 (DAT0), J12.7 (DAT0), R76.2, U6.115 (IO)
/SDDO: J11.2 (CMD), J12.3 (CMD), U6.116 (IO)
/SDWPR: J11.11 (WRITE_PROTECT), R79.2, U16.14 (PB4)
/SD_DAT1: J11.8 (DAT1), J12.8 (DAT1), R77.2
/SD_DAT2: J11.9 (DAT2), J12.1 (DAT2), R78.2
/SPICK: J14.3, R65.2, U6.155 (DCLK), U6.184 (Dedicated_Input), U16.11 (PB1)
/SPIDI: U6.158 (IO/DATA2), U16.13 (PB3)
/SPIDO: U6.156 (DATA0), U6.157 (IO/DATA1), U16.12 (PB2)
/TAPE_BIT: U16.29 (PD4), U19.8
/TAPE_IN: C29.2, J9.5, R88.1
/TAPE_OUT: C27.2, J9.1, R84.1
/TCK_FPGA: J13.1, R89.1, U6.1 (TCK), U11.62 (TCK)
/TDI_FPGA: J13.9, R86.2, U6.153 (TDI)
/TDO_CPLD: J13.3, U11.73 (TDO)
/TDO_FPGA: U6.4 (TDO), U11.4 (TDI)
/TMS_FPGA: J13.5, R85.2, U6.50 (TMS), U11.15 (TMS)
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

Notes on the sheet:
CPU
VDAC2
wtf
Can be replaced with two resistors 2.4kΩ and 680Ω installed in parallel
RAM 4Mb
Keyboard & Mouse
JTAG & ISP
Buttons
LEDs
NemoBus
RTC
SD card
ROM 512Kb
Possible opamp replacements: - AD8606ARZ - OPA2348AIDR - MCP6022T-I/SN - MCP6002T-I/SN - TP8606ARZ - TP8542ARZ
Clock
Tape
MCU
Sound
Joystick
Power in / USB
Alternative microSD slot
Power
FPGA

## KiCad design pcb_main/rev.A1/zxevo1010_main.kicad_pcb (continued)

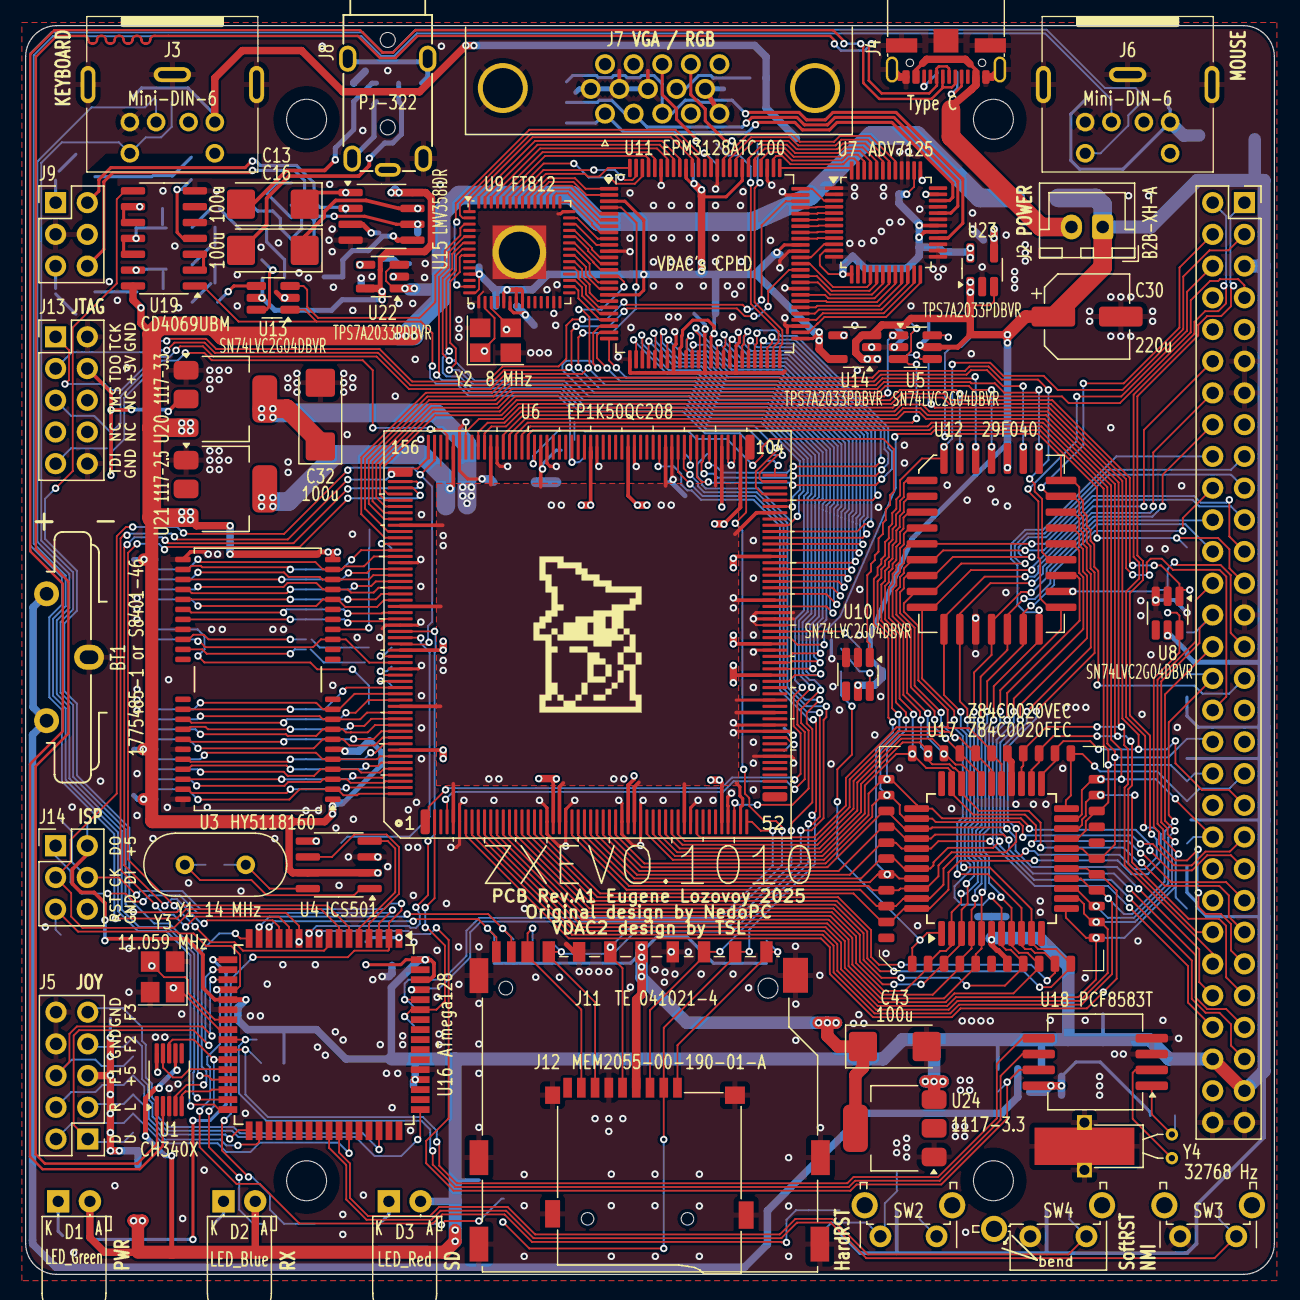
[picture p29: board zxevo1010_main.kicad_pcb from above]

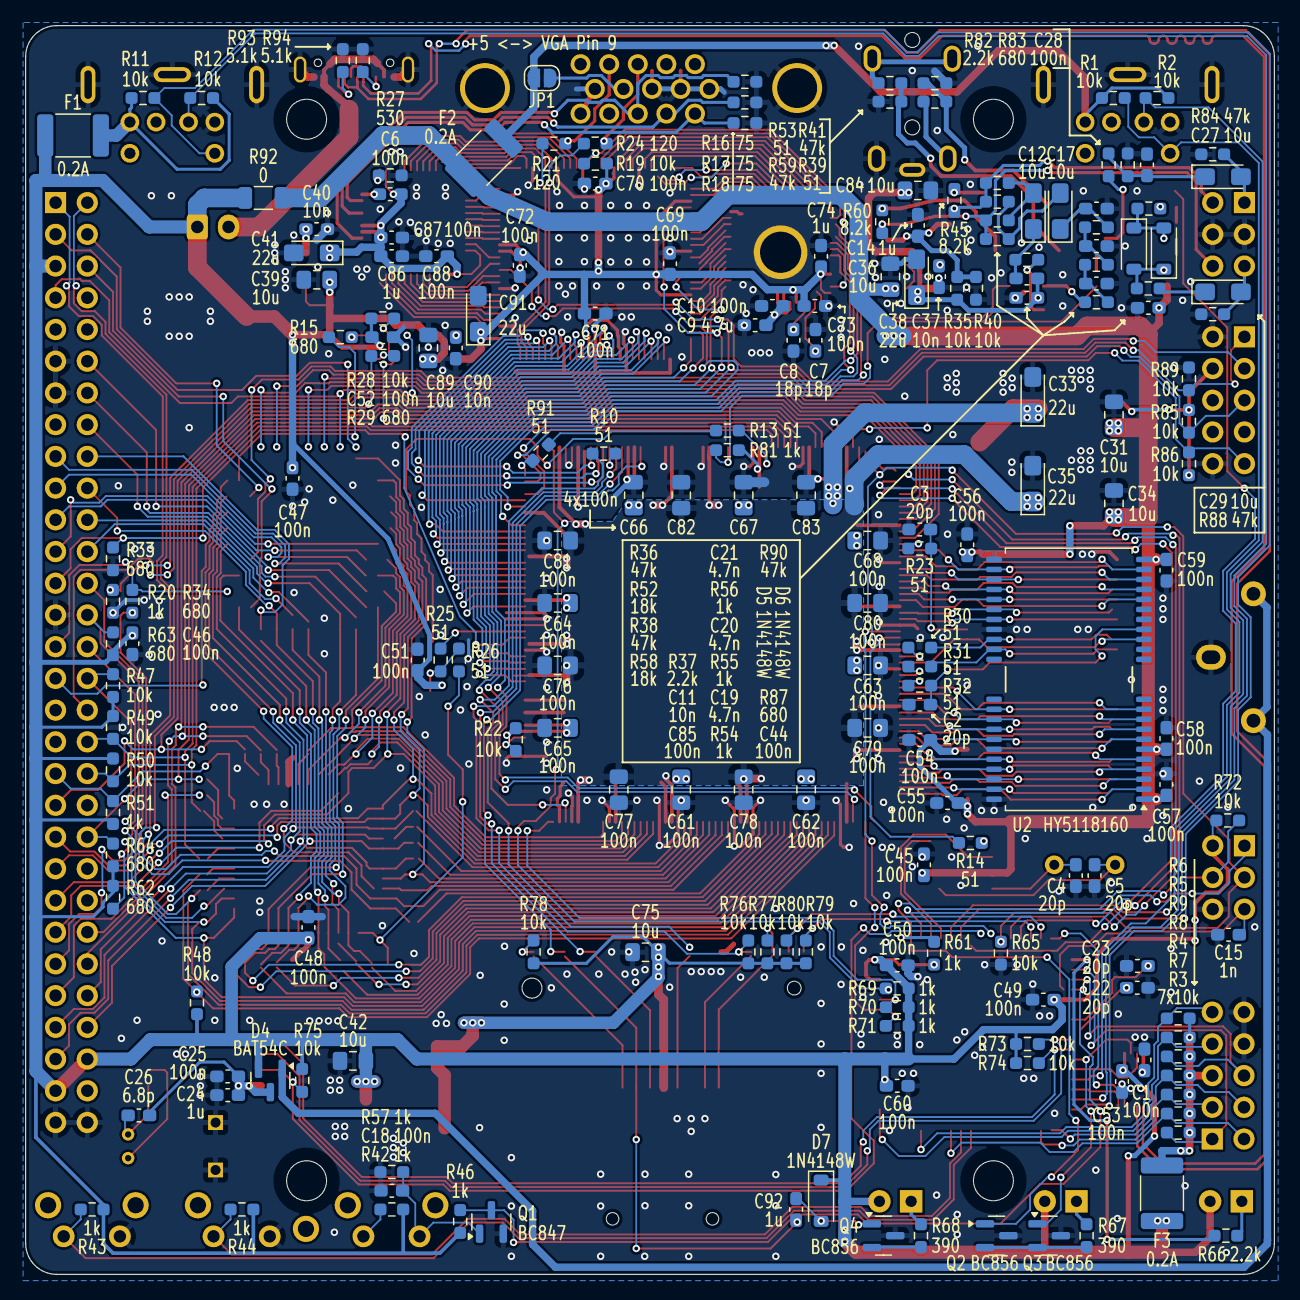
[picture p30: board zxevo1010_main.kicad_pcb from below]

Board: 2 copper layers, 100.0 x 100.0 mm, 252 parts (194 on the bottom side), 302 nets.

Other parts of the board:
LOGO1: graphic; black-mage-12.5x8.6-r

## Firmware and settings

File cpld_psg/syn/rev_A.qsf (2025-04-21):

# -------------------------------------------------------------------------- #
#
# Copyright (C) 1991-2013 Altera Corporation
# Your use of Altera Corporation's design tools, logic functions 
# and other software and tools, and its AMPP partner logic 
# functions, and any output files from any of the foregoing 
# (including device programming or simulation files), and any 
# associated documentation or information are expressly subject 
# to the terms and conditions of the Altera Program License 
# Subscription Agreement, Altera MegaCore Function License 
# Agreement, or other applicable license agreement, including, 
# without limitation, that your use is for the sole purpose of 
# programming logic devices manufactured by Altera and sold by 
# Altera or its authorized distributors.  Please refer to the 
# applicable agreement for further details.
#
# -------------------------------------------------------------------------- #
#
# Quartus II 64-Bit
# Version 13.0.1 Build 232 06/12/2013 Service Pack 1 SJ Full Version
# Date created = 12:04:27  October 04, 2020
#
# -------------------------------------------------------------------------- #
#
# Notes:
#
# 1) The default values for assignments are stored in the file:
#		zxevo1010_psg_assignment_defaults.qdf
#    If this file doesn't exist, see file:
#		assignment_defaults.qdf
#
# 2) Altera recommends that you do not modify this file. This
#    file is updated automatically by the Quartus II software
#    and any changes you make may be lost or overwritten.
#
# -------------------------------------------------------------------------- #


set_global_assignment -name FAMILY MAX3000A
set_global_assignment -name DEVICE "EPM3128ATC100-10"
set_global_assignment -name TOP_LEVEL_ENTITY zxevo1010_psg
set_global_assignment -name ORIGINAL_QUARTUS_VERSION "13.0 SP1"
set_global_assignment -name PROJECT_CREATION_TIME_DATE "12:04:27  OCTOBER 04, 2020"
set_global_assignment -name LAST_QUARTUS_VERSION "13.0 SP1"
set_global_assignment -name PROJECT_OUTPUT_DIRECTORY output
set_global_assignment -name DEVICE_FILTER_PIN_COUNT 100
set_global_assignment -name ERROR_CHECK_FREQUENCY_DIVISOR "-1"
set_global_assignment -name SDC_FILE clocks.sdc
set_global_assignment -name VHDL_INPUT_VERSION VHDL_2008
set_global_assignment -name VHDL_SHOW_LMF_MAPPING_MESSAGES OFF
set_global_assignment -name VERILOG_INPUT_VERSION SYSTEMVERILOG_2005
set_global_assignment -name VERILOG_SHOW_LMF_MAPPING_MESSAGES OFF
set_global_assignment -name MAX7000_DEVICE_IO_STANDARD "3.3-V LVTTL"
set_global_assignment -name SAVE_DISK_SPACE OFF
set_global_assignment -name TIMEQUEST_MULTICORNER_ANALYSIS OFF
set_global_assignment -name SYNTH_TIMING_DRIVEN_SYNTHESIS OFF
set_global_assignment -name MAX7000_OPTIMIZATION_TECHNIQUE SPEED
set_global_assignment -name PRE_MAPPING_RESYNTHESIS OFF
set_global_assignment -name OPTIMIZE_HOLD_TIMING OFF
set_global_assignment -name OPTIMIZE_MULTI_CORNER_TIMING ON
set_global_assignment -name FITTER_EFFORT "STANDARD FIT"
set_global_assignment -name RESERVE_ALL_UNUSED_PINS_NO_OUTPUT_GND "AS INPUT TRI-STATED"

set_location_assignment PIN_6 -to ymd[4]
set_location_assignment PIN_8 -to ymd[5]
set_location_assignment PIN_9 -to ymd[6]
set_location_assignment PIN_10 -to ymd[7]
set_location_assignment PIN_12 -to ymrst_n
set_location_assignment PIN_13 -to ymcs0_n
set_location_assignment PIN_14 -to ymcs1_n
set_location_assignment PIN_16 -to ymwr_n
set_location_assignment PIN_17 -to ymrd_n
set_location_assignment PIN_19 -to yma[0]
set_location_assignment PIN_20 -to yma[1]
set_location_assignment PIN_21 -to ymck
set_location_assignment PIN_23 -to sd_r_1bit
set_location_assignment PIN_25 -to sd_l_1bit
set_location_assignment PIN_30 -to zxd[7]
set_location_assignment PIN_31 -to zxd[0]
set_location_assignment PIN_32 -to zxd[1]
set_location_assignment PIN_35 -to zxd[2]
set_location_assignment PIN_36 -to zxd[6]
set_location_assignment PIN_37 -to zxd[5]
set_location_assignment PIN_40 -to zxd[3]
set_location_assignment PIN_41 -to zxd[4]
set_location_assignment PIN_42 -to zxm1_n
set_location_assignment PIN_44 -to zxal[4]
set_location_assignment PIN_45 -to zxal[5]
set_location_assignment PIN_46 -to zxal[6]
set_location_assignment PIN_47 -to zxal[7]
set_location_assignment PIN_48 -to zxwr_n
set_location_assignment PIN_52 -to zxrd_n
set_location_assignment PIN_54 -to zxmreq_n
set_location_assignment PIN_56 -to zxal[3]
set_location_assignment PIN_57 -to zxal[2]
set_location_assignment PIN_58 -to zxal[1]
set_location_assignment PIN_60 -to zxal[0]
set_location_assignment PIN_61 -to zxah[13]
set_location_assignment PIN_63 -to zxah[14]
set_location_assignment PIN_64 -to zxah[15]
set_location_assignment PIN_89 -to zxres_n
set_location_assignment PIN_90 -to clk
set_location_assignment PIN_92 -to midi_clk
set_location_assignment PIN_93 -to midi_rst_n
set_location_assignment PIN_94 -to midi_sense
set_location_assignment PIN_96 -to midi_data
set_location_assignment PIN_97 -to ymd[3]
set_location_assignment PIN_98 -to ymd[0]
set_location_assignment PIN_99 -to ymd[1]
set_location_assignment PIN_100 -to ymd[2]

set_global_assignment -name VERILOG_FILE ../rtl/top.v

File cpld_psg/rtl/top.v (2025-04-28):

module zxevo1010_psg(
    input clk,

    inout [7:0] zxd,
    input [7:0] zxal,
    input [15:13] zxah,
    input zxm1_n,
    input zxmreq_n,
    input zxrd_n,
    input zxres_n,
    input zxwr_n,

    output midi_clk,
    output reg midi_data,
    output midi_rst_n,
    input midi_sense,

    output ymcs0_n,
    output ymcs1_n,
    output ymrd_n,
    output ymwr_n,
    output ymrst_n,
    output ymck,
    output [1:0] yma,
    inout [7:0] ymd,

    output reg sd_r_1bit,
    output reg sd_l_1bit
);


wire rst_n = zxres_n;

// n_iorq are useless in zxevo :(
// so we're detecting n_iorq cycle by n_rd/n_wr signal asserted without n_m1/n_mreq
reg ioreq0, ioreq1, ioreq2;
always @(posedge clk) begin
    ioreq0 <= (zxrd_n == 1'b0 || zxwr_n == 1'b0) && zxm1_n == 1'b1 && zxmreq_n == 1'b1;
end
// two ioreq registers to make timequest happy
always @(negedge clk) begin
    ioreq1 <= ioreq0;
    ioreq2 <= ioreq0;
end


// n_dos are useless in zxevo :(
// so we're just lock some ports access when instruction has been fetched from rom
reg rom_m1_access;
always @(negedge clk) begin
    if (!rst_n)
        rom_m1_access <= 0;
    else if (zxm1_n == 0)
        rom_m1_access <= zxah[15:14] == 2'b00;
end



/* CLOCKS */
reg [4:0] clk7_cnt = 0;
always @(posedge clk) clk7_cnt <= clk7_cnt + 5'd7;
wire clk7 = clk7_cnt[4];

reg [2:0] clk12_cnt  = 0;
always @(posedge clk) clk12_cnt <= clk12_cnt  + 3'd3;
wire clk12  = clk12_cnt[2];



/* TURBO SOUND FM */
wire port_bffd = zxah[15:14] == 2'b10 && zxal[3:0] == 4'b1101;
wire port_fffd = zxah[15:14] == 2'b11 && zxal[3:0] == 4'b1101;
reg ym_chip_sel, ym_get_stat;
assign yma[0] = (~zxrd_n & zxah[14] & ~ym_get_stat) | (~zxwr_n & ~zxah[14]);
assign yma[1] = 1'b0; // TODO: possible to get extra FM channels there
assign ymcs0_n = ~(~ym_chip_sel && (port_bffd || port_fffd));
assign ymcs1_n = ~( ym_chip_sel && (port_bffd || port_fffd));

always @(posedge clk) begin
    if (!rst_n) begin
        ym_chip_sel <= 0;
        ym_get_stat <= 0;
    end
    else if (port_fffd && ioreq1 && ~zxwr_n && zxd[7:4] == 4'b1111) begin
        ym_chip_sel <= zxd[0];
        ym_get_stat <= ~zxd[1];
    end
end

assign ymrd_n = ~(ioreq1 && ~zxrd_n);
assign ymwr_n = ~(ioreq1 && ~zxwr_n);
assign ymrst_n = zxres_n;
assign ymck = clk7;
assign ymd = ~ymrd_n? 8'bzzzzzzzz : zxd;



/* TURBO SOUND FM IO PORTS */
reg ym_io_reg_en;

always @(posedge clk) begin
    if (!rst_n) begin
        ym_io_reg_en <= 1'b0;
    end
    else if (port_fffd && ioreq1 && ~zxwr_n) begin
        ym_io_reg_en <= zxd == 8'hE || zxd == 8'hF;
    end
end



/* MIDI */
reg midi_ext;
assign midi_rst_n = zxres_n & ~midi_ext;
assign midi_clk = clk12;
reg midi_reg_en;

always @(posedge clk) begin
    if (!rst_n) begin
        midi_data <= 1'b1;
        midi_reg_en <= 1'b0;
        midi_ext <= 1'b0;
    end
    else if (port_fffd && ioreq2 && ~zxwr_n) begin
        midi_reg_en <= zxd == 8'hE;
    end
    else if (port_bffd && ioreq2 && ~zxwr_n && midi_reg_en) begin
        if (!midi_data)
            midi_ext <= midi_sense;
        midi_data <= zxd[2];
    end
end



/* SOUNDRIVE */
reg [7:0] sd_ch0, sd_ch1, sd_ch2, sd_ch3;
always @(posedge clk) begin
    if (!rst_n) begin
        sd_ch0 <= 0;
        sd_ch1 <= 0;
        sd_ch2 <= 0;
        sd_ch3 <= 0;
    end
    else if (ioreq1 && ~zxwr_n && !rom_m1_access) begin
        case (zxal)
        8'h0F: sd_ch0 <= zxd;
        8'h1F: sd_ch1 <= zxd;
        8'h4F: sd_ch2 <= zxd;
        8'h5F: sd_ch3 <= zxd;
        endcase
    end
end

reg [8:0] sd_l, sd_r, sd_cnt;
always @(posedge clk) begin
    sd_l <= sd_ch0 + sd_ch1;
    sd_r <= sd_ch2 + sd_ch3;
    sd_cnt <= sd_cnt + 8'hff;
    sd_l_1bit <= sd_cnt < sd_l;
    sd_r_1bit <= sd_cnt < sd_r;
end



/* BUS CONTROLLER */
assign zxd = ioreq1 && ~zxrd_n && port_fffd? ym_io_reg_en? 8'b11111111 : ymd : 8'bzzzzzzzz;


endmodule

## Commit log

2024-08-21 wip pcbs rev.A
    [zxevo1010_main.kicad_pcb, zxevo1010_main.kicad_sch, zxevo1010_top.kicad_pcb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]
2024-08-31 wip pcb rev.A
    [zxevo1010_main.kicad_pcb, zxevo1010_main.kicad_sch]
2024-10-01 wip pcb rev.A. Main board almost done
    [zxevo1010_main.kicad_pcb, zxevo1010_main.kicad_sch, zxevo1010_top.kicad_pcb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]
2024-10-29 wip pcb rev.A (almost done)
    [zxevo1010_main.kicad_pcb, zxevo1010_main.kicad_sch, zxevo1010_top.kicad_pcb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]
2025-03-27 pcb rev.A final versions
    [zxevo1010_covers.kicad_pcb, zxevo1010_main.kicad_pcb, zxevo1010_main.kicad_sch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]
2025-04-26 add workarround to prevent baseconf crashes
    In the current state BaseConf crashing when entering into 48k basic from main ERS menu. This may or may not happens depending of Virtual Drive, Memory Lock, CPU frequency, Emu tape load settings. Crash happens in rom\page5\source\ay_printer.a80:151 (LP04 CALL BREAK_KEY). This crash caused by polling AY IO port, which isn't available on YMF288.
    [top.v]
2025-04-28 cpld_psg: fix ymf288 bus timings
    [top.v]
2025-04-29 add rev.A1 for all pcbs + release
    [zxevo1010_covers.kicad_pcb, zxevo1010_covers.kicad_sch, zxevo1010_main.kicad_pcb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]
2026-10-09 add pcb rev.A1 errata
2026-10-10 add pcb_top rev.A1 errata
